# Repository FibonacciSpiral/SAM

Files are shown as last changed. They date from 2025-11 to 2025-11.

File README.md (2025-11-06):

# SAM: Single Channel Temperature Monitor  

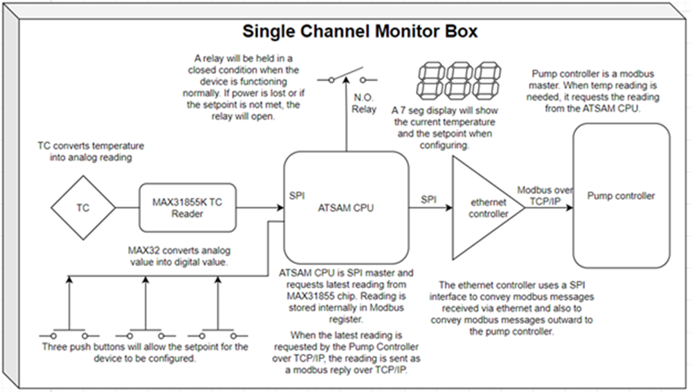
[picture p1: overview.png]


## Overview
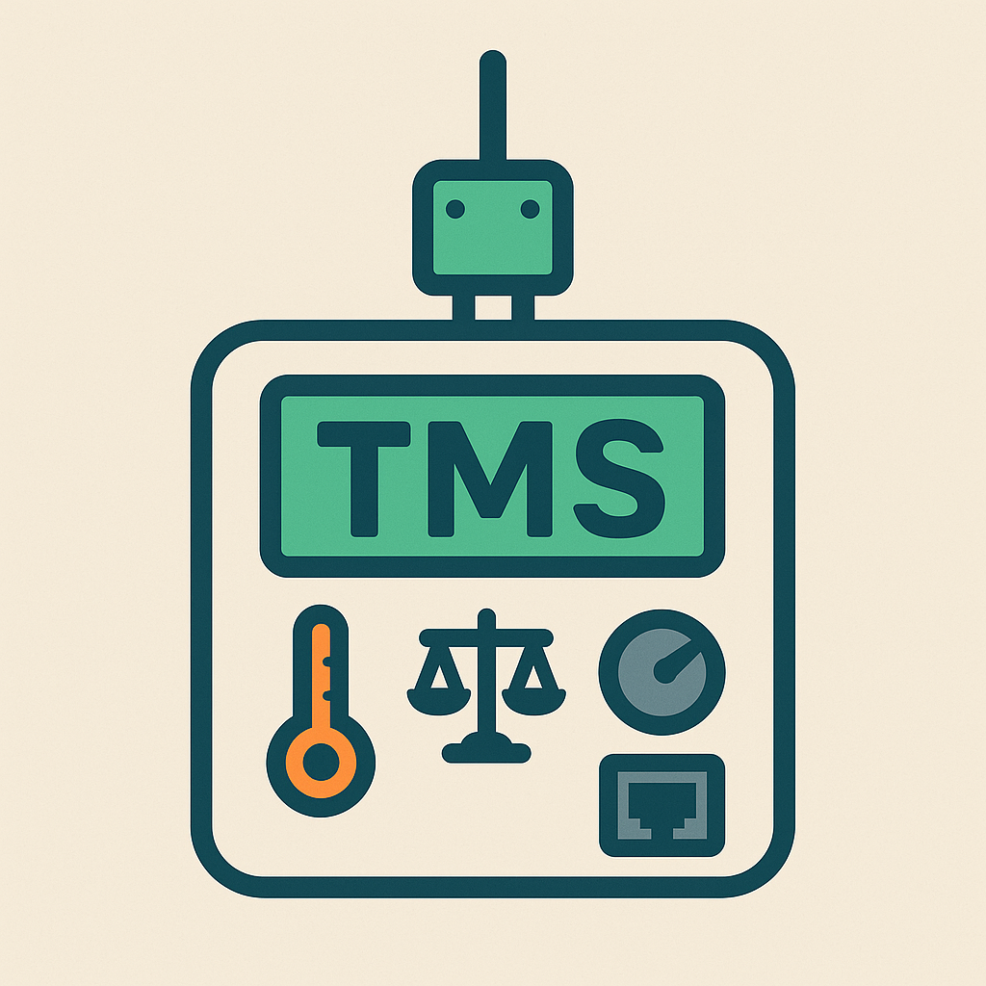
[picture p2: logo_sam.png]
SAM logo

**SAM** (Single-channel Analog Monitor) is a low-cost temperature monitor designed to enable simple temperature monitoring on a variety of TMS heaters. It continuously measures temperature using a Type K thermocouple and alerts operators when the temperature drops below a configured setpoint. The goal is to provide an inexpensive, accurate, and user-friendly thermal monitoring system suitable for industrial or laboratory environments.

## Features
- **Single-channel thermocouple monitoring** via MAX31855K  
- **Configurable setpoint** through a simple 3-button interface (Up, Down, Set)  
- **Real-time temperature display** on a 3-digit seven-segment display  
- **Alert relay output** (N.O. relay circuit) to notify external systems of low-temperature conditions  
- **Modbus TCP/IP server** for remote data retrieval  
- **Web and FTP interfaces** for configuration and resource management  
- **Persistent settings** stored in eMMC non-volatile memory  
- **FreeRTOS-based firmware** using Microchip Studio and ASF (Atmel Software Framework)  

## Hardware Architecture
### Microcontroller
- **MCU Family:** ATSAM4S (ARM Cortex-M4, 120 MHz)  
- **Development Kit:** ATSAM4S Xplained Pro  
- **Networking:** KSZ8851SNL Ethernet controller via SPI  
- **Persistent Storage:** eMMC module (or SD card for prototyping)  

### Sensor Interface
- **Thermocouple Interface Chip:** MAX31855K  
- Provides cold-junction compensation and interfaces with MCU using SPI.

### Display & Input
- **Display:** Three 7-segment LED modules showing real-time temperature or setpoint during configuration.  
- **Buttons:**  
  - **Set:** Enter/exit configuration mode.  
  - **Up/Down:** Adjust setpoint during configuration.  
- **User Feedback:** Flashing display while adjusting setpoint.  

### Relay Output
- **Type:** Normally Open (N.O.) relay  
- **Behavior:**  
  - **High signal:** Normal operation  
  - **Low signal:** Setpoint violation or sensor/power fault  

## Software Architecture
### Operating System
- **RTOS:** FreeRTOS  
- **Language:** C  
- **IDE:** Microchip Studio (Atmel Studio)  

### Modules
#### 1. Temperature Reading
- SPI-based data acquisition from MAX31855K every millisecond for 2 seconds.  
- Average of readings computed for noise reduction.  
- Filtered temperature sent to display, setpoint, and relay tasks.  

#### 2. TCP/IP Stack & Networking
- Based on FreeRTOS+TCP.  
- Includes Ethernet MAC/PHY driver for KSZ8851SNL.  
- Network settings configurable via embedded web server.  

#### 3. Web & FTP Server
- Web interface for IP configuration and device setup.  
- FTP server for uploading web resources (HTML, JS, CSS) stored in eMMC.  

#### 4. Modbus Server
- Implements **Modbus TCP** using the FreeModbus library.  
- Stores current temperature in input register (prototype uses register `1000`).  
- Allows master devices to read temperature remotely.  

#### 5. User Interface Tasks
- **Button Handler:** Interrupt-driven; sends events to state machine task.  
- **Display Driver:** Updates 7-segment display according to operating mode.  
- **Setpoint Task:** Handles setpoint logic, relay control, and NVM storage.  

#### 6. Non-Volatile Memory
- Stores:  
  - Last known setpoint  
  - Network configuration  
  - Web/FTP server resources  
- Implemented with eMMC interface.  

## Development Environment
- **Hardware:** ATSAM4S Xplained Pro + Ethernet1 Xplained Pro extension board  
- **Software:**  
  - Microchip Studio (formerly Atmel Studio)  
  - FreeRTOS  
  - ASF (Atmel Software Framework)  
  - FreeModbus library  

## Prototyping Notes
- SD card may be used as a temporary stand-in for eMMC.  
- Ensure MAX31855K wiring minimizes stray capacitance for accuracy.  
- Software debouncing implemented for all buttons (no hardware debouncing required).  
- Recommended MCU RAM: **≥128kB** (prototype uses 160kB).   

## License
This project is not licensed for redistribution or modification.  
All rights reserved © 2025 Giselle Dockterburke.

## Authors
Software Developed by Giselle Dockterburke at the Hillsboro PC in collaboration with Div Tummala who designed the hardware configuration.

---

**Revision History:**  
See the full svn revision history in the documentation folder.

---

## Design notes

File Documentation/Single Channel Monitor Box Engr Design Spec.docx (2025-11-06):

KEY DOCUMENT

DOCUMENT NO: ISSUE: 0.2

TITLE: Single Channel Monitor Box Engineering Design Specification

DOCUMENT TYPE: ENGINEERING PLAN AND DESIGN

APPROVED BY: DATE: FUNCTION:

Issue No. | 1 | 2
Date Issued | 10/01/2022 | 12/06/2022
Approved
Approved
Approved
Approved

DISTRIBUTION RECORD DOCUMENT NO:

Issue No. | Issued To | Department | Issue Date
1 | Project File Server | HB PC Engineering
2 | Project File Server | HB PC Engineering | 12/06/2022

REVISIONS DOCUMENT NO:

Change No. | Description | Date | New Issue
1 | Initial Version | 10/01/2022 | 1
2 | New Revision | 12/06/2022 | 2
3
4
5

CONTENTS

1. INTRODUCTION
2. RELATED DOCUMENTS
3. OVERVIEW OF DESIGN
4. MCU AND DEVELOPMENT ENVIRONMENT
5. SOFTWARE MODULES
  5.1. A/D CONVERSION FOR THERMOCOUPLE
  5.2. TCP/IP STACK AND NETWORK INTERFACE
    5.2.1. SETTING UP TCP/IP STACK
    5.2.2. ADDING WEB SERVER INTERFACE
    5.2.3. ADDING FTP SERVER
  5.3. MCU AS MODBUS SERVER
  5.4. USER INTERFACE
    5.4.1. BUTTON HANDLER TASK
    5.4.2. 7 SEGMENT TEMPERATURE DISPLAY
  5.5. N.O. RELAY CIRCUIT
  5.6. NON VOLATILE MEMORY
6. CONCLUSION

The single channel monitor box is a low cost way to monitor the temperature of a FLEX heater. It works in series with a FLEX heater solution. It provides a simple three button interface to allow the customer to configure one setpoint. If the current temperature is greater than the setpoint, then that is considered normal. If it’s less than the setpoint, that will generate an alert. The device has a relay circuit that can inform another device of either a setpoint violation or loss of power.

The goal is to design a device that is easy to use, inexpensive, and accurate. Our competitors have such devices so we would also like to consider what these devices are like and to try to make something more desirable.

This document will cover the full design of the device by breaking it down into its parts. Every software module will be detailed, and wiring diagrams will be provided. This document should provide enough information that any developer could use it to design a prototype.

Device datasheet for ATSAM4S family. (https://ww1.microchip.com/downloads/aemDocuments/documents/OTH/ProductDocuments/DataSheets/Atmel-11100-32-bitCortex-M4-Microcontroller-SAM4S_Datasheet.pdf)

Single Channel Monitor Box Marketing Spec (https://onevirtualoffice.sharepoint.com/:x:/r/sites/SEM_EDW_GLO_SMARTTMSHUB/Shared%20Documents/Organizational/Former%20Employee%20Files/Div%20Tummala%20Files/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)

Single Channel Monitor Box Scheduling Timeline (https://onevirtualoffice-my.sharepoint.com/:w:/g/personal/giselle_dockterburke_edwardsvacuum_com/Ef9K2PLwa2lMu9C9id5GHWMBOkV-AMopPGUyMcQtvdPQiQ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)

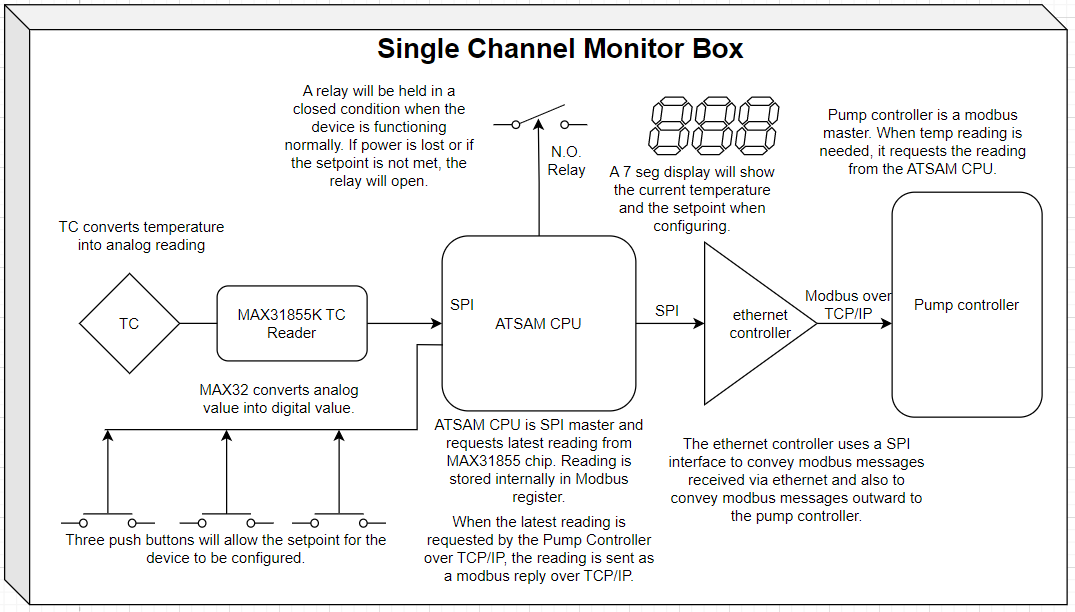
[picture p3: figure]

The single channel monitor box will monitor a single thermocouple. Temperature readings are converted by a MAX31855K chip and received by the MCU via SPI. Readings are stored internally until a modbus master device requests them. The requests are received through an ethernet port that communicates modbus over TCP/IP. The monitor box acts as a modbus server, only storing the latest reading in an internal register.

Whatever the current temperature is, that is displayed on the device’s seven segment display. The device has only 1 setpoint that can be configured using the three push buttons provided. While configuring, the display will show the user the setpoint temperature as they are selecting it.

If the setpoint is violated (if the current reading is less than the setpoint), then a relay will open, allowing an interfacing device to be notified of the problem.

4. Mcu and Development environment

The microcontroller family selected for this project is the ATSAM4S family of microcontrollers. The full specs for this family are found in their device datasheet linked in the related documents section, but in summary, it is a 32 bit ARM Cortex-M4 processor with an internal clock speed of 120 MHz (ample speed for this application), with a good selection of peripherals and multiple packages ranging from 48 I/O pins and 100 I/O pins.

Here is a complete list of the specs for this MCU:

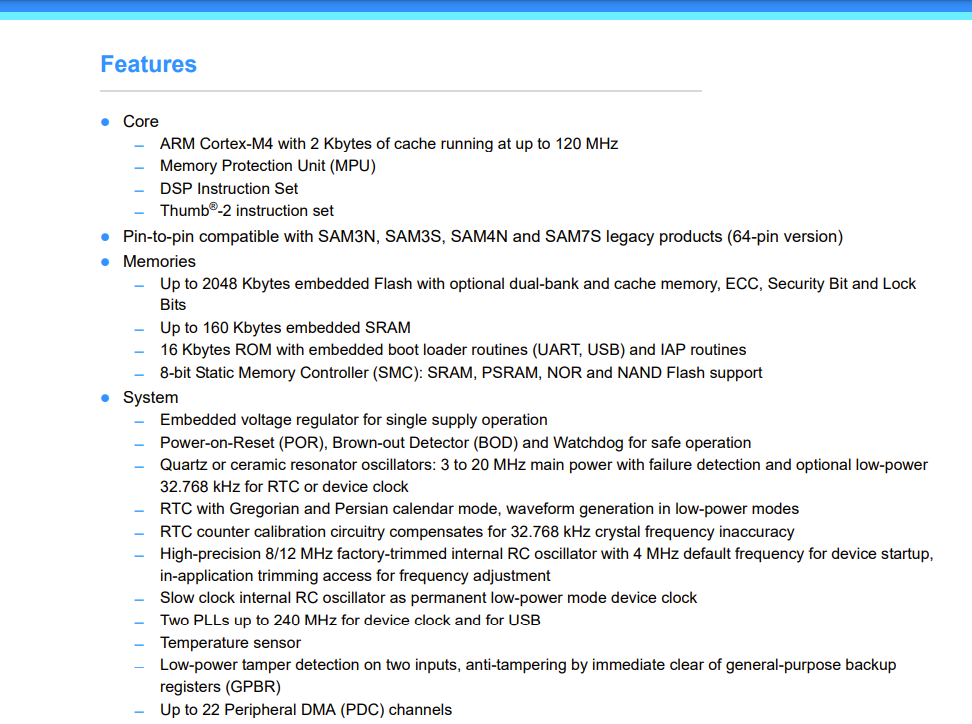
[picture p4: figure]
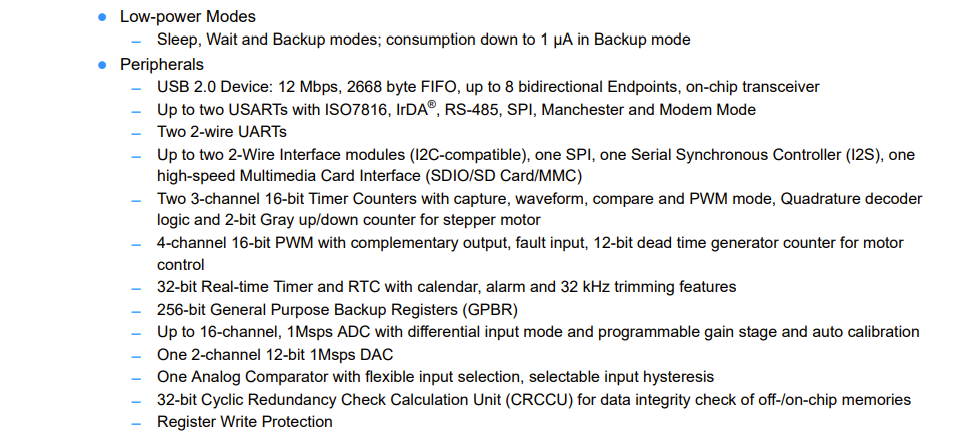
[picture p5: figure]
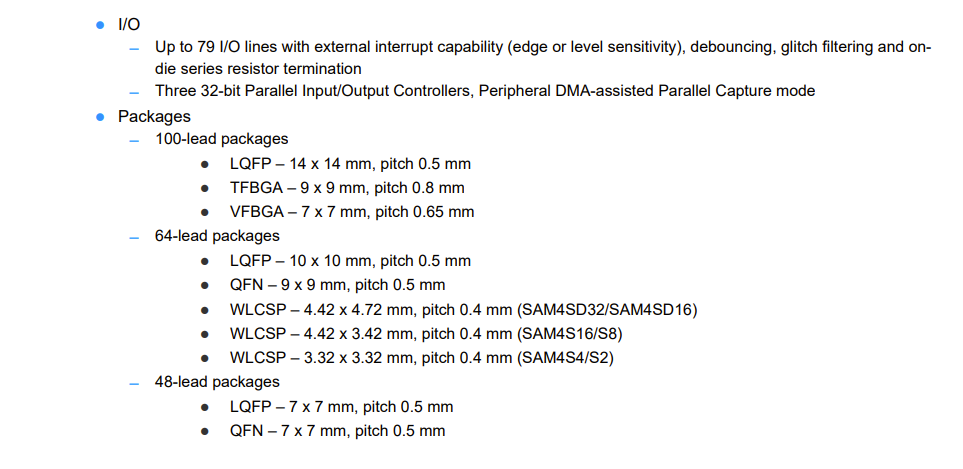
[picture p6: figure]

The development board selected for prototyping is the ATSAM4S Xplained Pro kit.

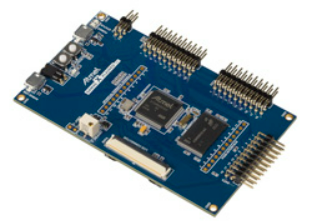
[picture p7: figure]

Here is a link to the product and its description. ATSAM4S Development Board (https://www.microchip.com/en-us/development-tool/ATSAM4S-XPRO)

The integrated development environment this MCU uses is Microchip studio (formerly Atmel Studio). The software itself will run in a FreeRTOS operating system. The software will be written in C and debugging is easily accomplished over USB with Microchip studio. The development board comes preloaded with a debugging module that makes the process very simple. The ASF wizard in Microchip studio can be used to setup FreeRTOS and many of the low level drivers like the Power Management Controller and SPI.

5. SOFTWARE MODULES

5.1. TEMPERATURE READING WITH MAX31855K

The MAX31855 chip provides a convenient method to read temperatures using a thermocouple. This chip comes in different varieties to suit different types of thermocouples. Since this application will use type K thermocouples, the MAX31855K will be used.

Essentially, the chip handles all the complexity involved with cold junction compensation that normally has to be handled when reading thermocouples. The chip generates readings frequently and they only need to be clocked out by a master SPI device.

In this application, the MAX TC reader will be read once per millisecond for 2 whole seconds. All of the readings will be averaged to provide a software based noise filter. The temperature is read by asserting the devices chip select, clocking out the bits, and then interpreting the current temperature using the data format provided by the MAX31855 datasheet.

Once a temperature is averaged and calculated, it will be sent to other tasks for processing. For example the display driver will be a recipient since it will need to know what to display, and the setpoint handler will need it since it will always be monitoring the current temperature for an alert scenario.

5.2. TCP/IP STACK AND NETWORK INTERFACE

    5.2.1 SETTING UP TCP/IP STACK

The ethernet module provides the hardware capability for an ethernet connection, but it also needs supporting software in FreeRTOS. This design will use the TCP/IP stack native to FreeRTOS, however there are other components to consider in the software framework. Here is a visual representation of the structure that needs to be implemented:

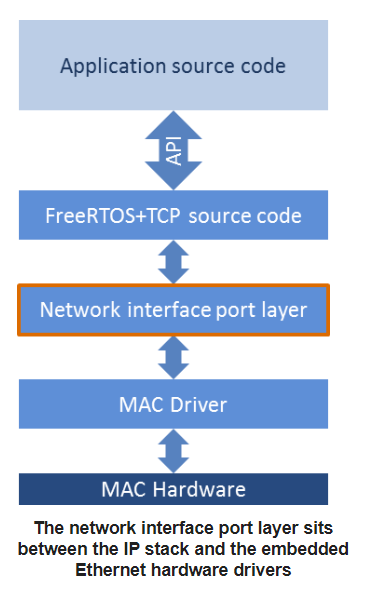
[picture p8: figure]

At the bottom of the stack is the ethernet chip itself. It is known as the MAC. On top of that is the MAC Driver. This is also known as the PHY or Physical Layer Transceiver. It provides the interface between the hardware and the network interface port layer.

In this application the PHY can be easily obtained from the ASF wizard in Microchip studio. Whatever ethernet chip is being used, ASF wizard can likely provide it as a component in the project. For the prototype, we are using the KSZ8851SNL which has a PHY driver available in ASF wizard.

If for some reason, the PHY is not provided in Microchip studio, then one can likely be located on Github. The worst case scenario is one would need to be written manually. This would simply consume time; it’s still very feasible.

The next layer is the network interface port layer. This essentially provides the glue that binds the TCP/IP stack to the PHY.

- The network interface port layer must provide a function called xNetworkInterfaceInitialise() (https://www.freertos.org/FreeRTOS-Plus/FreeRTOS_Plus_TCP/Embedded_Ethernet_Porting.html) that initializes the MAC driver.
- The network interface port layer must provide a function called xNetworkInterfaceOutput() (https://www.freertos.org/FreeRTOS-Plus/FreeRTOS_Plus_TCP/Embedded_Ethernet_Porting.html) that sends data received from the embedded TCP/IP stack to the Ethernet MAC driver for transmission.
- The network interface port layer must send packets received from the Ethernet MAC driver to the TCP/IP stack by calling xSendEventStructToIPTask() (https://www.freertos.org/FreeRTOS-Plus/FreeRTOS_Plus_TCP/API/xSendEventStructToIPTask.html).

What’s nice about the TCP/IP stack in FreeRTOS is it allows the code to be highly portable. The only code that would need to be changed in the event of changing ethernet chips is the PHY and the network interface port layer.

Here is a link to more information on setting up the TCP/IP stack and hardware interface:

Porting FreeRTOS-Plus-TCP to a Different Microcontroller (https://www.freertos.org/FreeRTOS-Plus/FreeRTOS_Plus_TCP/Embedded_Ethernet_Porting.html)

    5.2.2 ADDING WEB SERVER INTERFACE

A requirement of the project is for the IP address to be configurable. In order to meet this requirement, the monitor box will host a local web server that will allow the IP address and other relevant network settings to be modified.

The host name of the server can be entered into any address bar and as long as there is a direct network connection between the monitor box and a host computer, then the web service will display the interface over http.

From a high level, the interface will be simple and allow for easy device customization.

From a design perspective, the web server functionality will be added by porting an existing example for the ATSAM4E line of devices. The main difference between ATSAM4E and ATSAM4S family of microcontrollers is that ATSAM4E has a built in MAC. Since we are adding an external MAC (the ethernet chip), this example should work on ATSAM4S, provided the TCP/IP stack is ported successfully.

Here is a link to the ATSAM4E http example (and other examples too).

FreeRTOS-Plus-TCP and FreeRTOS-Plus-FAT Examples (https://www.freertos.org/FreeRTOS-Plus/FreeRTOS_Plus_TCP/TCPIP_FAT_Examples_Atmel_SAM4E.html)

    5.2.3 ADDING FTP SERVER

An FTP server will be implemented alongside the web server interface since it would be necessary to have a way to place the web resources onto the device. The ATSAM4E example mentioned above essentially bundles the web server with the ftp server since they are so similar. If that example is implemented correctly, then the FTP server will be added alongside the web interface without additional effort.

5.3. MCU AS MODBUS SERVER

A modbus server is a device that accepts commands from a modbus master. Modbus is an application layer protocol that sits on top of the TCP/IP stack.

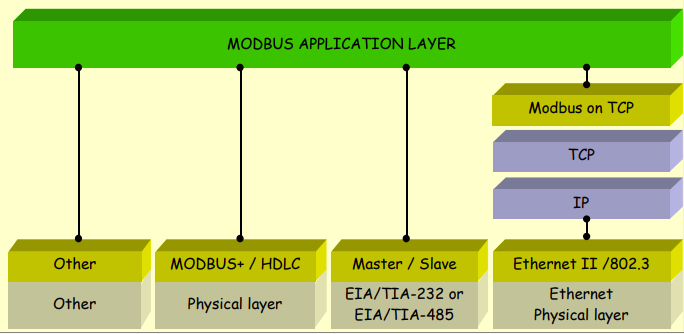
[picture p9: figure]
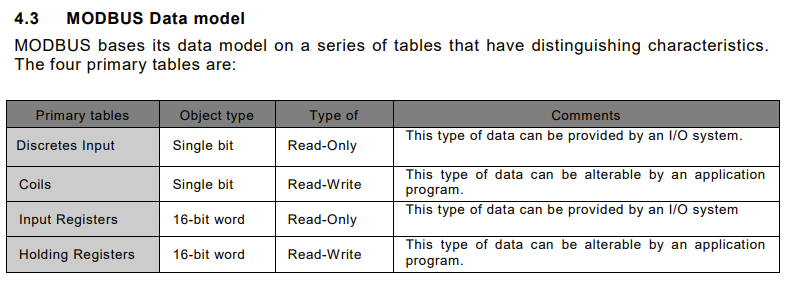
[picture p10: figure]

The best way to add modbus as an application layer protocol is to port an existing library that is tried and true. An excellent option is freeModbus. This library is made for embedded systems, it is well written, and is made for porting. They provide TCP implementations and RTU/ASCII. This could be useful for another project in the future that also uses modbus but not the TCP version. The code could easily be configured to work with TCP or Serial.

In order to add freemodbus to an application, one would download the library from their website. There is a port file that shows function stubs for functions that must be implemented. The only ones needed for the TCP port are labeled under the TCP section.

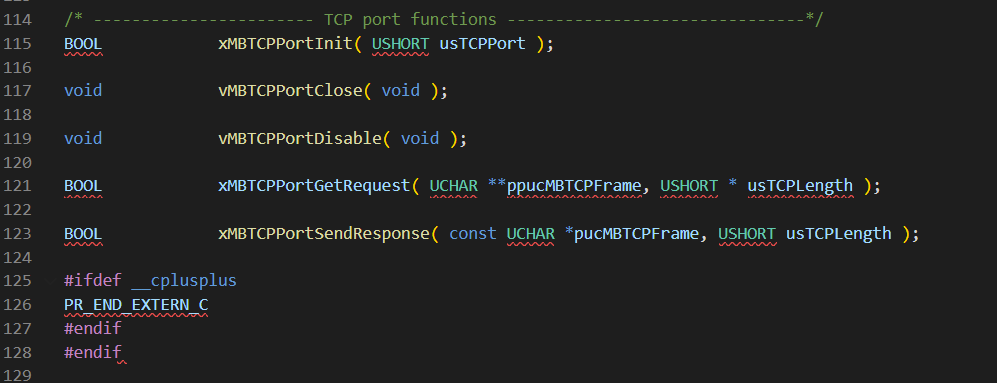
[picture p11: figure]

The xMBTCPPortInit function is responsible for launching a connection listening task. It’s only goal is to listen for clients. This task will also only handle one connection at a time so if a second client tries to connect, the current connection is severed.

The vMBTCPPortClose function completely closes down the modbus interface by killing any active connection and shutting down the listening socket.

The MBTCPPortDisable function will only shut down any active connection.

xMBTCPPortGetRequest is a function used to receive messages from the remote client. This function stub just provides a pointer for one to copy an address to. This address should point to the most recently received data along with the number of bytes. In the application, the connection instance will be responsible for reading data from the client and sending the address of the data over in a queue.

Then, once free modbus is fully implemented, it can be tested with a modbus master simulator like qModMaster. We use this for testing the TMS controller’s modbus interface.

The only additional work is to decide which input register should hold the current temperature. I will use 1000 for prototyping. If any other parameters should be available via modbus, we would just dedicate an input register, or holding register if the master is allowed to write, and keep it updated that way the values are always available.

5.4. USER INTERFACE

The user interface consists of three push buttons and 3 seven-segment display modules. There’s an up button, a down button, and a set button. The display modules always reflect the current temperature reading. The only other function of the display is to allow a single setpoint to be set. To change the setpoint, the set button should be pushed once. At this point, the display will slowly flash indicating that the setpoint may be adjusted. Pushing the set button again will save whatever setpoint they had selected using the up and down buttons. The device ceases to blink and shows the current temperature, signaling that normal operation has resumed.

5.4.1. BUTTON HANDLER TASK

An ISR will be used to monitor the input on the buttons asynchronously. Those inputs will be sent to a state machine task that will then send any requests to the control task, such as changing the display or updating a setpoint.

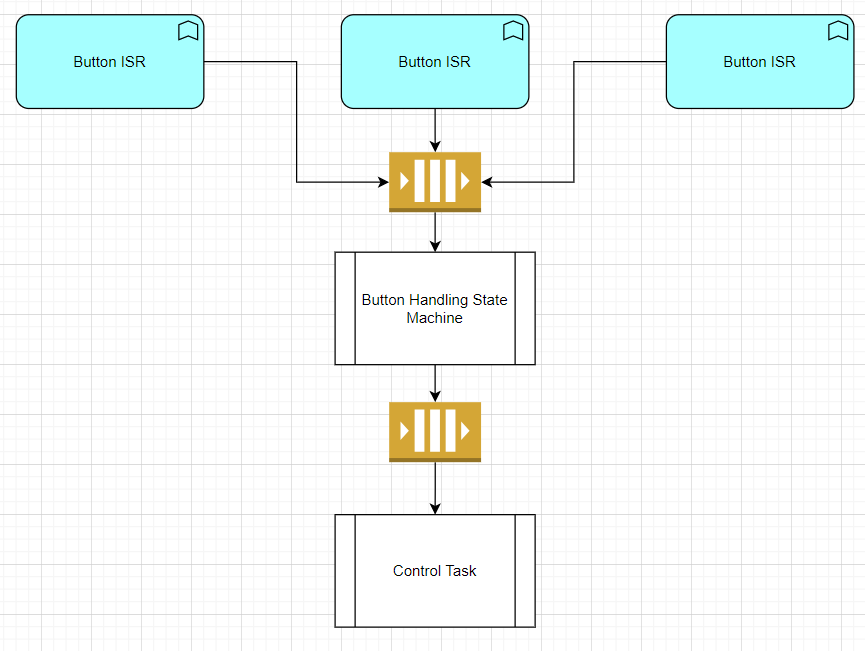
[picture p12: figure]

5.4.2. 7 SEGMENT TEMPERATURE DISPLAY

The display logic will follow a state machine behavior as outlined below:

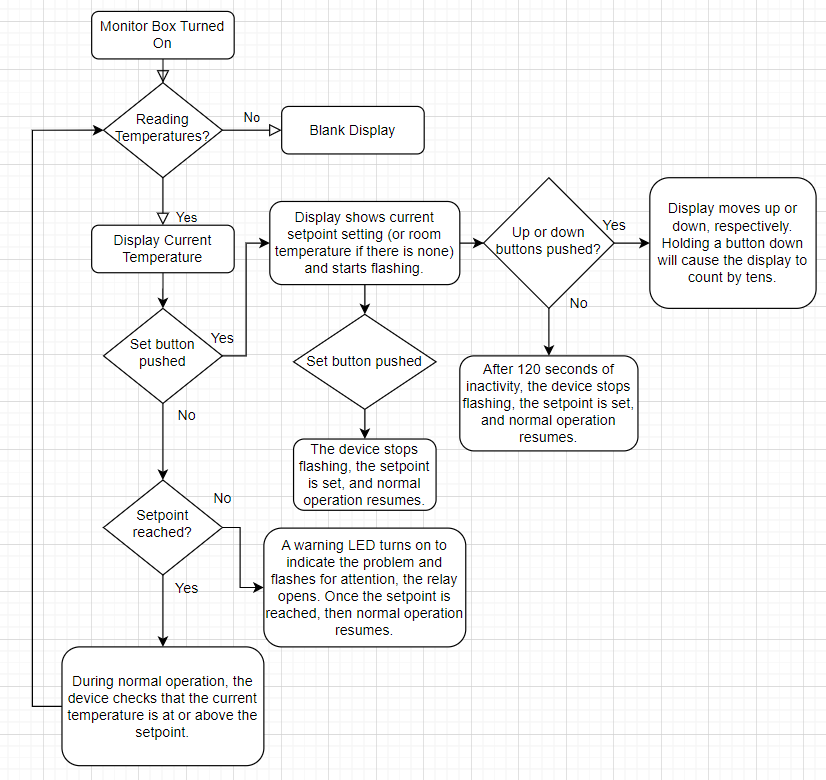
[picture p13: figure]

5.5. N.O. RELAY CIRCUIT

This is probably the most simple software module. If the monitor box is on but either cannot read temperatures or if the setpoint is violated, then a digital low signal will be applied to a digital output. If everything is normal, then a digital high signal will be output from the same GPIO.

The setpoint handling itself should have its own task where the current temperature is relayed to it every time it comes in via a queue. This task will be responsible for monitoring the temperature and will follow a state machine style architecture to handle the state of the relay. This task should also be responsible for storing the setpoint in non-volatile memory when it is selected, and for retrieving the last known setpoint on initialization.

5.6 NON VOLATILE MEMORY

There is a need for persistent memory in this project. The setpoint must be remembered between power cycles, and in order to implement a web server, there must be a file system to store web resources such as http files, javascript files, or css files. Not only that, but the network settings must be remembered between power cycles as well. In order to address this problem in the most cost effective way, this project will use an eMMC module. eMMC stands for embedded multi-media card. It is almost identical to an SD card but it is non removable and significantly less expensive.

On the prototype, the wiring for the project is exceedingly simple, given that an extension board for the ATSAM4S development board exists. The extension is the Ethernet1 Xplained Pro board and for the prototype, it plugs into EXT1, although it should be compatible on any of the boards extensions. (No wiring diagram needed).

6. CONCLUSION

This is the plan for the design of the software. There are still some lingering questions. Which modbus register should the current temperature reside at? What other variables would be good to make accessible via modbus? Should the web server be HTTP or HTTPS? HTTP would be faster, but obviously HTTPS is encrypted so it would be more secure. Is security of great importance here? Or is speed the priority?

There are other considerations concerning the hardware also. Technically, any CPU may be used for this project as long as it is in the ATSAM4S family. However, RAM must be considered. I would recommend to those developing the hardware to choose a CPU with no less than 128kB of RAM. The application will be developed using a CPU with 160kB so a CPU with that amount would be most likely to work successfully without additional troubleshooting.

One consideration is the eMMC module. For prototyping, an SD card and SD card reader will be used, but it would be ideal to be able to prototype with an eMMC module as well. When a module is selected, it is important that it is tested for compatibility with the software driver. It is the case that certain modules are compatible while others are not, depending on the interface that is used.

Also, the MAX31855 module is highly sensitive to stray capacitance so when designing the layout of the PCB, that must be considered, otherwise the temperature readings may not be very accurate. The way the chip reads temperature is based on voltages so it is essential that stray inductance or capacitance don’t disrupt those readings.

One more thing to add is that the buttons will be debounced entirely in software so there is no need to add any additional hardware for debouncing.

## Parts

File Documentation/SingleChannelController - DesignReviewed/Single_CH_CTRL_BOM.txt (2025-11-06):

Qty Value                    Device                   Package                        Parts                                                                                                                                                                                 Description                                                                                                                                                                                                  ARROW_PART_NUMBER   ARROW_PRICE-STOCK                                                                      DESCRIPTION                                                                                                                                                                                                  HEIGHT   MANUFACTURER_NAME  MANUFACTURER_PART_NUMBER MOUSER_PART_NUMBER   MOUSER_PRICE-STOCK                                                                                                     MOUSER_TESTING_PART_NUMBER MOUSER_TESTING_PRICE-STOCK
1   0.1uF                    B32922X2104K000          B32922X_(18_X_5)               C1                                                                                                                                                                                    EMI Suppression Capacitors, 0.1uF, 275Vrms AC, 5m(W) x 10.5m(H) x 18m(L)                                                                                                                                     B32922X2104K000     https://www.arrow.com/en/products/b32922x2104k000/epcos-tdk?region=nac                 EMI Suppression Capacitors, 0.1uF, 275Vrms AC, 5m(W) x 10.5m(H) x 18m(L)                                                                                                                                     10.5mm   TDK                B32922X2104K000          871-B32922X2104K000  https://www.mouser.co.uk/ProductDetail/EPCOS-TDK/B32922X2104K000?qs=TuK3vfAjtkWDVip5zaCELA%3D%3D                                                                            
2   0.1uF                    C0402C104K4RACTU         C0402                          C16, C17                                                                                                                                                                              SMD Comm X7R, Ceramic, 0.1 uF, 10%, 16 VDC, 40 VDC, 125C, -55C, X7R, SMD, MLCC, Temperature Stable, Class II, 10 % , 5 GOhms, 1.21 mg, 0402, 1mm, 0.5mm, 0.5mm, 0.3mm, 0.3mm, 10000, 78  Weeks, 80           C0402C104K4RACTU    https://www.arrow.com/en/products/c0402c104k4ractu/kemet-corporation?region=nac        SMD Comm X7R, Ceramic, 0.1 uF, 10%, 16 VDC, 40 VDC, 125C, -55C, X7R, SMD, MLCC, Temperature Stable, Class II, 10 % , 5 GOhms, 1.21 mg, 0402, 1mm, 0.5mm, 0.5mm, 0.3mm, 0.3mm, 10000, 78  Weeks, 80           0.55mm   KEMET              C0402C104K4RACTU         80-C0402C104K4R      https://www.mouser.co.uk/ProductDetail/KEMET/C0402C104K4RACTU?qs=DBJr%252BvBUjU54jK7d4uAeew%3D%3D                                                                           
1   0.1uF                    C0805C104K5RAC7411       CAPC2012X88N                   C28                                                                                                                                                                                   Cap Ceramic 0.1uF 50V X7R 10% Pad SMD 0805 125C T/R                                                                                                                                                          C0805C104K5RAC7411  https://www.arrow.com/en/products/c0805c104k5rac7411/kemet-corporation                 Cap Ceramic 0.1uF 50V X7R 10% Pad SMD 0805 125C T/R                                                                                                                                                          0.88mm   KEMET              C0805C104K5RAC7411       80-C0805C104K5RACLR  https://www.mouser.co.uk/ProductDetail/KEMET/C0805C104K5RAC7411?qs=jbRM9o5BbzPcVXF0wW9AYg%3D%3D                                                                             
1   0.5A Slow Blow           RST_500_AMMO             RST500AMMO                     F1                                                                                                                                                                                    Fuse Micro Slow Blow Acting 0.5A 250V Radial 8.35 X 4 X 8.2mm Ammo CCC/PSE/SEMKO/VDE/cULus                                                                                                                   RST 500 AMMO        https://www.arrow.com/en/products/rst500-ammo/bel-group                                Fuse Micro Slow Blow Acting 0.5A 250V Radial 8.35 X 4 X 8.2mm Ammo CCC/PSE/SEMKO/VDE/cULus                                                                                                                   7.9mm    Stewart Connector  RST 500 AMMO             530-RST500AMMO       https://www.mouser.co.uk/ProductDetail/Bel-Fuse/RST-500-AMMO?qs=MvPYbBWWJyujgJzBtIxlxw%3D%3D                                                                                
1   100                      ERJ-PA3F1000V            ERJP03_PA3_(0603)              R29                                                                                                                                                                                   ERJPA3 Resistors 0.25W 0603 100R 1% Panasonic ERJPA3 Series Thick Film Surface Mount Resistor 0603 Case 100 +/-1% 0.25W +/-100ppm/C                                                                                                                                                                                     ERJPA3 Resistors 0.25W 0603 100R 1% Panasonic ERJPA3 Series Thick Film Surface Mount Resistor 0603 Case 100 +/-1% 0.25W +/-100ppm/C                                                                          0.55mm   Panasonic          ERJ-PA3F1000V            667-ERJ-PA3F1000V    https://www.mouser.com/Search/Refine.aspx?Keyword=667-ERJ-PA3F1000V                                                                                                         
1   1000pF                   C4520X7R3D102K130KA      C4520_COMMERCIAL               C18                                                                                                                                                                                   MULTILAYER CERAMIC CHIP CAPACITORS, 4520, Commercial grade, general (Up to 75V)                                                                                                                              C4520X7R3D102K130KA https://www.arrow.com/en/products/c4520x7r3d102k130ka/tdk                              MULTILAYER CERAMIC CHIP CAPACITORS, 4520, Commercial grade, general (Up to 75V)                                                                                                                              1mm      TDK                C4520X7R3D102K130KA      810-C4520X7R3D102K   https://www.mouser.co.uk/ProductDetail/TDK/C4520X7R3D102K130KA?qs=NRhsANhppD%2FmDDEB06mgKg%3D%3D                                                                            
31  10K                      CRCW040210K0FKEDC        RESC1005X35N                   R30, R31, R34, R114, R117, R120, R123, R126, R129, R132, R135, R138, R141, R144, R147, R150, R153, R156, R159, R162, R165, R168, R171, R174, R177, R180, R183, R186, R189, R192, R195 VISHAY - CRCW040210K0FKEDC - RES, THICK FILM, 10K, 0.063W, 0402                                                                                                                                              CRCW040210K0FKEDC   https://www.arrow.com/en/products/crcw040210k0fkedc/vishay?region=nac                  VISHAY - CRCW040210K0FKEDC - RES, THICK FILM, 10K, 0.063W, 0402                                                                                                                                              0.35mm   Vishay             CRCW040210K0FKEDC        71-CRCW040210K0FKEDC https://www.mouser.co.uk/ProductDetail/Vishay-Dale/CRCW040210K0FKEDC?qs=E3Y5ESvWgWPiNLcGzwCGPg%3D%3D                                                                        
1   10K                      RC0402FR-0710KP          RESC1005X40N                   R59                                                                                                                                                                                   YAGEO - RC0402FR-0710KP - SMD Chip Resistor, 10 kohm, +/- 1%, 62.5 mW, 0402 [1005 Metric], Thick Film, General Purpose                                                                                       RC0402FR-0710KP     https://www.arrow.com/en/products/rc0402fr-0710kp/yageo?region=nac                     YAGEO - RC0402FR-0710KP - SMD Chip Resistor, 10 kohm, +/- 1%, 62.5 mW, 0402 [1005 Metric], Thick Film, General Purpose                                                                                       0.4mm    KEMET              RC0402FR-0710KP          603-RC0402FR-0710KP  https://www.mouser.co.uk/ProductDetail/YAGEO/RC0402FR-0710KP?qs=oypCK0zG325Ov8hhvMZZMg%3D%3D                                                                                
2   18pF                     04025U180FAT2A           CAPC1005X56N                   C3, C4                                                                                                                                                                                AVX - 04025U180FAT2A - CAP, MLCC, C0G / NP0, 18PF, 50V, 0402                                                                                                                                                 04025U180FAT2A      https://www.arrow.com/en/products/04025u180fat2a/avx                                   AVX - 04025U180FAT2A - CAP, MLCC, C0G / NP0, 18PF, 50V, 0402                                                                                                                                                 0.56mm   AVX                04025U180FAT2A           581-04025U180FAT2A   https://www.mouser.co.uk/ProductDetail/AVX/04025U180FAT2A/?qs=lqAf%2FiVYw9iIZ7dTMzpUiQ%3D%3D                                                                                
1   1M                       CHV0805-FX-1004EST       RESC2012X60N                   R57                                                                                                                                                                                   ResHV ST 0805 1M 1% 0.125W TCR100                                                                                                                                                                                                                                                                                       ResHV ST 0805 1M 1% 0.125W TCR100                                                                                                                                                                            0.6mm    Bourns             CHV0805-FX-1004EST       652-CHV0805FX1004EST https://www.mouser.co.uk/ProductDetail/Bourns/CHV0805-FX-1004EST?qs=QNEnbhJQKvb69hgGpv9kmQ%3D%3D                                                                            
29  220                      CR0402-JW-221GLF         RESC1005X40N                   R55, R56, R116, R119, R122, R125, R128, R131, R134, R137, R140, R143, R146, R149, R152, R155, R158, R161, R164, R167, R170, R173, R176, R179, R182, R188, R191, R194, R197            Thick Film Resistors - SMD 220 OHM 5%                                                                                                                                                                        CR0402-JW-221GLF    https://www.arrow.com/en/products/cr0402-jw-221glf/bourns                              Thick Film Resistors - SMD 220 OHM 5%                                                                                                                                                                        0.4mm    Bourns             CR0402-JW-221GLF         652-CR0402JW-221GLF  https://www.mouser.com/Search/Refine.aspx?Keyword=652-CR0402JW-221GLF                                                                                                       
1   220uF                    860010473011             CAPPRD250W52D630H1250          C2                                                                                                                                                                                    Wurth Elektronik 220uF 25 V dc Aluminium Electrolytic Capacitor, WCAP-ATG8 Series 2000h 6.3 (Dia.) x 11mm                                                                                                                                                                                                               Wurth Elektronik 220uF 25 V dc Aluminium Electrolytic Capacitor, WCAP-ATG8 Series 2000h 6.3 (Dia.) x 11mm                                                                                                    12.5mm   Wurth Elektronik   860010473011             710-860010473011     https://www.mouser.co.uk/ProductDetail/Wurth-Elektronik/860010473011?qs=0KOYDY2FL2%252Bm07azjhm%2FHQ%3D%3D                                                                  
2   22pF                     CBR04C220J5GAC           CBR04C                         C19, C20                                                                                                                                                                              CBR-SMD RF C0G, Ceramic, 22 pF, 5%, 50 VDC, 125 VDC, 125C, -55C, C0G, SMD, Fixed, RF, Ultra High Q, Low ESR, Class I, 0.12 % , 10 GOhms, 840, 1.4 mg, 0402, 1mm, 0.5mm, 0.5mm, 0.25mm, 10000, 78  Weeks, 120 CBR04C220J5GAC      https://www.arrow.com/en/products/cbr04c220j5gac/kemet-corporation?region=nac          CBR-SMD RF C0G, Ceramic, 22 pF, 5%, 50 VDC, 125 VDC, 125C, -55C, C0G, SMD, Fixed, RF, Ultra High Q, Low ESR, Class I, 0.12 % , 10 GOhms, 840, 1.4 mg, 0402, 1mm, 0.5mm, 0.5mm, 0.25mm, 10000, 78  Weeks, 120 mm       KEMET              CBR04C220J5GAC           80-CBR04C220J5G      https://www.mouser.co.uk/ProductDetail/KEMET/CBR04C220J5GAC?qs=BjUX18ghZXi0endstTtQyQ%3D%3D                                                                                 
28  2K2                      CR0402-FX-2201GLF        RESC1005X37N                   R115, R118, R121, R124, R127, R130, R133, R136, R139, R142, R145, R148, R151, R154, R157, R160, R163, R166, R169, R172, R175, R178, R181, R184, R187, R190, R193, R196                BOURNS - CR0402-FX-2201GLF - RES, 2K2, 1%, 0402, THICK FILM                                                                                                                                                  CR0402-FX-2201GLF   https://www.arrow.com/en/products/cr0402-fx-2201glf/bourns?region=nac                  BOURNS - CR0402-FX-2201GLF - RES, 2K2, 1%, 0402, THICK FILM                                                                                                                                                  0.37mm   Bourns             CR0402-FX-2201GLF        652-CR0402FX-2201GLF https://www.mouser.co.uk/ProductDetail/Bourns/CR0402-FX-2201GLF?qs=JflQ4L8so%2FvNNp%252Bb%2FjYwIg%3D%3D                                                                     
28  2SA1362-GR,LF            2SA1362-GR,LF            2SA1362GRLF                    IC27, IC28, IC29, IC30, IC31, IC32, IC33, IC34, IC35, IC36, IC37, IC38, IC39, IC40, IC41, IC42, IC43, IC44, IC45, IC46, IC47, IC48, IC49, IC50, IC51, IC52, IC53, IC54                PNP Transistor, VCEO=-15V, IC=-0.8A, hFE=200 to 400 in SOT-346   (S-Mini) package                                                                                                                                                                                                                                       PNP Transistor, VCEO=-15V, IC=-0.8A, hFE=200 to 400 in SOT-346   (S-Mini) package                                                                                                                            1.4mm    Toshiba            2SA1362-GR,LF            757-2SA1362-GRLF     https://www.mouser.co.uk/ProductDetail/Toshiba/2SA1362-GRLF?qs=bZr6mbWTK5kLJ9eOLrMUZg%3D%3D                                                                                 
1   3.01K                    RC0402FR-073K01L         RESC1005X40N                   R58                                                                                                                                                                                   Thick Film Resistors - SMD 3.01K OHM 1%                                                                                                                                                                      RC0402FR-073K01L    https://www.arrow.com/en/products/rc0402fr-073k01l/yageo                               Thick Film Resistors - SMD 3.01K OHM 1%                                                                                                                                                                      0.4mm    KEMET              RC0402FR-073K01L         603-RC0402FR-073K01L https://www.mouser.com/Search/Refine.aspx?Keyword=603-RC0402FR-073K01L                                                                                                      
3   39                       CR0402-FX-39R0GLF        RESC1005X40N                   R32, R33, R35                                                                                                                                                                         Thick Film Resistors - SMD 39 OHM 1%                                                                                                                                                                                                                                                                                    Thick Film Resistors - SMD 39 OHM 1%                                                                                                                                                                         0.4mm    Bourns             CR0402-FX-39R0GLF        652-CR0402FX-39R0GLF https://www.mouser.com/Search/Refine.aspx?Keyword=652-CR0402FX-39R0GLF                                                                                                      
2   4.7K                     CR0402-FX-4701GLF        RESC1005X40N                   R60, R61                                                                                                                                                                              Thick Film Resistors - SMD 4.7K OHM 1%                                                                                                                                                                                                                                                                                  Thick Film Resistors - SMD 4.7K OHM 1%                                                                                                                                                                       0.4mm    Bourns             CR0402-FX-4701GLF        652-CR0402FX-4701GLF https://www.mouser.co.uk/ProductDetail/Bourns/CR0402-FX-4701GLF?qs=ePR1ZvdkOKK%252Bab9lx6TEtw%3D%3D                                                                         
4   49.9                     ERJ-U02F49R9X            ERJS02_U02_(0402)              R51, R52, R53, R54                                                                                                                                                                    Anti-Sulfurated Thick Film Chip Resistor, 0402, 0.1W                                                                                                                                                                                                                                                                    Anti-Sulfurated Thick Film Chip Resistor, 0402, 0.1W                                                                                                                                                         0.4mm    Panasonic          ERJ-U02F49R9X                                                                                                                                                                                                             
2   5055323-9                5055323-9                50553239                       U2, U3                                                                                                                                                                                AMP - TE CONNECTIVITY - 5055323-9 - POWER TAB, ASSEMBLY, WITH SCREW                                                                                                                                          5055323-9           https://www.arrow.com/en/products/5055323-9/te-connectivity                            AMP - TE CONNECTIVITY - 5055323-9 - POWER TAB, ASSEMBLY, WITH SCREW                                                                                                                                          7.2898mm TE Connectivity    5055323-9                571-5055323-9        https://www.mouser.co.uk/ProductDetail/TE-Connectivity/5055323-9?qs=Ko7makLHeK5WcBiq4KwKgA%3D%3D                                                                            
2   74HC14D                  74HC14D                  SOIC127P600X175-14N            IC2, IC18                                                                                                                                                                             Inverter Schmitt Trigger 6-Element CMOS 14-Pin SOIC T/R                                                                                                                                                      74HC14D             https://www.arrow.com/en/products/74hc14d/toshiba?region=nac                           Inverter Schmitt Trigger 6-Element CMOS 14-Pin SOIC T/R                                                                                                                                                      1.75mm   Toshiba            74HC14D                  757-74HC14D          https://www.mouser.co.uk/ProductDetail/Toshiba/74HC14D?qs=y6ZabgHbY%252BwfUBrwO9UV%252Bg%3D%3D                                                                              
1   ATSAM4S2AB-ANR           ATSAM4S2AB-ANR           QFP50P900X900X160-48N          IC16                                                                                                                                                                                  ARM Microcontrollers - MCU 48LQFP,GREEN,EXT TEMP(105C),MRL B,128K FLASH,64K SRAM                                                                                                                             ATSAM4S2AB-ANR      https://www.arrow.com/en/products/atsam4s2ab-anr/microchip-technology                  ARM Microcontrollers - MCU 48LQFP,GREEN,EXT TEMP(105C),MRL B,128K FLASH,64K SRAM                                                                                                                             1.6mm    Microchip          ATSAM4S2AB-ANR           556-ATSAM4S2AB-ANR   https://www.mouser.co.uk/ProductDetail/Microchip-Technology-Atmel/ATSAM4S2AB-ANR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                                                      
1   BAS16                    BAS16                    SOT95P240X110-3N               D1                                                                                                                                                                                    Small signal diode,BAS16 0.25A 85V Infineon BAS16, SMT Switching Diode, 85V 250mA, 4ns, 3-Pin SOT-23                                                                                                                                                                                                                    Small signal diode,BAS16 0.25A 85V Infineon BAS16, SMT Switching Diode, 85V 250mA, 4ns, 3-Pin SOT-23                                                                                                         1.1mm    Infineon           BAS16                                                                                                                                                                                                                     
1   CR0402-JW-221GLF         CR0402-JW-221GLF         RESC1005X40N                   R185                                                                                                                                                                                  Thick Film Resistors - SMD 220 OHM 5%                                                                                                                                                                        CR0402-JW-221GLF    https://www.arrow.com/en/products/cr0402-jw-221glf/bourns                              Thick Film Resistors - SMD 220 OHM 5%                                                                                                                                                                        0.4mm    Bourns             CR0402-JW-221GLF         652-CR0402JW-221GLF  https://www.mouser.com/Search/Refine.aspx?Keyword=652-CR0402JW-221GLF                                                                                                       
1   FA-238_25.0000MB-C3      FA-238_25.0000MB-C3      FA238300000MBC0                Y3                                                                                                                                                                                    Crystals 25MHz 50ppm 18pF -20C +70C                                                                                                                                                                          FA-238 25.0000MB-C3 https://www.arrow.com/en/products/fa-23825.0000mb-c3/epson-electronics-america         Crystals 25MHz 50ppm 18pF -20C +70C                                                                                                                                                                          0.7mm    Epson Timing       FA-238 25.0000MB-C3      732-FA238-25B-C3     https://www.mouser.co.uk/ProductDetail/Epson-Timing/FA-238-25.0000MB-C3?qs=CANAagUtPAqYIDF5A41Crg%3D%3D                                                                     
1   G6CU-1114P-US-DC3        G6CU-1114P-US-DC3        G6CU1114PUSDC3                 K1                                                                                                                                                                                    Electromechanical Relay SPST-NO 10A 3VDC 45Ohm Through Hole - Bulk                                                                                                                                                                                                                                                      Electromechanical Relay SPST-NO 10A 3VDC 45Ohm Through Hole - Bulk                                                                                                                                           10mm     Omron Electronics  G6CU-1114P-US-DC3        653-G6CU-1114P-USDC3 https://www.mouser.co.uk/ProductDetail/Omron-Electronics/G6CU-1114P-US-DC3?qs=wkx8pu8tL7J61R5utGxXEw%3D%3D                                                                  
4   HDSM-283L                HDSM-283L                HDSM283L                       DS14, DS15, DS16, DS17                                                                                                                                                                LED Displays & Accessories Org 605nm 8.5mcd CC SD 7 Segment                                                                                                                                                                                                                                                             LED Displays & Accessories Org 605nm 8.5mcd CC SD 7 Segment                                                                                                                                                  3.15mm   Avago Technologies HDSM-283L                630-HDSM-283L        https://www.mouser.co.uk/ProductDetail/Broadcom-Avago/HDSM-283L?qs=NCV3C3qdz%2FC%2FCUC6%2FdWPrA%3D%3D                                                                       
1   HLK-PM03                 HLK-PM03                 HLKPM03                        PS1                                                                                                                                                                                   Power Module AC-DC Through Hole RoHS                                                                                                                                                                                                                                                                                    Power Module AC-DC Through Hole RoHS                                                                                                                                                                         15mm     Hi-Link            HLK-PM03
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

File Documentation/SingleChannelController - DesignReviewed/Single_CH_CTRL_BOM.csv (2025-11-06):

Part | Value | Device | Package | Description | ARROW_PART_NUMBER | ARROW_PRICE-STOCK | DESCRIPTION | HEIGHT | MANUFACTURER_NAME | MANUFACTURER_PART_NUMBER | MOUSER_PART_NUMBER | MOUSER_PRICE-STOCK | MOUSER_TESTING_PART_NUMBER | MOUSER_TESTING_PRICE-STOCK
C1 | 0.1uF | B32922X2104K000 | B32922X_(18_X_5) | EMI Suppression Capacitors, 0.1uF, 275Vrms AC, 5m(W) x 10.5m(H) x 18m(L) | B32922X2104K000 | https://www.arrow.com/en/products/b32922x2104k000/epcos-tdk?region=nac | EMI Suppression Capacitors, 0.1uF, 275Vrms AC, 5m(W) x 10.5m(H) x 18m(L) | 10.5mm | TDK | B32922X2104K000 | 871-B32922X2104K000 | https://www.mouser.co.uk/ProductDetail/EPCOS-TDK/B32922X2104K000?qs=TuK3vfAjtkWDVip5zaCELA%3D%3D
C2 | 220uF | 860010473011 | CAPPRD250W52D630H1250 | Wurth Elektronik 220uF 25 V dc Aluminium Electrolytic Capacitor, WCAP-ATG8 Series 2000h 6.3 (Dia.) x 11mm |  |  | Wurth Elektronik 220uF 25 V dc Aluminium Electrolytic Capacitor, WCAP-ATG8 Series 2000h 6.3 (Dia.) x 11mm | 12.5mm | Wurth Elektronik | 860010473011 | 710-860010473011 | https://www.mouser.co.uk/ProductDetail/Wurth-Elektronik/860010473011?qs=0KOYDY2FL2%252Bm07azjhm%2FHQ%3D%3D
C3 | 18pF | 04025U180FAT2A | CAPC1005X56N | AVX - 04025U180FAT2A - CAP, MLCC, C0G / NP0, 18PF, 50V, 0402 | 04025U180FAT2A | https://www.arrow.com/en/products/04025u180fat2a/avx | AVX - 04025U180FAT2A - CAP, MLCC, C0G / NP0, 18PF, 50V, 0402 | 0.56mm | AVX | 04025U180FAT2A | 581-04025U180FAT2A | https://www.mouser.co.uk/ProductDetail/AVX/04025U180FAT2A/?qs=lqAf%2FiVYw9iIZ7dTMzpUiQ%3D%3D
C4 | 18pF | 04025U180FAT2A | CAPC1005X56N | AVX - 04025U180FAT2A - CAP, MLCC, C0G / NP0, 18PF, 50V, 0402 | 04025U180FAT2A | https://www.arrow.com/en/products/04025u180fat2a/avx | AVX - 04025U180FAT2A - CAP, MLCC, C0G / NP0, 18PF, 50V, 0402 | 0.56mm | AVX | 04025U180FAT2A | 581-04025U180FAT2A | https://www.mouser.co.uk/ProductDetail/AVX/04025U180FAT2A/?qs=lqAf%2FiVYw9iIZ7dTMzpUiQ%3D%3D
C16 | 0.1uF | C0402C104K4RACTU | C0402 | SMD Comm X7R, Ceramic, 0.1 uF, 10%, 16 VDC, 40 VDC, 125C, -55C, X7R, SMD, MLCC, Temperature Stable, Class II, 10 % , 5 GOhms, 1.21 mg, 0402, 1mm, 0.5mm, 0.5mm, 0.3mm, 0.3mm, 10000, 78 Weeks, 80 | C0402C104K4RACTU | https://www.arrow.com/en/products/c0402c104k4ractu/kemet-corporation?region=nac | SMD Comm X7R, Ceramic, 0.1 uF, 10%, 16 VDC, 40 VDC, 125C, -55C, X7R, SMD, MLCC, Temperature Stable, Class II, 10 % , 5 GOhms, 1.21 mg, 0402, 1mm, 0.5mm, 0.5mm, 0.3mm, 0.3mm, 10000, 78 Weeks, 80 | 0.55mm | KEMET | C0402C104K4RACTU | 80-C0402C104K4R | https://www.mouser.co.uk/ProductDetail/KEMET/C0402C104K4RACTU?qs=DBJr%252BvBUjU54jK7d4uAeew%3D%3D
C17 | 0.1uF | C0402C104K4RACTU | C0402 | SMD Comm X7R, Ceramic, 0.1 uF, 10%, 16 VDC, 40 VDC, 125C, -55C, X7R, SMD, MLCC, Temperature Stable, Class II, 10 % , 5 GOhms, 1.21 mg, 0402, 1mm, 0.5mm, 0.5mm, 0.3mm, 0.3mm, 10000, 78 Weeks, 80 | C0402C104K4RACTU | https://www.arrow.com/en/products/c0402c104k4ractu/kemet-corporation?region=nac | SMD Comm X7R, Ceramic, 0.1 uF, 10%, 16 VDC, 40 VDC, 125C, -55C, X7R, SMD, MLCC, Temperature Stable, Class II, 10 % , 5 GOhms, 1.21 mg, 0402, 1mm, 0.5mm, 0.5mm, 0.3mm, 0.3mm, 10000, 78 Weeks, 80 | 0.55mm | KEMET | C0402C104K4RACTU | 80-C0402C104K4R | https://www.mouser.co.uk/ProductDetail/KEMET/C0402C104K4RACTU?qs=DBJr%252BvBUjU54jK7d4uAeew%3D%3D
C18 | 1000pF | C4520X7R3D102K130KA | C4520_COMMERCIAL | MULTILAYER CERAMIC CHIP CAPACITORS, 4520, Commercial grade, general (Up to 75V) | C4520X7R3D102K130KA | https://www.arrow.com/en/products/c4520x7r3d102k130ka/tdk | MULTILAYER CERAMIC CHIP CAPACITORS, 4520, Commercial grade, general (Up to 75V) | 1mm | TDK | C4520X7R3D102K130KA | 810-C4520X7R3D102K | https://www.mouser.co.uk/ProductDetail/TDK/C4520X7R3D102K130KA?qs=NRhsANhppD%2FmDDEB06mgKg%3D%3D
C19 | 22pF | CBR04C220J5GAC | CBR04C | CBR-SMD RF C0G, Ceramic, 22 pF, 5%, 50 VDC, 125 VDC, 125C, -55C, C0G, SMD, Fixed, RF, Ultra High Q, Low ESR, Class I, 0.12 % , 10 GOhms, 840, 1.4 mg, 0402, 1mm, 0.5mm, 0.5mm, 0.25mm, 10000, 78 Weeks, 120 | CBR04C220J5GAC | https://www.arrow.com/en/products/cbr04c220j5gac/kemet-corporation?region=nac | CBR-SMD RF C0G, Ceramic, 22 pF, 5%, 50 VDC, 125 VDC, 125C, -55C, C0G, SMD, Fixed, RF, Ultra High Q, Low ESR, Class I, 0.12 % , 10 GOhms, 840, 1.4 mg, 0402, 1mm, 0.5mm, 0.5mm, 0.25mm, 10000, 78 Weeks, 120 | mm | KEMET | CBR04C220J5GAC | 80-CBR04C220J5G | https://www.mouser.co.uk/ProductDetail/KEMET/CBR04C220J5GAC?qs=BjUX18ghZXi0endstTtQyQ%3D%3D
C20 | 22pF | CBR04C220J5GAC | CBR04C | CBR-SMD RF C0G, Ceramic, 22 pF, 5%, 50 VDC, 125 VDC, 125C, -55C, C0G, SMD, Fixed, RF, Ultra High Q, Low ESR, Class I, 0.12 % , 10 GOhms, 840, 1.4 mg, 0402, 1mm, 0.5mm, 0.5mm, 0.25mm, 10000, 78 Weeks, 120 | CBR04C220J5GAC | https://www.arrow.com/en/products/cbr04c220j5gac/kemet-corporation?region=nac | CBR-SMD RF C0G, Ceramic, 22 pF, 5%, 50 VDC, 125 VDC, 125C, -55C, C0G, SMD, Fixed, RF, Ultra High Q, Low ESR, Class I, 0.12 % , 10 GOhms, 840, 1.4 mg, 0402, 1mm, 0.5mm, 0.5mm, 0.25mm, 10000, 78 Weeks, 120 | mm | KEMET | CBR04C220J5GAC | 80-CBR04C220J5G | https://www.mouser.co.uk/ProductDetail/KEMET/CBR04C220J5GAC?qs=BjUX18ghZXi0endstTtQyQ%3D%3D
C28 | 0.1uF | C0805C104K5RAC7411 | CAPC2012X88N | Cap Ceramic 0.1uF 50V X7R 10% Pad SMD 0805 125C T/R | C0805C104K5RAC7411 | https://www.arrow.com/en/products/c0805c104k5rac7411/kemet-corporation | Cap Ceramic 0.1uF 50V X7R 10% Pad SMD 0805 125C T/R | 0.88mm | KEMET | C0805C104K5RAC7411 | 80-C0805C104K5RACLR | https://www.mouser.co.uk/ProductDetail/KEMET/C0805C104K5RAC7411?qs=jbRM9o5BbzPcVXF0wW9AYg%3D%3D
D1 | BAS16 | BAS16 | SOT95P240X110-3N | Small signal diode,BAS16 0.25A 85V Infineon BAS16, SMT Switching Diode, 85V 250mA, 4ns, 3-Pin SOT-23 |  |  | Small signal diode,BAS16 0.25A 85V Infineon BAS16, SMT Switching Diode, 85V 250mA, 4ns, 3-Pin SOT-23 | 1.1mm | Infineon | BAS16
DS14 | HDSM-283L | HDSM-283L | HDSM283L | LED Displays & Accessories Org 605nm 8.5mcd CC SD 7 Segment |  |  | LED Displays & Accessories Org 605nm 8.5mcd CC SD 7 Segment | 3.15mm | Avago Technologies | HDSM-283L | 630-HDSM-283L | https://www.mouser.co.uk/ProductDetail/Broadcom-Avago/HDSM-283L?qs=NCV3C3qdz%2FC%2FCUC6%2FdWPrA%3D%3D
DS15 | HDSM-283L | HDSM-283L | HDSM283L | LED Displays & Accessories Org 605nm 8.5mcd CC SD 7 Segment |  |  | LED Displays & Accessories Org 605nm 8.5mcd CC SD 7 Segment | 3.15mm | Avago Technologies | HDSM-283L | 630-HDSM-283L | https://www.mouser.co.uk/ProductDetail/Broadcom-Avago/HDSM-283L?qs=NCV3C3qdz%2FC%2FCUC6%2FdWPrA%3D%3D
DS16 | HDSM-283L | HDSM-283L | HDSM283L | LED Displays & Accessories Org 605nm 8.5mcd CC SD 7 Segment |  |  | LED Displays & Accessories Org 605nm 8.5mcd CC SD 7 Segment | 3.15mm | Avago Technologies | HDSM-283L | 630-HDSM-283L | https://www.mouser.co.uk/ProductDetail/Broadcom-Avago/HDSM-283L?qs=NCV3C3qdz%2FC%2FCUC6%2FdWPrA%3D%3D
DS17 | HDSM-283L | HDSM-283L | HDSM283L | LED Displays & Accessories Org 605nm 8.5mcd CC SD 7 Segment |  |  | LED Displays & Accessories Org 605nm 8.5mcd CC SD 7 Segment | 3.15mm | Avago Technologies | HDSM-283L | 630-HDSM-283L | https://www.mouser.co.uk/ProductDetail/Broadcom-Avago/HDSM-283L?qs=NCV3C3qdz%2FC%2FCUC6%2FdWPrA%3D%3D
F1 | 0.5A Slow Blow | RST_500_AMMO | RST500AMMO | Fuse Micro Slow Blow Acting 0.5A 250V Radial 8.35 X 4 X 8.2mm Ammo CCC/PSE/SEMKO/VDE/cULus | RST 500 AMMO | https://www.arrow.com/en/products/rst500-ammo/bel-group | Fuse Micro Slow Blow Acting 0.5A 250V Radial 8.35 X 4 X 8.2mm Ammo CCC/PSE/SEMKO/VDE/cULus | 7.9mm | Stewart Connector | RST 500 AMMO | 530-RST500AMMO | https://www.mouser.co.uk/ProductDetail/Bel-Fuse/RST-500-AMMO?qs=MvPYbBWWJyujgJzBtIxlxw%3D%3D
IC2 | 74HC14D | 74HC14D | SOIC127P600X175-14N | Inverter Schmitt Trigger 6-Element CMOS 14-Pin SOIC T/R | 74HC14D | https://www.arrow.com/en/products/74hc14d/toshiba?region=nac | Inverter Schmitt Trigger 6-Element CMOS 14-Pin SOIC T/R | 1.75mm | Toshiba | 74HC14D | 757-74HC14D | https://www.mouser.co.uk/ProductDetail/Toshiba/74HC14D?qs=y6ZabgHbY%252BwfUBrwO9UV%252Bg%3D%3D
IC6 | SN74AC11IPWREP | SN74AC11IPWREP | SOP65P640X120-14N | Enhanced Product Triple 3-Input Positive-And Gates | SN74AC11IPWREP | https://www.arrow.com/en/products/sn74ac11ipwrep/texas-instruments | Enhanced Product Triple 3-Input Positive-And Gates | 1.2mm | Texas Instruments | SN74AC11IPWREP | 595-SN74AC11IPWREP | https://www.mouser.co.uk/ProductDetail/Texas-Instruments/SN74AC11IPWREP?qs=fSCvMSq5ISVmV1J44UEGNg%3D%3D
IC7 | SN74HCS238QDRQ1 | SN74HCS238QDRQ1 | SOIC127P600X175-16N | Encoders, Decoders, Multiplexers & Demultiplexers Automotive 3-to-8 line decoder demultiplexer inverting and non-inverting 16-SOIC -40 to 125 |  |  | Encoders, Decoders, Multiplexers & Demultiplexers Automotive 3-to-8 line decoder demultiplexer inverting and non-inverting 16-SOIC -40 to 125 | 1.75mm | Texas Instruments | SN74HCS238QDRQ1 | 595-SN74HCS238QDRQ1 | https://www.mouser.co.uk/ProductDetail/Texas-Instruments/SN74HCS238QDRQ1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
IC9 | KSZ8851SNLI-TR | KSZ8851SNLI-TR | QFN50P500X500X100-33N | Microchip KSZ8851SNLI-TR, Ethernet Controller, 100Mbps MDI/MDIX, MII, SPI, 1.8 V, 2.5 V, 3.3 V, 32-Pin MLF | KSZ8851SNLI-TR | https://www.arrow.com/en/products/ksz8851snli-tr/microchip-technology | Microchip KSZ8851SNLI-TR, Ethernet Controller, 100Mbps MDI/MDIX, MII, SPI, 1.8 V, 2.5 V, 3.3 V, 32-Pin MLF | 1mm | Microchip | KSZ8851SNLI-TR | 998-KSZ8851SNLITR | https://www.mouser.co.uk/ProductDetail/Microchip-Technology-Atmel/KSZ8851SNLI-TR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
IC16 | ATSAM4S2AB-ANR | ATSAM4S2AB-ANR | QFP50P900X900X160-48N | ARM Microcontrollers - MCU 48LQFP,GREEN,EXT TEMP(105C),MRL B,128K FLASH,64K SRAM | ATSAM4S2AB-ANR | https://www.arrow.com/en/products/atsam4s2ab-anr/microchip-technology | ARM Microcontrollers - MCU 48LQFP,GREEN,EXT TEMP(105C),MRL B,128K FLASH,64K SRAM | 1.6mm | Microchip | ATSAM4S2AB-ANR | 556-ATSAM4S2AB-ANR | https://www.mouser.co.uk/ProductDetail/Microchip-Technology-Atmel/ATSAM4S2AB-ANR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
IC17 | MAX31855JASA+ | MAX31855JASA+ | SOIC127P600X175-8N | Sensor Interface Thermocouple To Digital Converter |  |  | Sensor Interface Thermocouple To Digital Converter | 1.75mm | Maxim Integrated | MAX31855JASA+ | 700-MAX31855JASA+ | https://www.mouser.co.uk/ProductDetail/Maxim-Integrated/MAX31855JASA%2b?qs=4Rc5iGDDRGgfomCSqMwnEw%3D%3D
IC18 | 74HC14D | 74HC14D | SOIC127P600X175-14N | Inverter Schmitt Trigger 6-Element CMOS 14-Pin SOIC T/R | 74HC14D | https://www.arrow.com/en/products/74hc14d/toshiba?region=nac | Inverter Schmitt Trigger 6-Element CMOS 14-Pin SOIC T/R | 1.75mm | Toshiba | 74HC14D | 757-74HC14D | https://www.mouser.co.uk/ProductDetail/Toshiba/74HC14D?qs=y6ZabgHbY%252BwfUBrwO9UV%252Bg%3D%3D
IC19 | SN74AC11IPWREP | SN74AC11IPWREP | SOP65P640X120-14N | Enhanced Product Triple 3-Input Positive-And Gates | SN74AC11IPWREP | https://www.arrow.com/en/products/sn74ac11ipwrep/texas-instruments | Enhanced Product Triple 3-Input Positive-And Gates | 1.2mm | Texas Instruments | SN74AC11IPWREP | 595-SN74AC11IPWREP | https://www.mouser.co.uk/ProductDetail/Texas-Instruments/SN74AC11IPWREP?qs=fSCvMSq5ISVmV1J44UEGNg%3D%3D
IC20 | SN74HCS238QDRQ1 | SN74HCS238QDRQ1 | SOIC127P600X175-16N | Encoders, Decoders, Multiplexers & Demultiplexers Automotive 3-to-8 line decoder demultiplexer inverting and non-inverting 16-SOIC -40 to 125 |  |  | Encoders, Decoders, Multiplexers & Demultiplexers Automotive 3-to-8 line decoder demultiplexer inverting and non-inverting 16-SOIC -40 to 125 | 1.75mm | Texas Instruments | SN74HCS238QDRQ1 | 595-SN74HCS238QDRQ1 | https://www.mouser.co.uk/ProductDetail/Texas-Instruments/SN74HCS238QDRQ1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
IC21 | SN74HCS238QDRQ1 | SN74HCS238QDRQ1 | SOIC127P600X175-16N | Encoders, Decoders, Multiplexers & Demultiplexers Automotive 3-to-8 line decoder demultiplexer inverting and non-inverting 16-SOIC -40 to 125 |  |  | Encoders, Decoders, Multiplexers & Demultiplexers Automotive 3-to-8 line decoder demultiplexer inverting and non-inverting 16-SOIC -40 to 125 | 1.75mm | Texas Instruments | SN74HCS238QDRQ1 | 595-SN74HCS238QDRQ1 | https://www.mouser.co.uk/ProductDetail/Texas-Instruments/SN74HCS238QDRQ1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
IC22 | SN74HCS238QDRQ1 | SN74HCS238QDRQ1 | SOIC127P600X175-16N | Encoders, Decoders, Multiplexers & Demultiplexers Automotive 3-to-8 line decoder demultiplexer inverting and non-inverting 16-SOIC -40 to 125 |  |  | Encoders, Decoders, Multiplexers & Demultiplexers Automotive 3-to-8 line decoder demultiplexer inverting and non-inverting 16-SOIC -40 to 125 | 1.75mm | Texas Instruments | SN74HCS238QDRQ1 | 595-SN74HCS238QDRQ1 | https://www.mouser.co.uk/ProductDetail/Texas-Instruments/SN74HCS238QDRQ1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
IC27 | 2SA1362-GR,LF | 2SA1362-GR,LF | 2SA1362GRLF | PNP Transistor, VCEO=-15V, IC=-0.8A, hFE=200 to 400 in SOT-346 (S-Mini) package |  |  | PNP Transistor, VCEO=-15V, IC=-0.8A, hFE=200 to 400 in SOT-346 (S-Mini) package | 1.4mm | Toshiba | 2SA1362-GR,LF | 757-2SA1362-GRLF | https://www.mouser.co.uk/ProductDetail/Toshiba/2SA1362-GRLF?qs=bZr6mbWTK5kLJ9eOLrMUZg%3D%3D
IC28 | 2SA1362-GR,LF | 2SA1362-GR,LF | 2SA1362GRLF | PNP Transistor, VCEO=-15V, IC=-0.8A, hFE=200 to 400 in SOT-346 (S-Mini) package |  |  | PNP Transistor, VCEO=-15V, IC=-0.8A, hFE=200 to 400 in SOT-346 (S-Mini) package | 1.4mm | Toshiba | 2SA1362-GR,LF | 757-2SA1362-GRLF | https://www.mouser.co.uk/ProductDetail/Toshiba/2SA1362-GRLF?qs=bZr6mbWTK5kLJ9eOLrMUZg%3D%3D
IC29 | 2SA1362-GR,LF | 2SA1362-GR,LF | 2SA1362GRLF | PNP Transistor, VCEO=-15V, IC=-0.8A, hFE=200 to 400 in SOT-346 (S-Mini) package |  |  | PNP Transistor, VCEO=-15V, IC=-0.8A, hFE=200 to 400 in SOT-346 (S-Mini) package | 1.4mm | Toshiba | 2SA1362-GR,LF | 757-2SA1362-GRLF | https://www.mouser.co.uk/ProductDetail/Toshiba/2SA1362-GRLF?qs=bZr6mbWTK5kLJ9eOLrMUZg%3D%3D
IC30 | 2SA1362-GR,LF | 2SA1362-GR,LF | 2SA1362GRLF | PNP Transistor, VCEO=-15V, IC=-0.8A, hFE=200 to 400 in SOT-346 (S-Mini) package |  |  | PNP Transistor, VCEO=-15V, IC=-0.8A, hFE=200 to 400 in SOT-346 (S-Mini) package | 1.4mm | Toshiba | 2SA1362-GR,LF | 757-2SA1362-GRLF | https://www.mouser.co.uk/ProductDetail/Toshiba/2SA1362-GRLF?qs=bZr6mbWTK5kLJ9eOLrMUZg%3D%3D
IC31 | 2SA1362-GR,LF | 2SA1362-GR,LF | 2SA1362GRLF | PNP Transistor, VCEO=-15V, IC=-0.8A, hFE=200 to 400 in SOT-346 (S-Mini) package |  |  | PNP Transistor, VCEO=-15V, IC=-0.8A, hFE=200 to 400 in SOT-346 (S-Mini) package | 1.4mm | Toshiba | 2SA1362-GR,LF | 757-2SA1362-GRLF | https://www.mouser.co.uk/ProductDetail/Toshiba/2SA1362-GRLF?qs=bZr6mbWTK5kLJ9eOLrMUZg%3D%3D
IC32 | 2SA1362-GR,LF | 2SA1362-GR,LF | 2SA1362GRLF | PNP Transistor, VCEO=-15V, IC=-0.8A, hFE=200 to 400 in SOT-346 (S-Mini) package |  |  | PNP Transistor, VCEO=-15V, IC=-0.8A, hFE=200 to 400 in SOT-346 (S-Mini) package | 1.4mm | Toshiba | 2SA1362-GR,LF | 757-2SA1362-GRLF | https://www.mouser.co.uk/ProductDetail/Toshiba/2SA1362-GRLF?qs=bZr6mbWTK5kLJ9eOLrMUZg%3D%3D
IC33 | 2SA1362-GR,LF | 2SA1362-GR,LF | 2SA1362GRLF | PNP Transistor, VCEO=-15V, IC=-0.8A, hFE=200 to 400 in SOT-346 (S-Mini) package |  |  | PNP Transistor, VCEO=-15V, IC=-0.8A, hFE=200 to 400 in SOT-346 (S-Mini) package | 1.4mm | Toshiba | 2SA1362-GR,LF | 757-2SA1362-GRLF | https://www.mouser.co.uk/ProductDetail/Toshiba/2SA1362-GRLF?qs=bZr6mbWTK5kLJ9eOLrMUZg%3D%3D
IC34 | 2SA1362-GR,LF | 2SA1362-GR,LF | 2SA1362GRLF | PNP Transistor, VCEO=-15V, IC=-0.8A, hFE=200 to 400 in SOT-346 (S-Mini) package |  |  | PNP Transistor, VCEO=-15V, IC=-0.8A, hFE=200 to 400 in SOT-346 (S-Mini) package | 1.4mm | Toshiba | 2SA1362-GR,LF | 757-2SA1362-GRLF | https://www.mouser.co.uk/ProductDetail/Toshiba/2SA1362-GRLF?qs=bZr6mbWTK5kLJ9eOLrMUZg%3D%3D
IC35 | 2SA1362-GR,LF | 2SA1362-GR,LF | 2SA1362GRLF | PNP Transistor, VCEO=-15V, IC=-0.8A, hFE=200 to 400 in SOT-346 (S-Mini) package |  |  | PNP Transistor, VCEO=-15V, IC=-0.8A, hFE=200 to 400 in SOT-346 (S-Mini) package | 1.4mm | Toshiba | 2SA1362-GR,LF | 757-2SA1362-GRLF | https://www.mouser.co.uk/ProductDetail/Toshiba/2SA1362-GRLF?qs=bZr6mbWTK5kLJ9eOLrMUZg%3D%3D
IC36 | 2SA1362-GR,LF | 2SA1362-GR,LF | 2SA1362GRLF | PNP Transistor, VCEO=-15V, IC=-0.8A, hFE=200 to 400 in SOT-346 (S-Mini) package |  |  | PNP Transistor, VCEO=-15V, IC=-0.8A, hFE=200 to 400 in SOT-346 (S-Mini) package | 1.4mm | Toshiba | 2SA1362-GR,LF | 757-2SA1362-GRLF | https://www.mouser.co.uk/ProductDetail/Toshiba/2SA1362-GRLF?qs=bZr6mbWTK5kLJ9eOLrMUZg%3D%3D
IC37 | 2SA1362-GR,LF | 2SA1362-GR,LF | 2SA1362GRLF | PNP Transistor, VCEO=-15V, IC=-0.8A, hFE=200 to 400 in SOT-346 (S-Mini) package |  |  | PNP Transistor, VCEO=-15V, IC=-0.8A, hFE=200 to 400 in SOT-346 (S-Mini) package | 1.4mm | Toshiba | 2SA1362-GR,LF | 757-2SA1362-GRLF | https://www.mouser.co.uk/ProductDetail/Toshiba/2SA1362-GRLF?qs=bZr6mbWTK5kLJ9eOLrMUZg%3D%3D
IC38 | 2SA1362-GR,LF | 2SA1362-GR,LF | 2SA1362GRLF | PNP Transistor, VCEO=-15V, IC=-0.8A, hFE=200 to 400 in SOT-346 (S-Mini) package |  |  | PNP Transistor, VCEO=-15V, IC=-0.8A, hFE=200 to 400 in SOT-346 (S-Mini) package | 1.4mm | Toshiba | 2SA1362-GR,LF | 757-2SA1362-GRLF | https://www.mouser.co.uk/ProductDetail/Toshiba/2SA1362-GRLF?qs=bZr6mbWTK5kLJ9eOLrMUZg%3D%3D
IC39 | 2SA1362-GR,LF | 2SA1362-GR,LF | 2SA1362GRLF | PNP Transistor, VCEO=-15V, IC=-0.8A, hFE=200 to 400 in SOT-346 (S-Mini) package |  |  | PNP Transistor, VCEO=-15V, IC=-0.8A, hFE=200 to 400 in SOT-346 (S-Mini) package | 1.4mm | Toshiba | 2SA1362-GR,LF | 757-2SA1362-GRLF | https://www.mouser.co.uk/ProductDetail/Toshiba/2SA1362-GRLF?qs=bZr6mbWTK5kLJ9eOLrMUZg%3D%3D
IC40 | 2SA1362-GR,LF | 2SA1362-GR,LF | 2SA1362GRLF | PNP Transistor, VCEO=-15V, IC=-0.8A, hFE=200 to 400 in SOT-346 (S-Mini) package |  |  | PNP Transistor, VCEO=-15V, IC=-0.8A, hFE=200 to 400 in SOT-346 (S-Mini) package | 1.4mm | Toshiba | 2SA1362-GR,LF | 757-2SA1362-GRLF | https://www.mouser.co.uk/ProductDetail/Toshiba/2SA1362-GRLF?qs=bZr6mbWTK5kLJ9eOLrMUZg%3D%3D
IC41 | 2SA1362-GR,LF | 2SA1362-GR,LF | 2SA1362GRLF | PNP Transistor, VCEO=-15V, IC=-0.8A, hFE=200 to 400 in SOT-346 (S-Mini) package |  |  | PNP Transistor, VCEO=-15V, IC=-0.8A, hFE=200 to 400 in SOT-346 (S-Mini) package | 1.4mm | Toshiba | 2SA1362-GR,LF | 757-2SA1362-GRLF | https://www.mouser.co.uk/ProductDetail/Toshiba/2SA1362-GRLF?qs=bZr6mbWTK5kLJ9eOLrMUZg%3D%3D
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

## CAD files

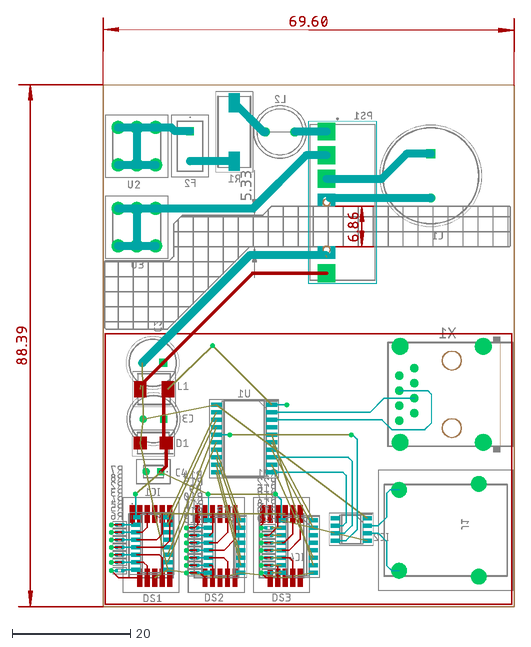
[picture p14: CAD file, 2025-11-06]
Documentation/SingleChannelController - DesignReviewed/Single_CH_CTRL.dxf
84.4 x 100.1

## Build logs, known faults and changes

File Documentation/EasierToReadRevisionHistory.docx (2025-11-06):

Following is the full list of revisions. Every revision was made by Giselle D. Oldest revisions are at the bottom.

Changed frontend pathing to be relative.

Made changes to make the project build. Unfortunately, there was a file missing that was never committed. That one is the libarm_cortexM4l_math.a. The project will not build without this. Also, the code for the nandflash was removed. If we ever need a nandflash, then we can recover the files from SVN. Additionally, a bug was fixed for a temp conversion function where the semaphore was released too early and wasn't actually providing protection.

Comment adding clarification.

This commit is just adding a comment to http server

Critical bug was fixed. The IP address would not update correctly on the web server and would cause permanent fault of the system. This was caused by the max size of a network mtu being too small. It was set to 700. Apparently the http server expects a POST to come in one packet so if the POST is too big then it causes bad behavior. It was changed to 1000 and the other changes increasing the TCP window and buffer sizes were set back to all 4s since the update done in the last rev didn't really improve performance significantly and there were issues with too much RAM consumption.

Modbus task updated to allow the client to write to the setpoint register and the temp system register and actually have it update the system. This version of the code was tested overnight and appears to be stable.

The modbus task was refactored significantly to improve safety. The network settings in FreeRTOSIPConfig.h were modified to optimize socket send and receive. A preliminary test showed greater reliability with the modbus task, and the FTP server is able to receive files with less errors. The display driver and setpoint handler were modified moderately, mostly comment updates, white space changes, and minor organizational changes. Once small change was made to index.html, the heading on the home page was altered to be more relevant.

I decided to overhaul the display driver since it was getting unwieldy and I feared it would be difficult to maintain in the future. Previously, the display driver managed the temperature system, and the other modules did not have knowledge of what temperature system was being used. I decided to give this responsibility to the temperature reading processor since it seems like a more natural role. In the previous commit, the display driver was also managing two modbus holding registers, that task was given to the setpoint handler since that was also the natural place for that to be. The display handler is now smaller and more focused. The temp reading processor is handling more stuff. Also, in the previous commit, a merge conflict had broken modbus. This commit fixes it. Another thing is that the hard fault handler has been improved to allow easier debugging of hard faults. A minor change was made to the displayHandler in the website front end to allow compatibility with the new firmware.

Update to fix modbus packet drop issue. The temperature is no longer an input register, it is now a holding register. Also the setpoint and temp system were added as holding registers.

Some adjustments made to improve the http server and ftp upload. Modbus task priority was updated.

Server was updated to use fetch api to get the current temperature from SAM. The backend was updated to support a get request and return the temperature. Temp reading main was editted to stay alive along with the server so that it can provide temp readings. The heap size variable was pushed to its maximum.

IPV6 UI has been removed from the website since it wont be supported in the initial release. Some changes were made to the ftp and http server send functions. I made it so that if freertos_send doesn't send all the data its told to, then it will keep trying until it succeeds. I also increased the tcp windows for both servers to help improve performance.

This branch includes a start for making SAM ipv6 compatible. It currently is not fully functional. I believe fundamental changes to the underlying networkinterface driver are needed to achieve this milestone

Change was made that appears to fix the problem seen previously where outward network traffic would fail. Before I had fixed this by modifying an operating system file. This was only a bandaid though. The fix here appears to have fixed the problem entirely by addressing the cause and has even boosted the speed of the network. It may not be the last update though if any problems are later discovered.

Critical update was made to HexModule.c and the setpoint handler. There was an issue with the applications use of globals and a shared temperature conversion function. A thread collision issue was causing the application to crash due to stack corruption. This has probably been an issue for awhile and simply wasn't noticed until now. The globals in hex module have been removed and semaphore protection has been added to the toFahrenheit function since it is shared between modules.

Huge website update! UI has been changed to be more snazzy, the reboot feature was edited a bit, a setpoint handler was added, also the mac address wasn't being loaded at initialization and that has been addressed.

Refactored the display driver to clean up some clumsiness. Added new comments to both the display driver and the setpoint handler.

Main accomplishments today were getting the reboot feature completely working and getting most the work done for updating the setpoint with the web server. Some changes were made to the server code, mostly just small improvements. For example, the way the setpoint was being saved wasn't optimal, and boundary checking wasn't very safe for the display hander. I made it so that no matter what temperature system is used, the display will never overflow or try to publish a setpoint that is out of bounds.

Another update, lots of the backend capability of the server has been added. IP address and other network settings are set at initialization. The http post command is in the process of being made more generic. The goal is to have POST work for a reboot command and possibly for a setpoint update command. Some changes were made to slow down the network loading speed a little bit to improve reliability. Also, lots of unnecessary project files were removed.

The main update here is to the front end portion of the web server. The network settings page has been changed substantially to better suit the application and to apply proper error checking. A small update was made to the backend to change the behavior of how the settings.json file is edited. Before, it was appended to. Now it is recreated whenever the network settings form is posted.

Fixed a bug that was mysterious for awhile. The network interface would occasionally crash on a config assert. I found out that the problem was that occasionally the network would fail to get a buffer because the semaphore wasn't available within the given timeout. I added a while loop to force the network driver to block until it gets a buffer instead of just killing the whole program. I also optimized the speed of network transmission, so now operations like loading the webpage happen about 5 times faster. I also changed the RAM back to a level suitable for a 160kB ram size instead of the 128kB. The device runs much more reliably with this amount of ram.

Multifile update to improve safety concerning the deleteNonWebTasks function. I was concerned that the interprocess communication could rarely cause an unrecoverable exception because of the way the threads were shut down. I guarded queuereceive and queuesend calls with null checks and I moved around the ownership of many of the queues. I changed it so that a task owns a queue if it is the one who sends data on the queue. That way when the task is shutdown, its only shutting down queues that it sends data on. I also made the shutdown functions owned by the tasks themselves and I made them blocking so that only one shutdown can occur at a time, that way I can choose the order that they are shutdown in. I noticed this caused a huge probelm with the web and ftp server because of the amount of time it would take to shutdown all tasks, so I created a special thread whose only purpose it to kill other tasks, after which it kills itself. This fixed the performance issue.

The main update here is the web interface. More error validation was added to prevent a gateway address and ip address from being on a different subnet. The application code was also updated to close the setpoint monitor, the btn driver and the other close functions were updated to free memory their respective tasks were using. The display driver was updated as well. The organization of certain elements were changed. An alarming bug was discovered that doesn't appear to be related to software. A seg module was saving its gpio incorrectly and this was causing a system crash. Its really bad because it appears to be a damaged memory cell, not something amendable in software. I just changed how it was saved and then it would read accurately again, assuming because it was using a different memory cell.

Added the ability to display the current temperature and setpoint in either celsius or fahrenheit. Toggling the UP button will switch between these.

Updated setpoint handler to fix bugs and be more responsive.

Optimized memory and cleaned up unused headers.

Basic setpoint handling has been added! There are more features to add with that but the basics appear to be working. Some refactoring was done as well.

Display handling has been added. Button handling added as well with software debouncing. The setpoint handler is started as well. Currently it only loads the current setpoint and saves it when there's a new one. Big change was made with the flash.ld file. RAM was optimized significantly, giving the application an additional 12 thousand bytes to works with! The change in init.c may not be necessary but it was added to prevent PA9 from being initialized twice.

Added a fix for data streaming from the http and ftp servers. The network interface has a limit to the number of bytes it can process and how quickly it can process. I modified a the tcp send and a function that returns buffer space available for transmit. I put a limit on the amount of bytes that can be streamed (no more than 1024) and I added a delay to tcp send so that any module that tries to stream will do so successfully, given the constraints with the network driver.

These files were removed from their directory and moved elsewhere. Forgot to include this in previous commit.

TCP directories were organized in a more logical way, a preliminary nand flash driver is included. It is not validated but could work someday if necessary. Support for an SD card was added. FTP and web server is running but can only handle small files. Some bug is present that prevents transmission of large packets. Probably an issue with NetworkInterface since it was never tested with large data streams.

Added base for display driver. It currently only supports 1 seg module and it counts from 0 to 9 on that module.

Updated the temperature monitor to use only 1 register instead of 4. It's not fully validated since the appropriate hardware is not available, but it's probably good. I also did a major cleanup on the project, organizing things. I removed the UDP logging task files since the task requires too much RAM to run. I made a small change to the network interface to prevent it from rebooting the chip before its had a chance to try connecting. The modbus task was updated to handle a single register write instead of 4, so it is simpler now.

Updated TempReadingMain.c to only show the whole number value of the temperature. Negative numbers are already in 2s complement so the only logic needed was grabbing the bits and extending the sign bit. Positive numbers only need to be grabbed since there is no sign bit.

Added temperature reading code. It's not fully validated but it appears to be reading temperatures. Changes to the network interface were made to improve network connection and semaphore protect the SPI master.

Fixed issues with network interface. Appears to work flawlessly now!

Made some changes to network interface to increase the reliability of the connection.

Forgot to add a couple files. This should be it for the addition of modbus to the project.

More deleted files...

These files need to be deleted.

Added support for modbus application protocol. A simulated temperature reading is available for reading. The network interface was improved slightly.

First commit! FreeRTOS is installed and the TCP IP stack is fully connected to the ksz8851snl chip through a fully ported NetworkInterface. An echo server is running to verify functionality. ICMP ping replies are working. Gratuitous ARP appears to work as well. UDP functionality has not been fully tested. Enabling the UDP printf task causes the device to run out of RAM so it cannot be used.

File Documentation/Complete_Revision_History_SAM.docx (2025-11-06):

Revision: 44

Author: gisel

Date: Thursday, October 2, 2025 4:48:13 PM

Message:

Changed frontend pathing to be relative.

Modified : /branches/Multi_Interface_SAM/websrc/help/cwm_config_help.htm

Modified : /branches/Multi_Interface_SAM/websrc/html/network_config.htm

Modified : /branches/Multi_Interface_SAM/websrc/html/reboot.htm

Modified : /branches/Multi_Interface_SAM/websrc/html/reboot_status.htm

Modified : /branches/Multi_Interface_SAM/websrc/html/setpoint_config.htm

Modified : /branches/Multi_Interface_SAM/websrc/index.html

Modified : /branches/Multi_Interface_SAM/websrc/scripts/utils.js

Modified : /websrc/help/cwm_config_help.htm

Modified : /websrc/html/network_config.htm

Modified : /websrc/html/reboot.htm

Modified : /websrc/html/reboot_status.htm

Modified : /websrc/html/setpoint_config.htm

Modified : /websrc/index.html

Revision: 43

Author: GiselleD

Date: Tuesday, May 9, 2023 6:15:23 PM

Message:

Made changes to make the project build. Unfortunately, there was a file missing that was never committed. That one is the libarm_cortexM4l_math.a. The project will not build without this. Also, the code for the nandflash was removed. If we ever need a nandflash, then we can recover the files from SVN. Additionally, a bug was fixed for a temp conversion function where the semaphore was released too early and wasn't actually providing protection.

Modified : /SingleChannelMonitorBox/Debug/Makefile

Modified : /SingleChannelMonitorBox/Debug/makedep.mk

Modified : /SingleChannelMonitorBox/SingleChannelMonitorBox.cproj

Deleted : /SingleChannelMonitorBox/src/ASF/common/components/memory/nand_flash

Deleted : /SingleChannelMonitorBox/src/ASF/common/services/storage/ecc_hamming

Deleted : /SingleChannelMonitorBox/src/ASF/sam/drivers/ebi

Deleted : /SingleChannelMonitorBox/src/ASF/sam/drivers/matrix

Added : /SingleChannelMonitorBox/src/ASF/thirdparty/CMSIS/Lib/GCC/libarm_cortexM4l_math.a

Deleted : /SingleChannelMonitorBox/src/ASF/thirdparty/freertos/freertos-7.3.0/source/FF_Source/FF_Portable/ff_nanddisk.c

Deleted : /SingleChannelMonitorBox/src/ASF/thirdparty/freertos/freertos-7.3.0/source/FF_Source/FF_Portable/ff_nanddisk.h

Modified : /SingleChannelMonitorBox/src/TC_Reader/TempReadingMain.c

Modified : /SingleChannelMonitorBox/src/asf.h

Deleted : /SingleChannelMonitorBox/src/config/conf_nf.h

Revision: 42

Author: GiselleD

Date: Sunday, March 5, 2023 10:43:34 PM

Message:

Comment adding clarification.

Modified : /SingleChannelMonitorBox/src/DisplayDriver/HexModule.c

Revision: 41

Author: GiselleD

Date: Monday, January 9, 2023 5:55:09 PM

Message:

This commit is just adding a comment to http server

Modified : /SingleChannelMonitorBox/src/ASF/thirdparty/freertos/freertos-7.3.0/source/FreeRTOS-Plus-TCP/protocols/HTTP/FreeRTOS_HTTP_server.c

Revision: 40

Author: GiselleD

Date: Friday, January 6, 2023 4:55:54 PM

Message:

Critical bug was fixed. The IP address would not update correctly on the web server and would cause permanent fault of the system. This was caused by the max size of a network mtu being too small. It was set to 700. Apparently the http server expects a POST to come in one packet so if the POST is too big then it causes bad behavior. It was changed to 1000 and the other changes increasing the TCP window and buffer sizes were set back to all 4s since the update done in the last rev didn't really improve performance significantly and there were issues with too much RAM consumption.

Modified : /SingleChannelMonitorBox/src/ASF/sam/utils/linker_scripts/sam4s/sam4sd32/gcc/flash.ld

Modified : /SingleChannelMonitorBox/src/DisplayDriver/HexModule.h

Modified : /SingleChannelMonitorBox/src/config/FreeRTOSConfig.h

Modified : /SingleChannelMonitorBox/src/config/FreeRTOSIPConfig.h

Revision: 39

Author: GiselleD

Date: Friday, January 6, 2023 12:45:07 PM

Message:

Modbus task updated to allow the client to write to the setpoint register and the temp system register and actually have it update the system. This version of the code was tested overnight and appears to be stable.

Modified : /SingleChannelMonitorBox/src/DisplayDriver/HexModule.c

Modified : /SingleChannelMonitorBox/src/DisplayDriver/HexModule.h

Modified : /SingleChannelMonitorBox/src/ModbusServerTCP/TCP/mbport.c

Modified : /SingleChannelMonitorBox/src/Setpoint_Handler/Setpoint_Handler.c

Modified : /SingleChannelMonitorBox/src/Setpoint_Handler/Setpoint_Handler.h

Modified : /SingleChannelMonitorBox/src/TC_Reader/TempReadingMain.c

Modified : /SingleChannelMonitorBox/src/TC_Reader/TempReadingMain.h

Modified : /SingleChannelMonitorBox/src/apptasks.c

Revision: 38

Author: GiselleD

Date: Wednesday, January 4, 2023 7:51:02 PM

Message:

The modbus task was refactored significantly to improve safety. The network settings in FreeRTOSIPConfig.h were modified to optimize socket send and receive. A preliminary test showed greater reliability with the modbus task, and the FTP server is able to receive files with less errors. The display driver and setpoint handler were modified moderately, mostly comment updates, white space changes, and minor organizational changes. Once small change was made to index.html, the heading on the home page was altered to be more relevant.

Modified : /SingleChannelMonitorBox/src/DisplayDriver/HexModule.c

Modified : /SingleChannelMonitorBox/src/DisplayDriver/HexModule.h

Modified : /SingleChannelMonitorBox/src/ModbusServerTCP/Include/mbport.h

Modified : /SingleChannelMonitorBox/src/ModbusServerTCP/TCP/mbport.c

Modified : /SingleChannelMonitorBox/src/Setpoint_Handler/Setpoint_Handler.c

Modified : /SingleChannelMonitorBox/src/Setpoint_Handler/Setpoint_Handler.h

Modified : /SingleChannelMonitorBox/src/TC_Reader/TempReadingMain.h

Modified : /SingleChannelMonitorBox/src/config/FreeRTOSIPConfig.h

Modified : /websrc/index.html

Revision: 37

Author: GiselleD

Date: Tuesday, January 3, 2023 8:29:11 PM

Message:

I decided to overhaul the display driver since it was getting unwieldy and I feared it would be difficult to maintain in the future. Previously, the display driver managed the temperature system, and the other modules did not have knowledge of what temperature system was being used. I decided to give this responsibility to the temperature reading processor since it seems like a more natural role. In the previous commit, the display driver was also managing two modbus holding registers, that task was given to the setpoint handler since that was also the natural place for that to be. The display handler is now smaller and more focused. The temp reading processor is handling more stuff. Also, in the previous commit, a merge conflict had broken modbus. This commit fixes it. Another thing is that the hard fault handler has been improved to allow easier debugging of hard faults. A minor change was made to the displayHandler in the website front end to allow compatibility with the new firmware.

Modified : /SingleChannelMonitorBox/src/ASF/thirdparty/freertos/freertos-7.3.0/source/FreeRTOS-Plus-TCP/protocols/HTTP/FreeRTOS_HTTP_server.c

Modified : /SingleChannelMonitorBox/src/DisplayDriver/HexModule.c

Modified : /SingleChannelMonitorBox/src/DisplayDriver/HexModule.h

Modified : /SingleChannelMonitorBox/src/ModbusServerTCP/TCP/mbport.c

Modified : /SingleChannelMonitorBox/src/Setpoint_Handler/Setpoint_Handler.c

Modified : /SingleChannelMonitorBox/src/Setpoint_Handler/Setpoint_Handler.h

Modified : /SingleChannelMonitorBox/src/TC_Reader/TempReadingMain.c

Modified : /SingleChannelMonitorBox/src/TC_Reader/TempReadingMain.h

Modified : /SingleChannelMonitorBox/src/apptasks.c

Modified : /SingleChannelMonitorBox/src/main.c

Modified : /websrc/scripts/displayhandler.js

Revision: 36

Author: GiselleD

Date: Tuesday, January 3, 2023 4:24:40 PM

Message:

Update to fix modbus packet drop issue. The temperature is no longer an input register, it is now a holding register. Also the setpoint and temp system were added as holding registers.

Modified : /SingleChannelMonitorBox/src/DisplayDriver/HexModule.c

Modified : /SingleChannelMonitorBox/src/DisplayDriver/HexModule.h

Modified : /SingleChannelMonitorBox/src/ModbusServerTCP/Include/mbport.h

Modified : /SingleChannelMonitorBox/src/Setpoint_Handler/Setpoint_Handler.c

Modified : /SingleChannelMonitorBox/src/TC_Reader/TempReadingMain.c

Modified : /SingleChannelMonitorBox/src/TC_Reader/TempReadingMain.h

Revision: 35

Author: GiselleD

Date: Sunday, January 1, 2023 1:39:15 PM

Message:

Some adjustments made to improve the http server and ftp upload. Modbus task priority was updated.

Modified : /SingleChannelMonitorBox/src/ASF/thirdparty/freertos/freertos-7.3.0/source/FreeRTOS-Plus-TCP/protocols/HTTP/FreeRTOS_HTTP_server.c

Modified : /SingleChannelMonitorBox/src/ModbusServerTCP/TCP/mbport.c

Modified : /SingleChannelMonitorBox/src/config/FreeRTOSIPConfig.h

Revision: 34

Author: GiselleD

Date: Friday, December 23, 2022 5:38:58 PM

Message:

Server was updated to use fetch api to get the current temperature from SAM. The backend was updated to support a get request and return the temperature. Temp reading main was editted to stay alive along with the server so that it can provide temp readings. The heap size variable was pushed to its maximum.

Modified : /SingleChannelMonitorBox/src/ASF/sam/utils/linker_scripts/sam4s/sam4sd32/gcc/flash.ld

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

Modified : /SingleChannelMonitorBox/src/TC_Reader/TempReadingMain.c

Modified : /SingleChannelMonitorBox/src/config/FreeRTOSConfig.h

Modified : /SingleChannelMonitorBox/src/config/FreeRTOSIPConfig.h

Modified : /websrc/html/setpoint_config.htm

Modified : /websrc/index.html

Modified : /websrc/scripts/displayhandler.js

Revision: 33

Author: GiselleD

Date: Friday, December 23, 2022 12:50:12 PM

Message:

IPV6 UI has been removed from the website since it wont be supported in the initial release. Some changes were made to the ftp and http server send functions. I made it so that if freertos_send doesn't send all the data its told to, then it will keep trying until it succeeds. I also increased the tcp windows for both servers to help improve performance.

Modified : /SingleChannelMonitorBox/src/ASF/thirdparty/freertos/freertos-7.3.0/source/FreeRTOS-Plus-TCP/protocols/FTP/FreeRTOS_FTP_server.c

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

Modified : /SingleChannelMonitorBox/src/config/FreeRTOSIPConfig.h

Modified : /websrc/html/network_config.htm

Modified : /websrc/index.html

Modified : /websrc/scripts/displayhandler.js

Modified : /websrc/settings.json

Revision: 32

Author: GiselleD

Date: Thursday, December 22, 2022 6:38:01 PM

Message:

This branch includes a start for making SAM ipv6 compatible. It currently is not fully functional. I believe fundamental changes to the underlying networkinterface driver are needed to achieve this milestone

Added : /branches/Multi_Interface_SAM (Copy from path: /, Revision, 29)

Modified : /branches/Multi_Interface_SAM/SingleChannelMonitorBox/Debug/Makefile

Modified : /branches/Multi_Interface_SAM/SingleChannelMonitorBox/Debug/makedep.mk

Modified : /branches/Multi_Interface_SAM/SingleChannelMonitorBox/SingleChannelMonitorBox.cproj

Modified : /branches/Multi_Interface_SAM/SingleChannelMonitorBox/src/ASF/sam/utils/linker_scripts/sam4s/sam4sd32/gcc/flash.ld

Modified : /branches/Multi_Interface_SAM/SingleChannelMonitorBox/src/ASF/thirdparty/freertos/freertos-7.3.0/source/FreeRTOS-Plus-TCP/FreeRTOS_ARP.c

Modified : /branches/Multi_Interface_SAM/SingleChannelMonitorBox/src/ASF/thirdparty/freertos/freertos-7.3.0/source/FreeRTOS-Plus-TCP/FreeRTOS_DHCP.c

Modified : /branches/Multi_Interface_SAM/SingleChannelMonitorBox/src/ASF/thirdparty/freertos/freertos-7.3.0/source/FreeRTOS-Plus-TCP/FreeRTOS_DNS.c

Modified : /branches/Multi_Interface_SAM/SingleChannelMonitorBox/src/ASF/thirdparty/freertos/freertos-7.3.0/source/FreeRTOS-Plus-TCP/FreeRTOS_IP.c

Replacing : /branches/Multi_Interface_SAM/SingleChannelMonitorBox/src/ASF/thirdparty/freertos/freertos-7.3.0/source/FreeRTOS-Plus-TCP/FreeRTOS_Sockets.c (Copy from path: /SingleChannelMonitorBox/src/ASF/thirdparty/freertos/freertos-7.3.0/source/FreeRTOS-Plus-TCP/FreeRTOS_Sockets.c, Revision, 30)

Modified : /branches/Multi_Interface_SAM/SingleChannelMonitorBox/src/ASF/thirdparty/freertos/freertos-7.3.0/source/FreeRTOS-Plus-TCP/FreeRTOS_Stream_Buffer.c

Modified : /branches/Multi_Interface_SAM/SingleChannelMonitorBox/src/ASF/thirdparty/freertos/freertos-7.3.0/source/FreeRTOS-Plus-TCP/FreeRTOS_TCP_IP.c

Modified : /branches/Multi_Interface_SAM/SingleChannelMonitorBox/src/ASF/thirdparty/freertos/freertos-7.3.0/source/FreeRTOS-Plus-TCP/FreeRTOS_TCP_WIN.c

Modified : /branches/Multi_Interface_SAM/SingleChannelMonitorBox/src/ASF/thirdparty/freertos/freertos-7.3.0/source/FreeRTOS-Plus-TCP/FreeRTOS_UDP_IP.c

Modified : /branches/Multi_Interface_SAM/SingleChannelMonitorBox/src/ASF/thirdparty/freertos/freertos-7.3.0/source/FreeRTOS-Plus-TCP/Include/FreeRTOSIPConfigDefaults.h

Modified : /branches/Multi_Interface_SAM/SingleChannelMonitorBox/src/ASF/thirdparty/freertos/freertos-7.3.0/source/FreeRTOS-Plus-TCP/Include/FreeRTOS_ARP.h

Modified : /branches/Multi_Interface_SAM/SingleChannelMonitorBox/src/ASF/thirdparty/freertos/freertos-7.3.0/source/FreeRTOS-Plus-TCP/Include/FreeRTOS_DHCP.h

Modified : /branches/Multi_Interface_SAM/SingleChannelMonitorBox/src/ASF/thirdparty/freertos/freertos-7.3.0/source/FreeRTOS-Plus-TCP/Include/FreeRTOS_DNS.h

Modified : /branches/Multi_Interface_SAM/SingleChannelMonitorBox/src/ASF/thirdparty/freertos/freertos-7.3.0/source/FreeRTOS-Plus-TCP/Include/FreeRTOS_IP.h

Modified : /branches/Multi_Interface_SAM/SingleChannelMonitorBox/src/ASF/thirdparty/freertos/freertos-7.3.0/source/FreeRTOS-Plus-TCP/Include/FreeRTOS_IP_Private.h

Modified : /branches/Multi_Interface_SAM/SingleChannelMonitorBox/src/ASF/thirdparty/freertos/freertos-7.3.0/source/FreeRTOS-Plus-TCP/Include/FreeRTOS_Sockets.h

Modified : /branches/Multi_Interface_SAM/SingleChannelMonitorBox/src/ASF/thirdparty/freertos/freertos-7.3.0/source/FreeRTOS-Plus-TCP/Include/FreeRTOS_Stream_Buffer.h

Modified : /branches/Multi_Interface_SAM/SingleChannelMonitorBox/src/ASF/thirdparty/freertos/freertos-7.3.0/source/FreeRTOS-Plus-TCP/Include/FreeRTOS_TCP_IP.h

Modified : /branches/Multi_Interface_SAM/SingleChannelMonitorBox/src/ASF/thirdparty/freertos/freertos-7.3.0/source/FreeRTOS-Plus-TCP/Include/FreeRTOS_TCP_WIN.h

Modified : /branches/Multi_Interface_SAM/SingleChannelMonitorBox/src/ASF/thirdparty/freertos/freertos-7.3.0/source/FreeRTOS-Plus-TCP/Include/FreeRTOS_UDP_IP.h

Modified : /branches/Multi_Interface_SAM/SingleChannelMonitorBox/src/ASF/thirdparty/freertos/freertos-7.3.0/source/FreeRTOS-Plus-TCP/Include/FreeRTOS_errno_TCP.h

Modified : /branches/Multi_Interface_SAM/SingleChannelMonitorBox/src/ASF/thirdparty/freertos/freertos-7.3.0/source/FreeRTOS-Plus-TCP/Include/IPTraceMacroDefaults.h

Modified : /branches/Multi_Interface_SAM/SingleChannelMonitorBox/src/ASF/thirdparty/freertos/freertos-7.3.0/source/FreeRTOS-Plus-TCP/Include/NetworkBufferManagement.h

Modified : /branches/Multi_Interface_SAM/SingleChannelMonitorBox/src/ASF/thirdparty/freertos/freertos-7.3.0/source/FreeRTOS-Plus-TCP/Portable/BufferManagement/BufferAllocation_2.c

Modified : /branches/Multi_Interface_SAM/SingleChannelMonitorBox/src/ASF/thirdparty/freertos/freertos-7.3.0/source/FreeRTOS-Plus-TCP/Portable/NetworkInterface/NetworkInterface.c

Modified : /branches/Multi_Interface_SAM/SingleChannelMonitorBox/src/ASF/thirdparty/freertos/freertos-7.3.0/source/FreeRTOS-Plus-TCP/Portable/NetworkInterface/NetworkInterface.h

Modified : /branches/Multi_Interface_SAM/SingleChannelMonitorBox/src/apptasks.c

Replacing : /branches/Multi_Interface_SAM/SingleChannelMonitorBox/src/config/FreeRTOSConfig.h (Copy from path: /SingleChannelMonitorBox/src/config/FreeRTOSConfig.h, Revision, 30)

Replacing : /branches/Multi_Interface_SAM/SingleChannelMonitorBox/src/config/FreeRTOSIPConfig.h (Copy from path: /SingleChannelMonitorBox/src/config/FreeRTOSIPConfig.h, Revision, 30)

Modified : /branches/Multi_Interface_SAM/SingleChannelMonitorBox/src/main.c

Revision: 31

Author: GiselleD

Date: Thursday, December 22, 2022 6:35:44 PM

Message:

Added : /branches

Revision: 30

Author: GiselleD

Date: Wednesday, December 21, 2022 3:08:02 PM

Message:

Change was made that appears to fix the problem seen previously where outward network traffic would fail. Before I had fixed this by modifying an operating system file. This was only a bandaid though. The fix here appears to have fixed the problem entirely by addressing the cause and has even boosted the speed of the network. It may not be the last update though if any problems are later discovered.

Modified : /SingleChannelMonitorBox/src/ASF/thirdparty/freertos/freertos-7.3.0/source/FreeRTOS-Plus-TCP/FreeRTOS_Sockets.c

Modified : /SingleChannelMonitorBox/src/config/FreeRTOSConfig.h

Modified : /SingleChannelMonitorBox/src/config/FreeRTOSIPConfig.h

Revision: 29

Author: GiselleD

Date: Wednesday, December 21, 2022 12:40:33 PM

Message:

Critical update was made to HexModule.c and the setpoint handler. There was an issue with the applications use of globals and a shared temperature conversion function. A thread collision issue was causing the application to crash due to stack corruption. This has probably been an issue for awhile and simply wasn't noticed until now. The globals in hex module have been removed and semaphore protection has been added to the toFahrenheit function since it is shared between modules.

Modified : /SingleChannelMonitorBox/src/ASF/sam/utils/linker_scripts/sam4s/sam4sd32/gcc/flash.ld

Modified : /SingleChannelMonitorBox/src/DisplayDriver/HexModule.c

Modified : /SingleChannelMonitorBox/src/DisplayDriver/HexModule.h

Modified : /SingleChannelMonitorBox/src/Setpoint_Handler/Setpoint_Handler.c

Modified : /SingleChannelMonitorBox/src/Setpoint_Handler/Setpoint_Handler.h

Modified : /SingleChannelMonitorBox/src/apptasks.c

Modified : /SingleChannelMonitorBox/src/config/FreeRTOSConfig.h

Modified : /websrc/index.html

Modified : /websrc/mac.json

Revision: 28

Author: GiselleD

Date: Tuesday, December 20, 2022 5:43:29 PM

Message:

Huge website update! UI has been changed to be more snazzy, the reboot feature was edited a bit, a setpoint handler was added, also the mac address wasn't being loaded at initialization and that has been addressed.

Modified : /SingleChannelMonitorBox/SingleChannelMonitorBox.cproj

Added : /SingleChannelMonitorBox/src/ASF/sam/drivers/rstc

Added : /SingleChannelMonitorBox/src/ASF/sam/drivers/rstc/rstc.c

Added : /SingleChannelMonitorBox/src/ASF/sam/drivers/rstc/rstc.h

Modified : /SingleChannelMonitorBox/src/ASF/sam/utils/linker_scripts/sam4s/sam4sd32/gcc/flash.ld

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

Modified : /SingleChannelMonitorBox/src/DisplayDriver/HexModule.c

Modified : /SingleChannelMonitorBox/src/Setpoint_Handler/Setpoint_Handler.c

Modified : /SingleChannelMonitorBox/src/Setpoint_Handler/Setpoint_Handler.h

Modified : /SingleChannelMonitorBox/src/apptasks.c

Modified : /SingleChannelMonitorBox/src/config/conf_eth.h

Added : /SingleChannelMonitorBox/temperatureSystem.txt

Modified : /websrc/css/stylesheet.css

Modified : /websrc/html/network_config.htm

Modified : /websrc/html/reboot.htm

Modified : /websrc/html/setpoint_config.htm

Modified : /websrc/index.html

Modified : /websrc/mac.json

Modified : /websrc/scripts/displayhandler.js

Added : /websrc/setpoint.txt

Added : /websrc/temperatureSystem.txt

Revision: 27

Author: GiselleD

Date: Monday, December 19, 2022 1:02:05 PM

Message:

Refactored the display driver to clean up some clumsiness. Added new comments to both the display driver and the setpoint handler.

Modified : /SingleChannelMonitorBox/src/DisplayDriver/HexModule.c

Modified : /SingleChannelMonitorBox/src/DisplayDriver/HexModule.h

Modified : /SingleChannelMonitorBox/src/Setpoint_Handler/Setpoint_Handler.c

Revision: 26

Author: GiselleD

Date: Friday, December 16, 2022 8:18:43 PM

Message:

Main accomplishments today were getting the reboot feature completely working and getting most the work done for updating the setpoint with the web server. Some changes were made to the server code, mostly just small improvements. For example, the way the setpoint was being saved wasn't optimal, and boundary checking wasn't very safe for the display hander. I made it so that no matter what temperature system is used, the display will never overflow or try to publish a setpoint that is out of bounds.

Modified : /SingleChannelMonitorBox/Debug/Makefile

Modified : /SingleChannelMonitorBox/Debug/makedep.mk

Modified : /SingleChannelMonitorBox/SingleChannelMonitorBox.cproj

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

Modified : /SingleChannelMonitorBox/src/DisplayDriver/HexModule.c

Modified : /SingleChannelMonitorBox/src/Setpoint_Handler/Setpoint_Handler.c

Modified : /SingleChannelMonitorBox/src/Setpoint_Handler/Setpoint_Handler.h

Modified : /SingleChannelMonitorBox/src/asf.h

Modified : /websrc/html/network_config.htm

Modified : /websrc/html/reboot.htm

Added : /websrc/html/setpoint_config.htm

Modified : /websrc/index.html

Modified : /websrc/scripts/displayhandler.js

Revision: 25

Author: GiselleD

Date: Thursday, December 15, 2022 8:17:00 PM

Message:

Another update, lots of the backend capability of the server has been added. IP address and other network settings are set at initialization. The http post command is in the process of being made more generic. The goal is to have POST work for a reboot command and possibly for a setpoint update command. Some changes were made to slow down the network loading speed a little bit to improve reliability. Also, lots of unnecessary project files were removed.

Modified : /SingleChannelMonitorBox/src/ASF/thirdparty/freertos/freertos-7.3.0/source/FreeRTOS-Plus-TCP/FreeRTOS_Sockets.c

Modified : /SingleChannelMonitorBox/src/ASF/thirdparty/freertos/freertos-7.3.0/source/FreeRTOS-Plus-TCP/Include/FreeRTOSIPConfigDefaults.h

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

Modified : /SingleChannelMonitorBox/src/ASF/thirdparty/freertos/freertos-7.3.0/source/FreeRTOS-Plus-TCP/protocols/include/FreeRTOS_HTTP_commands.h

Modified : /SingleChannelMonitorBox/src/apptasks.c

Modified : /SingleChannelMonitorBox/src/config/FreeRTOSIPConfig.h

Modified : /SingleChannelMonitorBox/src/config/conf_eth.h

Deleted : /websrc/css/stylesheaet.css

Deleted : /websrc/edwards-logo.jpg

Deleted : /websrc/html/cwm_advanced_config.htm

Deleted : /websrc/html/cwm_certificate_config.htm

Deleted : /websrc/html/cwm_connections_config.htm

Deleted : /websrc/html/filelist.htm

Deleted : /websrc/html/index.htm

Modified : /websrc/html/network_config.htm

Modified : /websrc/html/reboot.htm

Deleted : /websrc/html/template.htm

Deleted : /websrc/html/upload_firmware.htm

Deleted : /websrc/html/wireless_ip_config.htm

Deleted : /websrc/html/wireless_network_config.htm

Revision: 24

Author: GiselleD

Date: Tuesday, December 13, 2022 7:50:27 PM

Message:

The main update here is to the front end portion of the web server. The network settings page has been changed substantially to better suit the application and to apply proper error checking. A small update was made to the backend to change the behavior of how the settings.json file is edited. Before, it was appended to. Now it is recreated whenever the network settings form is posted.

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

Modified : /websrc/css/stylesheet.css

Modified : /websrc/html/network_config.htm

Modified : /websrc/index.html

Modified : /websrc/scripts/displayhandler.js

Modified : /websrc/settings.json

Revision: 23

Author: GiselleD

Date: Tuesday, December 13, 2022 12:29:56 PM

Message:

Fixed a bug that was mysterious for awhile. The network interface would occasionally crash on a config assert. I found out that the problem was that occasionally the network would fail to get a buffer because the semaphore wasn't available within the given timeout. I added a while loop to force the network driver to block until it gets a buffer instead of just killing the whole program. I also optimized the speed of network transmission, so now operations like loading the webpage happen about 5 times faster. I also changed the RAM back to a level suitable for a 160kB ram size instead of the 128kB. The device runs much more reliably with this amount of ram.

Modified : /SingleChannelMonitorBox/src/ASF/thirdparty/freertos/freertos-7.3.0/source/FreeRTOS-Plus-TCP/FreeRTOS_Sockets.c

Modified : /SingleChannelMonitorBox/src/ASF/thirdparty/freertos/freertos-7.3.0/source/FreeRTOS-Plus-TCP/Portable/NetworkInterface/NetworkInterface.c

Modified : /SingleChannelMonitorBox/src/config/FreeRTOSConfig.h

Modified : /SingleChannelMonitorBox/src/config/conf_eth.h

Modified : /websrc/html/network_config.htm

Modified : /websrc/settings.json

Revision: 22

Author: GiselleD

Date: Monday, December 12, 2022 5:27:30 PM

Message:

Multifile update to improve safety concerning the deleteNonWebTasks function. I was concerned that the interprocess communication could rarely cause an unrecoverable exception because of the way the threads were shut down. I guarded queuereceive and queuesend calls with null checks and I moved around the ownership of many of the queues. I changed it so that a task owns a queue if it is the one who sends data on the queue. That way when the task is shutdown, its only shutting down queues that it sends data on. I also made the shutdown functions owned by the tasks themselves and I made them blocking so that only one shutdown can occur at a time, that way I can choose the order that they are shutdown in. I noticed this caused a huge probelm with the web and ftp server because of the amount of time it would take to shutdown all tasks, so I created a special thread whose only purpose it to kill other tasks, after which it kills itself. This fixed the performance issue.

Modified : /SingleChannelMonitorBox/src/ASF/thirdparty/freertos/freertos-7.3.0/source/FreeRTOS-Plus-TCP/protocols/Common/FreeRTOS_TCP_server.c

Modified : /SingleChannelMonitorBox/src/Button_Handler/Button_Handler.c

Modified : /SingleChannelMonitorBox/src/DisplayDriver/HexModule.c

Modified : /SingleChannelMonitorBox/src/ModbusServerTCP/Include/mbport.h

Modified : /SingleChannelMonitorBox/src/ModbusServerTCP/TCP/mbport.c

Modified : /SingleChannelMonitorBox/src/Setpoint_Handler/Setpoint_Handler.c

Modified : /SingleChannelMonitorBox/src/TC_Reader/TempReadingMain.c

Modified : /SingleChannelMonitorBox/src/apptasks.c

Modified : /SingleChannelMonitorBox/src/apptasks.h

Revision: 21

Author: GiselleD

Date: Friday, December 9, 2022 8:22:41 PM

Message:

The main update here is the web interface. More error validation was added to prevent a gateway address and ip address from being on a different subnet. The application code was also updated to close the setpoint monitor, the btn driver and the other close functions were updated to free memory their respective tasks were using. The display driver was updated as well. The organization of certain elements were changed. An alarming bug was discovered that doesn't appear to be related to software. A seg module was saving its gpio incorrectly and this was causing a system crash. Its really bad because it appears to be a damaged memory cell, not something amendable in software. I just changed how it was saved and then it would read accurately again, assuming because it was using a different memory cell.

Modified : /SingleChannelMonitorBox/src/Button_Handler/Button_Handler.c

Modified : /SingleChannelMonitorBox/src/Button_Handler/Button_Handler.h

Modified : /SingleChannelMonitorBox/src/DisplayDriver/HexModule.c

Modified : /SingleChannelMonitorBox/src/Setpoint_Handler/Setpoint_Handler.c

Modified : /SingleChannelMonitorBox/src/Setpoint_Handler/Setpoint_Handler.h

Modified : /SingleChannelMonitorBox/src/TC_Reader/TempReadingMain.c

Modified : /SingleChannelMonitorBox/src/apptasks.c

Modified : /SingleChannelMonitorBox/src/config/FreeRTOSConfig.h

Modified : /SingleChannelMonitorBox/src/main.c

Modified : /websrc/html/network_config.htm

Modified : /websrc/html/reboot.htm

Modified : /websrc/scripts/displayhandler.js

Modified : /websrc/scripts/errhandler.js

Modified : /websrc/settings.json

Revision: 20

Author: GiselleD

Date: Thursday, December 8, 2022 6:31:40 PM

Message:

Added the ability to display the current temperature and setpoint in either celsius or fahrenheit. Toggling the UP button will switch between these.

Modified : /SingleChannelMonitorBox/src/DisplayDriver/HexModule.c

Modified : /SingleChannelMonitorBox/src/DisplayDriver/HexModule.h

Modified : /SingleChannelMonitorBox/src/ModbusServerTCP/Include/mbport.h

Modified : /SingleChannelMonitorBox/src/ModbusServerTCP/TCP/mbport.c

Modified : /SingleChannelMonitorBox/src/apptasks.c

Revision: 19

Author: GiselleD

Date: Thursday, December 8, 2022 3:28:10 PM

Message:

Updated setpoint handler to fix bugs and be more responsive.

Modified : /SingleChannelMonitorBox/src/Setpoint_Handler/Setpoint_Handler.c

Modified : /SingleChannelMonitorBox/src/Setpoint_Handler/Setpoint_Handler.h

Revision: 18

Author: GiselleD

Date: Wednesday, December 7, 2022 6:20:16 PM

Message:

Optimized memory and cleaned up unused headers.

Modified : /SingleChannelMonitorBox/src/ASF/thirdparty/freertos/freertos-7.3.0/source/FreeRTOS-Plus-TCP/Portable/NetworkInterface/NetworkInterface.c

Modified : /SingleChannelMonitorBox/src/Button_Handler/Button_Handler.h

Modified : /SingleChannelMonitorBox/src/DisplayDriver/HexModule.h

Modified : /SingleChannelMonitorBox/src/ModbusServerTCP/Include/mbport.h

Modified : /SingleChannelMonitorBox/src/Setpoint_Handler/Setpoint_Handler.h

Modified : /SingleChannelMonitorBox/src/TC_Reader/TempReadingMain.h

Modified : /SingleChannelMonitorBox/src/config/FreeRTOSConfig.h

Modified : /SingleChannelMonitorBox/src/config/conf_eth.h

Modified : /SingleChannelMonitorBox/src/main.c

Revision: 17

Author: GiselleD

Date: Sunday, December 4, 2022 3:00:21 PM

Message:

Basic setpoint handling has been added! There are more features to add with that but the basics appear to be working. Some refactoring was done as well.

Modified : /SingleChannelMonitorBox/src/DisplayDriver/HexModule.c

Modified : /SingleChannelMonitorBox/src/DisplayDriver/HexModule.h

Modified : /SingleChannelMonitorBox/src/Setpoint_Handler/Setpoint_Handler.c

Modified : /SingleChannelMonitorBox/src/Setpoint_Handler/Setpoint_Handler.h

Modified : /SingleChannelMonitorBox/src/TC_Reader/TempReadingMain.c

Revision: 16

Author: GiselleD

Date: Thursday, December 1, 2022 8:26:17 PM

Message:

Display handling has been added. Button handling added as well with software debouncing. The setpoint handler is started as well. Currently it only loads the current setpoint and saves it when there's a new one. Big change was made with the flash.ld file. RAM was optimized significantly, giving the application an additional 12 thousand bytes to works with! The change in init.c may not be necessary but it was added to prevent PA9 from being initialized twice.

Modified : /SingleChannelMonitorBox/Debug/Makefile

Modified : /SingleChannelMonitorBox/Debug/makedep.mk

Modified : /SingleChannelMonitorBox/SingleChannelMonitorBox.cproj

Modified : /SingleChannelMonitorBox/src/ASF/sam/boards/sam4s_xplained_pro/init.c

Modified : /SingleChannelMonitorBox/src/ASF/sam/utils/linker_scripts/sam4s/sam4sd32/gcc/flash.ld

Added : /SingleChannelMonitorBox/src/Button_Handler

Added : /SingleChannelMonitorBox/src/Button_Handler/Button_Handler.c

Added : /SingleChannelMonitorBox/src/Button_Handler/Button_Handler.h

Modified : /SingleChannelMonitorBox/src/DisplayDriver/HexModule.c

Modified : /SingleChannelMonitorBox/src/DisplayDriver/HexModule.h

Added : /SingleChannelMonitorBox/src/Setpoint_Handler

Added : /SingleChannelMonitorBox/src/Setpoint_Handler/Setpoint_Handler.c

Added : /SingleChannelMonitorBox/src/Setpoint_Handler/Setpoint_Handler.h

Modified : /SingleChannelMonitorBox/src/TC_Reader/TempReadingMain.c

Modified : /SingleChannelMonitorBox/src/TC_Reader/TempReadingMain.h

Modified : /SingleChannelMonitorBox/src/apptasks.c

Modified : /SingleChannelMonitorBox/src/config/FreeRTOSConfig.h

Revision: 15

Author: GiselleD

Date: Wednesday, November 23, 2022 4:00:39 PM

Message:

Modified : /SingleChannelMonitorBox/Debug/Makefile

Modified : /SingleChannelMonitorBox/Debug/makedep.mk

Modified : /SingleChannelMonitorBox/SingleChannelMonitorBox.cproj

Modified : /SingleChannelMonitorBox/src/ASF/thirdparty/freertos/freertos-7.3.0/source/FreeRTOS-Plus-TCP/protocols/Common/FreeRTOS_TCP_server.c

Modified : /SingleChannelMonitorBox/src/ASF/thirdparty/freertos/freertos-7.3.0/source/FreeRTOS-Plus-TCP/protocols/HTTP/FreeRTOS_HTTP_commands.c

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

Modified : /SingleChannelMonitorBox/src/ASF/thirdparty/freertos/freertos-7.3.0/source/FreeRTOS-Plus-TCP/protocols/include/FreeRTOS_HTTP_commands.h

Modified : /SingleChannelMonitorBox/src/ASF/thirdparty/freertos/freertos-7.3.0/source/include/FF_include/FreeRTOSFATConfig.h

Deleted : /SingleChannelMonitorBox/src/CreateAndVerifyExampleFiles.c

Deleted : /SingleChannelMonitorBox/src/DefaultWebPages.h

Modified : /SingleChannelMonitorBox/src/DisplayDriver/HexModule.c

Modified : /SingleChannelMonitorBox/src/DisplayDriver/HexModule.h

Modified : /SingleChannelMonitorBox/src/ModbusServerTCP/Include/mbport.h

Modified : /SingleChannelMonitorBox/src/ModbusServerTCP/TCP/mbport.c

Modified : /SingleChannelMonitorBox/src/TC_Reader/TempReadingMain.c

Modified : /SingleChannelMonitorBox/src/TC_Reader/TempReadingMain.h

Modified : /SingleChannelMonitorBox/src/apptasks.c

Modified : /SingleChannelMonitorBox/src/apptasks.h

Added : /SingleChannelMonitorBox/src/cJSON

Added : /SingleChannelMonitorBox/src/cJSON/cJSON.c

Added : /SingleChannelMonitorBox/src/cJSON/cJSON.h

Modified : /SingleChannelMonitorBox/src/config/conf_eth.h

Modified : /SingleChannelMonitorBox/src/main.c

Added : /websrc

Added : /websrc/css

Added : /websrc/css/stylesheaet.css

Added : /websrc/css/stylesheet.css

Added : /websrc/edwards-logo.GIF

Added : /websrc/edwards-logo.jpg

Added : /websrc/help

Added : /websrc/help/cwm_config_help.htm

Added : /websrc/html

Added : /websrc/html/cwm_advanced_config.htm

Added : /websrc/html/cwm_certificate_config.htm

Added : /websrc/html/cwm_connections_config.htm

Added : /websrc/html/filelist.htm

Added : /websrc/html/index.htm

Added : /websrc/html/network_config.htm

Added : /websrc/html/reboot.htm

Added : /websrc/html/reboot_status.htm

Added : /websrc/html/template.htm

Added : /websrc/html/upload_firmware.htm

Added : /websrc/html/wireless_ip_config.htm

Added : /websrc/html/wireless_network_config.htm

Added : /websrc/img

Added : /websrc/img/back.gif

Added : /websrc/img/back_off.gif

Added : /websrc/img/edwards-big-logo.jpg

Added : /websrc/img/edwards-logo.png

Added : /websrc/img/forward.gif

Added : /websrc/img/forward_off.gif

Added : /websrc/img/help.gif

Added : /websrc/img/logo.gif

Added : /websrc/img/tabclose.gif

Added : /websrc/img/tabopen.gif

Added : /websrc/index.html

Added : /websrc/mac.json

Added : /websrc/scripts

Added : /websrc/scripts/displayhandler.js

Added : /websrc/scripts/errhandler.js

Added : /websrc/scripts/utils.js

Added : /websrc/scripts/validation.js

Added : /websrc/settings.json

Revision: 14

Author: GiselleD

Date: Tuesday, November 8, 2022 12:58:38 PM

Message:

Added a fix for data streaming from the http and ftp servers. The network interface has a limit to the number of bytes it can process and how quickly it can process. I modified a the tcp send and a function that returns buffer space available for transmit. I put a limit on the amount of bytes that can be streamed (no more than 1024) and I added a delay to tcp send so that any module that tries to stream will do so successfully, given the constraints with the network driver.

Modified : /SingleChannelMonitorBox/src/ASF/thirdparty/freertos/freertos-7.3.0/source/FreeRTOS-Plus-TCP/FreeRTOS_Sockets.c

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

Modified : /SingleChannelMonitorBox/src/config/FreeRTOSConfig.h

Modified : /SingleChannelMonitorBox/src/main.c

Revision: 13

Author: GiselleD

Date: Monday, November 7, 2022 7:25:39 PM

Message:

These files were removed from their directory and moved elsewhere. Forgot to include this in previous commit.

Deleted : /SingleChannelMonitorBox/src/ASF/thirdparty/freertos/freertos-7.3.0/source/FreeRTOS_ARP.c

Deleted : /SingleChannelMonitorBox/src/ASF/thirdparty/freertos/freertos-7.3.0/source/FreeRTOS_DHCP.c

Deleted : /SingleChannelMonitorBox/src/ASF/thirdparty/freertos/freertos-7.3.0/source/FreeRTOS_DNS.c

Deleted : /SingleChannelMonitorBox/src/ASF/thirdparty/freertos/freertos-7.3.0/source/FreeRTOS_IP.c

Deleted : /SingleChannelMonitorBox/src/ASF/thirdparty/freertos/freertos-7.3.0/source/FreeRTOS_Sockets.c

Deleted : /SingleChannelMonitorBox/src/ASF/thirdparty/freertos/freertos-7.3.0/source/FreeRTOS_Stream_Buffer.c

Deleted : /SingleChannelMonitorBox/src/ASF/thirdparty/freertos/freertos-7.3.0/source/FreeRTOS_TCP_IP.c

Deleted : /SingleChannelMonitorBox/src/ASF/thirdparty/freertos/freertos-7.3.0/source/FreeRTOS_TCP_WIN.c

Deleted : /SingleChannelMonitorBox/src/ASF/thirdparty/freertos/freertos-7.3.0/source/FreeRTOS_UDP_IP.c

Deleted : /SingleChannelMonitorBox/src/ASF/thirdparty/freertos/freertos-7.3.0/source/include/FreeRTOSFATConfig.h

Deleted : /SingleChannelMonitorBox/src/ASF/thirdparty/freertos/freertos-7.3.0/source/include/FreeRTOSFATConfigDefaults.h

Deleted : /SingleChannelMonitorBox/src/ASF/thirdparty/freertos/freertos-7.3.0/source/include/FreeRTOSIPConfigDefaults.h

Deleted : /SingleChannelMonitorBox/src/ASF/thirdparty/freertos/freertos-7.3.0/source/include/FreeRTOS_ARP.h

Deleted : /SingleChannelMonitorBox/src/ASF/thirdparty/freertos/freertos-7.3.0/source/include/FreeRTOS_DHCP.h

Deleted : /SingleChannelMonitorBox/src/ASF/thirdparty/freertos/freertos-7.3.0/source/include/FreeRTOS_DNS.h

Deleted : /SingleChannelMonitorBox/src/ASF/thirdparty/freertos/freertos-7.3.0/source/include/FreeRTOS_IP.h

Deleted : /SingleChannelMonitorBox/src/ASF/thirdparty/freertos/freertos-7.3.0/source/include/FreeRTOS_IP_Private.h

Deleted : /SingleChannelMonitorBox/src/ASF/thirdparty/freertos/freertos-7.3.0/source/include/FreeRTOS_Sockets.h

Deleted : /SingleChannelMonitorBox/src/ASF/thirdparty/freertos/freertos-7.3.0/source/include/FreeRTOS_Stream_Buffer.h

Deleted : /SingleChannelMonitorBox/src/ASF/thirdparty/freertos/freertos-7.3.0/source/include/FreeRTOS_TCP_IP.h

Deleted : /SingleChannelMonitorBox/src/ASF/thirdparty/freertos/freertos-7.3.0/source/include/FreeRTOS_TCP_WIN.h

Deleted : /SingleChannelMonitorBox/src/ASF/thirdparty/freertos/freertos-7.3.0/source/include/FreeRTOS_UDP_IP.h

Deleted : /SingleChannelMonitorBox/src/ASF/thirdparty/freertos/freertos-7.3.0/source/include/FreeRTOS_errno_FAT.h

Deleted : /SingleChannelMonitorBox/src/ASF/thirdparty/freertos/freertos-7.3.0/source/include/FreeRTOS_errno_TCP.h

Deleted : /SingleChannelMonitorBox/src/ASF/thirdparty/freertos/freertos-7.3.0/source/include/IPTraceMacroDefaults.h

Deleted : /SingleChannelMonitorBox/src/ASF/thirdparty/freertos/freertos-7.3.0/source/include/NetworkBufferManagement.h

Deleted : /SingleChannelMonitorBox/src/ASF/thirdparty/freertos/freertos-7.3.0/source/include/ff_crc.h

Deleted : /SingleChannelMonitorBox/src/ASF/thirdparty/freertos/freertos-7.3.0/source/include/ff_devices.h

Deleted : /SingleChannelMonitorBox/src/ASF/thirdparty/freertos/freertos-7.3.0/source/include/ff_dir.h

Deleted : /SingleChannelMonitorBox/src/ASF/thirdparty/freertos/freertos-7.3.0/source/include/ff_error.h

Deleted : /SingleChannelMonitorBox/src/ASF/thirdparty/freertos/freertos-7.3.0/source/include/ff_fat.h

Deleted : /SingleChannelMonitorBox/src/ASF/thirdparty/freertos/freertos-7.3.0/source/include/ff_fatdef.h

Deleted : /SingleChannelMonitorBox/src/ASF/thirdparty/freertos/freertos-7.3.0/source/include/ff_file.h

Deleted : /SingleChannelMonitorBox/src/ASF/thirdparty/freertos/freertos-7.3.0/source/include/ff_format.h

Deleted : /SingleChannelMonitorBox/src/ASF/thirdparty/freertos/freertos-7.3.0/source/include/ff_headers.h

Deleted : /SingleChannelMonitorBox/src/ASF/thirdparty/freertos/freertos-7.3.0/source/include/ff_ioman.h

Deleted : /SingleChannelMonitorBox/src/ASF/thirdparty/freertos/freertos-7.3.0/source/include/ff_locking.h

Deleted : /SingleChannelMonitorBox/src/ASF/thirdparty/freertos/freertos-7.3.0/source/include/ff_memory.h

Deleted : /SingleChannelMonitorBox/src/ASF/thirdparty/freertos/freertos-7.3.0/source/include/ff_old_config_defines.h

Deleted : /SingleChannelMonitorBox/src/ASF/thirdparty/freertos/freertos-7.3.0/source/include/ff_stdio.h

Deleted : /SingleChannelMonitorBox/src/ASF/thirdparty/freertos/freertos-7.3.0/source/include/ff_string.h

Deleted : /SingleChannelMonitorBox/src/ASF/thirdparty/freertos/freertos-7.3.0/source/include/ff_sys.h

Deleted : /SingleChannelMonitorBox/src/ASF/thirdparty/freertos/freertos-7.3.0/source/include/ff_time.h

Deleted : /SingleChannelMonitorBox/src/ASF/thirdparty/freertos/freertos-7.3.0/source/portable/BufferManagement

Deleted : /SingleChannelMonitorBox/src/ASF/thirdparty/freertos/freertos-7.3.0/source/portable/NetworkInterface

Deleted : /SingleChannelMonitorBox/src/ASF/thirdparty/freertos/freertos-7.3.0/source/portable/gcc

Deleted : /SingleChannelMonitorBox/src/SimpleTCPEchoServer.c

Deleted : /SingleChannelMonitorBox/src/SimpleTCPEchoServer.h

Revision: 12

Author: GiselleD

Date: Monday, November 7, 2022 7:21:58 PM

Message:

TCP directories were organized in a more logical way, a preliminary nand flash driver is included. It is not validated but could work someday if necessary. Support for an SD card was added. FTP and web server is running but can only handle small files. Some bug is present that prevents transmission of large packets. Probably an issue with NetworkInterface since it was never tested with large data streams.

Modified : /SingleChannelMonitorBox/Debug/Makefile

Modified : /SingleChannelMonitorBox/Debug/makedep.mk

Added : /SingleChannelMonitorBox/Debug/src/ASF/common/components

Added : /SingleChannelMonitorBox/Debug/src/ASF/common/components/memory

Added : /SingleChannelMonitorBox/Debug/src/ASF/common/components/memory/nand_flash

Added : /SingleChannelMonitorBox/Debug/src/ASF/common/components/memory/nand_flash/nand_flash_ebi

Added : /SingleChannelMonitorBox/Debug/src/ASF/common/components/memory/nand_flash/nand_flash_ebi/ftl_lib

Added : /SingleChannelMonitorBox/Debug/src/ASF/common/components/memory/nand_flash/nand_flash_ebi/ftl_lib/gcc

Added : /SingleChannelMonitorBox/Debug/src/ASF/common/components/memory/sd_mmc

Added : /SingleChannelMonitorBox/Debug/src/ASF/common/services/storage

Added : /SingleChannelMonitorBox/Debug/src/ASF/common/services/storage/ctrl_access

Added : /SingleChannelMonitorBox/Debug/src/ASF/common/services/storage/ecc_hamming

Added : /SingleChannelMonitorBox/Debug/src/ASF/sam/drivers/ebi

Added : /SingleChannelMonitorBox/Debug/src/ASF/sam/drivers/ebi/smc

Added : /SingleChannelMonitorBox/Debug/src/ASF/sam/drivers/hsmci

Added : /SingleChannelMonitorBox/Debug/src/ASF/sam/drivers/matrix

Added : /SingleChannelMonitorBox/Debug/src/ASF/sam/utils/fpu

Added : /SingleChannelMonitorBox/Debug/src/ASF/thirdparty/freertos/freertos-7.3.0/source/FF_Source

Added : /SingleChannelMonitorBox/Debug/src/ASF/thirdparty/freertos/freertos-7.3.0/source/FF_Source/FF_Portable

Added : /SingleChannelMonitorBox/Debug/src/ASF/thirdparty/freertos/freertos-7.3.0/source/FreeRTOS-Plus-TCP

Added : /SingleChannelMonitorBox/Debug/src/ASF/thirdparty/freertos/freertos-7.3.0/source/FreeRTOS-Plus-TCP/Include

Added : /SingleChannelMonitorBox/Debug/src/ASF/thirdparty/freertos/freertos-7.3.0/source/FreeRTOS-Plus-TCP/Portable

Added : /SingleChannelMonitorBox/Debug/src/ASF/thirdparty/freertos/freertos-7.3.0/source/FreeRTOS-Plus-TCP/Portable/BufferManagement

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

Added : /SingleChannelMonitorBox/Debug/src/ASF/thirdparty/freertos/freertos-7.3.0/source/FreeRTOS-Plus-TCP/Portable/gcc

Added : /SingleChannelMonitorBox/Debug/src/ASF/thirdparty/freertos/freertos-7.3.0/source/FreeRTOS-Plus-TCP/Portable/gcc/sam

Added : /SingleChannelMonitorBox/Debug/src/ASF/thirdparty/freertos/freertos-7.3.0/source/FreeRTOS-Plus-TCP/protocols

Added : /SingleChannelMonitorBox/Debug/src/ASF/thirdparty/freertos/freertos-7.3.0/source/FreeRTOS-Plus-TCP/protocols/Common

Added : /SingleChannelMonitorBox/Debug/src/ASF/thirdparty/freertos/freertos-7.3.0/source/FreeRTOS-Plus-TCP/protocols/FTP

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

Added : /SingleChannelMonitorBox/Debug/src/ASF/thirdparty/freertos/freertos-7.3.0/source/FreeRTOS-Plus-TCP/protocols/include

Added : /SingleChannelMonitorBox/Debug/src/ASF/thirdparty/freertos/freertos-7.3.0/source/FreeRTOS_Plus_CLI_Demos

Added : /SingleChannelMonitorBox/Debug/src/ASF/thirdparty/freertos/freertos-7.3.0/source/FreeRTOS_Plus_CLI_Demos/include

Added : /SingleChannelMonitorBox/Debug/src/ASF/thirdparty/freertos/freertos-7.3.0/source/include/FF_include

Modified : /SingleChannelMonitorBox/SingleChannelMonitorBox.cproj

Added : /SingleChannelMonitorBox/src/ASF/common/components

Added : /SingleChannelMonitorBox/src/ASF/common/components/memory

Added : /SingleChannelMonitorBox/src/ASF/common/components/memory/nand_flash

Added : /SingleChannelMonitorBox/src/ASF/common/components/memory/nand_flash/nand_flash_ebi

Added : /SingleChannelMonitorBox/src/ASF/common/components/memory/nand_flash/nand_flash_ebi/ftl_lib

Added : /SingleChannelMonitorBox/src/ASF/common/components/memory/nand_flash/nand_flash_ebi/ftl_lib/gcc

Added : /SingleChannelMonitorBox/src/ASF/common/components/memory/nand_flash/nand_flash_ebi/ftl_lib/nand_flash_management.h

Added : /SingleChannelMonitorBox/src/ASF/common/components/memory/nand_flash/nand_flash_ebi/ftl_lib/nand_flash_mem.c

Added : /SingleChannelMonitorBox/src/ASF/common/components/memory/nand_flash/nand_flash_ebi/ftl_lib/nand_flash_mem.h

Added : /SingleChannelMonitorBox/src/ASF/common/components/memory/nand_flash/nand_flash_ebi/ftl_lib/nand_flash_translation.h

Added : /SingleChannelMonitorBox/src/ASF/common/components/memory/nand_flash/nand_flash_ebi/nand_flash_common.h

Added : /SingleChannelMonitorBox/src/ASF/common/components/memory/nand_flash/nand_flash_ebi/nand_flash_ecc.h

Added : /SingleChannelMonitorBox/src/ASF/common/components/memory/nand_flash/nand_flash_ebi/nand_flash_ecc_sw.c

Added : /SingleChannelMonitorBox/src/ASF/common/components/memory/nand_flash/nand_flash_ebi/nand_flash_model.c

Added : /SingleChannelMonitorBox/src/ASF/common/components/memory/nand_flash/nand_flash_ebi/nand_flash_model.h

Added : /SingleChannelMonitorBox/src/ASF/common/components/memory/nand_flash/nand_flash_ebi/nand_flash_raw.h

Added : /SingleChannelMonitorBox/src/ASF/common/components/memory/nand_flash/nand_flash_ebi/nand_flash_raw_smc.c

Added : /SingleChannelMonitorBox/src/ASF/common/components/memory/nand_flash/nand_flash_ebi/nand_flash_spare_scheme.c

Added : /SingleChannelMonitorBox/src/ASF/common/components/memory/nand_flash/nand_flash_ebi/nand_flash_spare_scheme.h

Added : /SingleChannelMonitorBox/src/ASF/common/components/memory/sd_mmc

Added : /SingleChannelMonitorBox/src/ASF/common/components/memory/sd_mmc/sd_mmc_mem.c

Added : /SingleChannelMonitorBox/src/ASF/common/components/memory/sd_mmc/sd_mmc_mem.h

Added : /SingleChannelMonitorBox/src/ASF/common/components/memory/sd_mmc.c

Added : /SingleChannelMonitorBox/src/ASF/common/components/memory/sd_mmc.h

Added : /SingleChannelMonitorBox/src/ASF/common/components/memory/sd_mmc_protocol.h

Added : /SingleChannelMonitorBox/src/ASF/common/services/storage

Added : /SingleChannelMonitorBox/src/ASF/common/services/storage/ctrl_access

Added : /SingleChannelMonitorBox/src/ASF/common/services/storage/ctrl_access/ctrl_access.c

Added : /SingleChannelMonitorBox/src/ASF/common/services/storage/ctrl_access/ctrl_access.h

Added : /SingleChannelMonitorBox/src/ASF/common/services/storage/ecc_hamming

Added : /SingleChannelMonitorBox/src/ASF/common/services/storage/ecc_hamming/ecc-sw.c

Added : /SingleChannelMonitorBox/src/ASF/common/services/storage/ecc_hamming/ecc-sw.h

Modified : /SingleChannelMonitorBox/src/ASF/sam/boards/sam4s_xplained_pro/init.c

Modified : /SingleChannelMonitorBox/src/ASF/sam/boards/sam4s_xplained_pro/sam4s_xplained_pro.h

Added : /SingleChannelMonitorBox/src/ASF/sam/drivers/ebi

Added : /SingleChannelMonitorBox/src/ASF/sam/drivers/ebi/smc

Added : /SingleChannelMonitorBox/src/ASF/sam/drivers/ebi/smc/smc.c

Added : /SingleChannelMonitorBox/src/ASF/sam/drivers/ebi/smc/smc.h

Added : /SingleChannelMonitorBox/src/ASF/sam/drivers/hsmci

Added : /SingleChannelMonitorBox/src/ASF/sam/drivers/hsmci/hsmci.c

Added : /SingleChannelMonitorBox/src/ASF/sam/drivers/hsmci/hsmci.h

Added : /SingleChannelMonitorBox/src/ASF/sam/drivers/matrix

Added : /SingleChannelMonitorBox/src/ASF/sam/drivers/matrix/matrix.c

Added : /SingleChannelMonitorBox/src/ASF/sam/drivers/matrix/matrix.h

Modified : /SingleChannelMonitorBox/src/ASF/sam/drivers/spi/spi_mutex.c

Added : /SingleChannelMonitorBox/src/ASF/sam/utils/fpu

Added : /SingleChannelMonitorBox/src/ASF/sam/utils/fpu/fpu.h

Added : /SingleChannelMonitorBox/src/ASF/thirdparty/freertos/freertos-7.3.0/source/FF_Source

Added : /SingleChannelMonitorBox/src/ASF/thirdparty/freertos/freertos-7.3.0/source/FF_Source/FF_Portable

Added : /SingleChannelMonitorBox/src/ASF/thirdparty/freertos/freertos-7.3.0/source/FF_Source/FF_Portable/ff_nanddisk.c

Added : /SingleChannelMonitorBox/src/ASF/thirdparty/freertos/freertos-7.3.0/source/FF_Source/FF_Portable/ff_nanddisk.h

Added : /SingleChannelMonitorBox/src/ASF/thirdparty/freertos/freertos-7.3.0/source/FF_Source/FF_Portable/ff_ramdisk.c

Added : /SingleChannelMonitorBox/src/ASF/thirdparty/freertos/freertos-7.3.0/source/FF_Source/FF_Portable/ff_ramdisk.h

Added : /SingleChannelMonitorBox/src/ASF/thirdparty/freertos/freertos-7.3.0/source/FF_Source/FF_Portable/ff_sddisk.c

Added : /SingleChannelMonitorBox/src/ASF/thirdparty/freertos/freertos-7.3.0/source/FF_Source/FF_Portable/ff_sddisk.h

Added : /SingleChannelMonitorBox/src/ASF/thirdparty/freertos/freertos-7.3.0/source/FF_Source/ff_crc.c

Added : /SingleChannelMonitorBox/src/ASF/thirdparty/freertos/freertos-7.3.0/source/FF_Source/ff_dir.c

Added : /SingleChannelMonitorBox/src/ASF/thirdparty/freertos/freertos-7.3.0/source/FF_Source/ff_error.c

Added : /SingleChannelMonitorBox/src/ASF/thirdparty/freertos/freertos-7.3.0/source/FF_Source/ff_fat.c

Added : /SingleChannelMonitorBox/src/ASF/thirdparty/freertos/freertos-7.3.0/source/FF_Source/ff_file.c

Added : /SingleChannelMonitorBox/src/ASF/thirdparty/freertos/freertos-7.3.0/source/FF_Source/ff_format.c

Added : /SingleChannelMonitorBox/src/ASF/thirdparty/freertos/freertos-7.3.0/source/FF_Source/ff_ioman.c

Added : /SingleChannelMonitorBox/src/ASF/thirdparty/freertos/freertos-7.3.0/source/FF_Source/ff_locking.c

Added : /SingleChannelMonitorBox/src/ASF/thirdparty/freertos/freertos-7.3.0/source/FF_Source/ff_memory.c

Added : /SingleChannelMonitorBox/src/ASF/thirdparty/freertos/freertos-7.3.0/source/FF_Source/ff_stdio.c

Added : /SingleChannelMonitorBox/src/ASF/thirdparty/freertos/freertos-7.3.0/source/FF_Source/ff_string.c

Added : /SingleChannelMonitorBox/src/ASF/thirdparty/freertos/freertos-7.3.0/source/FF_Source/ff_sys.c

Added : /SingleChannelMonitorBox/src/ASF/thirdparty/freertos/freertos-7.3.0/source/FF_Source/ff_time.c

Added : /SingleChannelMonitorBox/src/ASF/thirdparty/freertos/freertos-7.3.0/source/FreeRTOS-Plus-TCP

Added : /SingleChannelMonitorBox/src/ASF/thirdparty/freertos/freertos-7.3.0/source/FreeRTOS-Plus-TCP/FreeRTOS_ARP.c

Added : /SingleChannelMonitorBox/src/ASF/thirdparty/freertos/freertos-7.3.0/source/FreeRTOS-Plus-TCP/FreeRTOS_DHCP.c

Added : /SingleChannelMonitorBox/src/ASF/thirdparty/freertos/freertos-7.3.0/source/FreeRTOS-Plus-TCP/FreeRTOS_DNS.c

Added : /SingleChannelMonitorBox/src/ASF/thirdparty/freertos/freertos-7.3.0/source/FreeRTOS-Plus-TCP/FreeRTOS_IP.c

Added : /SingleChannelMonitorBox/src/ASF/thirdparty/freertos/freertos-7.3.0/source/FreeRTOS-Plus-TCP/FreeRTOS_Sockets.c

Added : /SingleChannelMonitorBox/src/ASF/thirdparty/freertos/freertos-7.3.0/source/FreeRTOS-Plus-TCP/FreeRTOS_Stream_Buffer.c

Added : /SingleChannelMonitorBox/src/ASF/thirdparty/freertos/freertos-7.3.0/source/FreeRTOS-Plus-TCP/FreeRTOS_TCP_IP.c

Added : /SingleChannelMonitorBox/src/ASF/thirdparty/freertos/freertos-7.3.0/source/FreeRTOS-Plus-TCP/FreeRTOS_TCP_WIN.c

Added : /SingleChannelMonitorBox/src/ASF/thirdparty/freertos/freertos-7.3.0/source/FreeRTOS-Plus-TCP/FreeRTOS_UDP_IP.c

Added : /SingleChannelMonitorBox/src/ASF/thirdparty/freertos/freertos-7.3.0/source/FreeRTOS-Plus-TCP/Include

Added : /SingleChannelMonitorBox/src/ASF/thirdparty/freertos/freertos-7.3.0/source/FreeRTOS-Plus-TCP/Include/FreeRTOSIPConfigDefaults.h

Added : /SingleChannelMonitorBox/src/ASF/thirdparty/freertos/freertos-7.3.0/source/FreeRTOS-Plus-TCP/Include/FreeRTOS_ARP.h

Added : /SingleChannelMonitorBox/src/ASF/thirdparty/freertos/freertos-7.3.0/source/FreeRTOS-Plus-TCP/Include/FreeRTOS_DHCP.h

Added : /SingleChannelMonitorBox/src/ASF/thirdparty/freertos/freertos-7.3.0/source/FreeRTOS-Plus-TCP/Include/FreeRTOS_DNS.h

Added : /SingleChannelMonitorBox/src/ASF/thirdparty/freertos/freertos-7.3.0/source/FreeRTOS-Plus-TCP/Include/FreeRTOS_IP.h

Added : /SingleChannelMonitorBox/src/ASF/thirdparty/freertos/freertos-7.3.0/source/FreeRTOS-Plus-TCP/Include/FreeRTOS_IP_Private.h

Added : /SingleChannelMonitorBox/src/ASF/thirdparty/freertos/freertos-7.3.0/source/FreeRTOS-Plus-TCP/Include/FreeRTOS_Sockets.h

Added : /SingleChannelMonitorBox/src/ASF/thirdparty/freertos/freertos-7.3.0/source/FreeRTOS-Plus-TCP/Include/FreeRTOS_Stream_Buffer.h

Added : /SingleChannelMonitorBox/src/ASF/thirdparty/freertos/freertos-7.3.0/source/FreeRTOS-Plus-TCP/Include/FreeRTOS_TCP_IP.h

Added : /SingleChannelMonitorBox/src/ASF/thirdparty/freertos/freertos-7.3.0/source/FreeRTOS-Plus-TCP/Include/FreeRTOS_TCP_WIN.h

Added : /SingleChannelMonitorBox/src/ASF/thirdparty/freertos/freertos-7.3.0/source/FreeRTOS-Plus-TCP/Include/FreeRTOS_UDP_IP.h

Added : /SingleChannelMonitorBox/src/ASF/thirdparty/freertos/freertos-7.3.0/source/FreeRTOS-Plus-TCP/Include/FreeRTOS_errno_TCP.h

Added : /SingleChannelMonitorBox/src/ASF/thirdparty/freertos/freertos-7.3.0/source/FreeRTOS-Plus-TCP/Include/IPTraceMacroDefaults.h

Added : /SingleChannelMonitorBox/src/ASF/thirdparty/freertos/freertos-7.3.0/source/FreeRTOS-Plus-TCP/Include/NetworkBufferManagement.h

Added : /SingleChannelMonitorBox/src/ASF/thirdparty/freertos/freertos-7.3.0/source/FreeRTOS-Plus-TCP/Portable

Added : /SingleChannelMonitorBox/src/ASF/thirdparty/freertos/freertos-7.3.0/source/FreeRTOS-Plus-TCP/Portable/BufferManagement

Added : /SingleChannelMonitorBox/src/ASF/thirdparty/freertos/freertos-7.3.0/source/FreeRTOS-Plus-TCP/Portable/BufferManagement/BufferAllocation_1.c

Added : /SingleChannelMonitorBox/src/ASF/thirdparty/freertos/freertos-7.3.0/source/FreeRTOS-Plus-TCP/Portable/BufferManagement/BufferAllocation_2.c

Added : /SingleChannelMonitorBox/src/ASF/thirdparty/freertos/freertos-7.3.0/source/FreeRTOS-Plus-TCP/Portable/NetworkInterface

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

Added : /SingleChannelMonitorBox/src/ASF/thirdparty/freertos/freertos-7.3.0/source/FreeRTOS-Plus-TCP/Portable/NetworkInterface/NetworkInterface.h

Added : /SingleChannelMonitorBox/src/ASF/thirdparty/freertos/freertos-7.3.0/source/FreeRTOS-Plus-TCP/Portable/NetworkInterface/ksz8851snl.c

Added : /SingleChannelMonitorBox/src/ASF/thirdparty/freertos/freertos-7.3.0/source/FreeRTOS-Plus-TCP/Portable/NetworkInterface/ksz8851snl.h

Added : /SingleChannelMonitorBox/src/ASF/thirdparty/freertos/freertos-7.3.0/source/FreeRTOS-Plus-TCP/Portable/NetworkInterface/ksz8851snl_reg.h

Added : /SingleChannelMonitorBox/src/ASF/thirdparty/freertos/freertos-7.3.0/source/FreeRTOS-Plus-TCP/Portable/NetworkInterface/random.h

Added : /SingleChannelMonitorBox/src/ASF/thirdparty/freertos/freertos-7.3.0/source/FreeRTOS-Plus-TCP/Portable/gcc

Added : /SingleChannelMonitorBox/src/ASF/thirdparty/freertos/freertos-7.3.0/source/FreeRTOS-Plus-TCP/Portable/gcc/pack_struct_end.h

Added : /SingleChannelMonitorBox/src/ASF/thirdparty/freertos/freertos-7.3.0/source/FreeRTOS-Plus-TCP/Portable/gcc/pack_struct_start.h

Added : /SingleChannelMonitorBox/src/ASF/thirdparty/freertos/freertos-7.3.0/source/FreeRTOS-Plus-TCP/Portable/gcc/sam

Added : /SingleChannelMonitorBox/src/ASF/thirdparty/freertos/freertos-7.3.0/source/FreeRTOS-Plus-TCP/Portable/gcc/sam/port.c

Added : /SingleChannelMonitorBox/src/ASF/thirdparty/freertos/freertos-7.3.0/source/FreeRTOS-Plus-TCP/Portable/gcc/sam/portmacro.h

Added : /SingleChannelMonitorBox/src/ASF/thirdparty/freertos/freertos-7.3.0/source/FreeRTOS-Plus-TCP/protocols

Added : /SingleChannelMonitorBox/src/ASF/thirdparty/freertos/freertos-7.3.0/source/FreeRTOS-Plus-TCP/protocols/Common

Added : /SingleChannelMonitorBox/src/ASF/thirdparty/freertos/freertos-7.3.0/source/FreeRTOS-Plus-TCP/protocols/Common/FreeRTOS_TCP_server.c

Added : /SingleChannelMonitorBox/src/ASF/thirdparty/freertos/freertos-7.3.0/source/FreeRTOS-Plus-TCP/protocols/FTP

Added : /SingleChannelMonitorBox/src/ASF/thirdparty/freertos/freertos-7.3.0/source/FreeRTOS-Plus-TCP/protocols/FTP/FreeRTOS_FTP_commands.c

Added : /SingleChannelMonitorBox/src/ASF/thirdparty/freertos/freertos-7.3.0/source/FreeRTOS-Plus-TCP/protocols/FTP/FreeRTOS_FTP_server.c

Added : /SingleChannelMonitorBox/src/ASF/thirdparty/freertos/freertos-7.3.0/source/FreeRTOS-Plus-TCP/protocols/HTTP

Added : /SingleChannelMonitorBox/src/ASF/thirdparty/freertos/freertos-7.3.0/source/FreeRTOS-Plus-TCP/protocols/HTTP/FreeRTOS_HTTP_commands.c

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

Added : /SingleChannelMonitorBox/src/ASF/thirdparty/freertos/freertos-7.3.0/source/FreeRTOS-Plus-TCP/protocols/include

Added : /SingleChannelMonitorBox/src/ASF/thirdparty/freertos/freertos-7.3.0/source/FreeRTOS-Plus-TCP/protocols/include/FreeRTOS_FTP_commands.h

Added : /SingleChannelMonitorBox/src/ASF/thirdparty/freertos/freertos-7.3.0/source/FreeRTOS-Plus-TCP/protocols/include/FreeRTOS_HTTP_commands.h

Added : /SingleChannelMonitorBox/src/ASF/thirdparty/freertos/freertos-7.3.0/source/FreeRTOS-Plus-TCP/protocols/include/FreeRTOS_TCP_server.h

Added : /SingleChannelMonitorBox/src/ASF/thirdparty/freertos/freertos-7.3.0/source/FreeRTOS-Plus-TCP/protocols/include/FreeRTOS_server_private.h

Added : /SingleChannelMonitorBox/src/ASF/thirdparty/freertos/freertos-7.3.0/source/FreeRTOS_Plus_CLI_Demos

Added : /SingleChannelMonitorBox/src/ASF/thirdparty/freertos/freertos-7.3.0/source/FreeRTOS_Plus_CLI_Demos/File-related-CLI-commands.c

Added : /SingleChannelMonitorBox/src/ASF/thirdparty/freertos/freertos-7.3.0/source/FreeRTOS_Plus_CLI_Demos/Sample-CLI-commands.c

Added : /SingleChannelMonitorBox/src/ASF/thirdparty/freertos/freertos-7.3.0/source/FreeRTOS_Plus_CLI_Demos/TCP-related-CLI-commands.c

Added : /SingleChannelMonitorBox/src/ASF/thirdparty/freertos/freertos-7.3.0/source/FreeRTOS_Plus_CLI_Demos/TCPCommandConsole.c

Added : /SingleChannelMonitorBox/src/ASF/thirdparty/freertos/freertos-7.3.0/source/FreeRTOS_Plus_CLI_Demos/UDPCommandConsole.c

Added : /SingleChannelMonitorBox/src/ASF/thirdparty/freertos/freertos-7.3.0/source/FreeRTOS_Plus_CLI_Demos/include

Added : /SingleChannelMonitorBox/src/ASF/thirdparty/freertos/freertos-7.3.0/source/FreeRTOS_Plus_CLI_Demos/include/TCPCommandConsole.h

Added : /SingleChannelMonitorBox/src/ASF/thirdparty/freertos/freertos-7.3.0/source/FreeRTOS_Plus_CLI_Demos/include/UDPCommandConsole.h

Added : /SingleChannelMonitorBox/src/ASF/thirdparty/freertos/freertos-7.3.0/source/UDPLoggingPrintf.c

Added : /SingleChannelMonitorBox/src/ASF/thirdparty/freertos/freertos-7.3.0/source/include/FF_include

Added : /SingleChannelMonitorBox/src/ASF/thirdparty/freertos/freertos-7.3.0/source/include/FF_include/FreeRTOSFATConfig.h

Added : /SingleChannelMonitorBox/src/ASF/thirdparty/freertos/freertos-7.3.0/source/include/FF_include/FreeRTOSFATConfigDefaults.h

Added : /SingleChannelMonitorBox/src/ASF/thirdparty/freertos/freertos-7.3.0/source/include/FF_include/FreeRTOS_errno_FAT.h

Added : /SingleChannelMonitorBox/src/ASF/thirdparty/freertos/freertos-7.3.0/source/include/FF_include/ff_crc.h

Added : /SingleChannelMonitorBox/src/ASF/thirdparty/freertos/freertos-7.3.0/source/include/FF_include/ff_devices.h

Added : /SingleChannelMonitorBox/src/ASF/thirdparty/freertos/freertos-7.3.0/source/include/FF_include/ff_dir.h

Added : /SingleChannelMonitorBox/src/ASF/thirdparty/freertos/freertos-7.3.0/source/include/FF_include/ff_error.h

Added : /SingleChannelMonitorBox/src/ASF/thirdparty/freertos/freertos-7.3.0/source/include/FF_include/ff_fat.h

Added : /SingleChannelMonitorBox/src/ASF/thirdparty/freertos/freertos-7.3.0/source/include/FF_include/ff_fatdef.h

Added : /SingleChannelMonitorBox/src/ASF/thirdparty/freertos/freertos-7.3.0/source/include/FF_include/ff_file.h

Added : /SingleChannelMonitorBox/src/ASF/thirdparty/freertos/freertos-7.3.0/source/include/FF_include/ff_format.h

Added : /SingleChannelMonitorBox/src/ASF/thirdparty/freertos/freertos-7.3.0/source/include/FF_include/ff_headers.h

Added : /SingleChannelMonitorBox/src/ASF/thirdparty/freertos/freertos-7.3.0/source/include/FF_include/ff_ioman.h

Added : /SingleChannelMonitorBox/src/ASF/thirdparty/freertos/freertos-7.3.0/source/include/FF_include/ff_locking.h

Added : /SingleChannelMonitorBox/src/ASF/thirdparty/freertos/freertos-7.3.0/source/include/FF_include/ff_memory.h

Added : /SingleChannelMonitorBox/src/ASF/thirdparty/freertos/freertos-7.3.0/source/include/FF_include/ff_old_config_defines.h

Added : /SingleChannelMonitorBox/src/ASF/thirdparty/freertos/freertos-7.3.0/source/include/FF_include/ff_stdio.h

Added : /SingleChannelMonitorBox/src/ASF/thirdparty/freertos/freertos-7.3.0/source/include/FF_include/ff_string.h

Added : /SingleChannelMonitorBox/src/ASF/thirdparty/freertos/freertos-7.3.0/source/include/FF_include/ff_sys.h

Added : /SingleChannelMonitorBox/src/ASF/thirdparty/freertos/freertos-7.3.0/source/include/FF_include/ff_time.h

Added : /SingleChannelMonitorBox/src/ASF/thirdparty/freertos/freertos-7.3.0/source/include/UDPLoggingPrintf.h

Added : /SingleChannelMonitorBox/src/CreateAndVerifyExampleFiles.c

Added : /SingleChannelMonitorBox/src/DefaultWebPages.h

Modified : /SingleChannelMonitorBox/src/DisplayDriver/HexModule.c

Modified : /SingleChannelMonitorBox/src/DisplayDriver/HexModule.h

Modified : /SingleChannelMonitorBox/src/ModbusServerTCP/Include/mbport.h

Modified : /SingleChannelMonitorBox/src/ModbusServerTCP/TCP/mbport.c

Modified : /SingleChannelMonitorBox/src/TC_Reader/TempReadingMain.c

Modified : /SingleChannelMonitorBox/src/TC_Reader/TempReadingMain.h

Modified : /SingleChannelMonitorBox/src/asf.h

Modified : /SingleChannelMonitorBox/src/config/FreeRTOSConfig.h

Modified : /SingleChannelMonitorBox/src/config/FreeRTOSIPConfig.h

Added : /SingleChannelMonitorBox/src/config/conf_access.h

Modified : /SingleChannelMonitorBox/src/config/conf_board.h

Modified : /SingleChannelMonitorBox/src/config/conf_eth.h

Added : /SingleChannelMonitorBox/src/config/conf_nf.h

Added : /SingleChannelMonitorBox/src/config/conf_sd_mmc.h

Modified : /SingleChannelMonitorBox/src/main.c

Revision: 11

Author: GiselleD

Date: Tuesday, October 25, 2022 7:38:33 PM

Message:

Added base for display driver. It currently only supports 1 seg module and it counts from 0 to 9 on that module.

Modified : /SingleChannelMonitorBox/Debug/Makefile

Modified : /SingleChannelMonitorBox/Debug/makedep.mk

Added : /SingleChannelMonitorBox/Debug/src/DisplayDriver

Modified : /SingleChannelMonitorBox/SingleChannelMonitorBox.cproj

Added : /SingleChannelMonitorBox/src/DisplayDriver

Added : /SingleChannelMonitorBox/src/DisplayDriver/HexModule.c

Added : /SingleChannelMonitorBox/src/DisplayDriver/HexModule.h

Modified : /SingleChannelMonitorBox/src/apptasks.c

Revision: 10

Author: GiselleD

Date: Monday, October 24, 2022 6:39:47 PM

Message:

Updated the temperature monitor to use only 1 register instead of 4. It's not fully validated since the appropriate hardware is not available, but it's probably good. I also did a major cleanup on the project, organizing things. I removed the UDP logging task files since the task requires too much RAM to run. I made a small change to the network interface to prevent it from rebooting the chip before its had a chance to try connecting. The modbus task was updated to handle a single register write instead of 4, so it is simpler now.

Modified : /SingleChannelMonitorBox/Debug/Makefile

Modified : /SingleChannelMonitorBox/Debug/makedep.mk

Modified : /SingleChannelMonitorBox/SingleChannelMonitorBox.cproj

Modified : /SingleChannelMonitorBox/src/ASF/sam/drivers/spi/spi_mutex.c

Deleted : /SingleChannelMonitorBox/src/ASF/thirdparty/freertos/freertos-7.3.0/source/UDPLoggingPrintf.c

Deleted : /SingleChannelMonitorBox/src/ASF/thirdparty/freertos/freertos-7.3.0/source/include/UDPLoggingPrintf.h

Modified : /SingleChannelMonitorBox/src/ASF/thirdparty/freertos/freertos-7.3.0/source/portable/NetworkInterface/NetworkInterface.c

Modified : /SingleChannelMonitorBox/src/ASF/thirdparty/freertos/freertos-7.3.0/source/portable/NetworkInterface/ksz8851snl.c

Modified : /SingleChannelMonitorBox/src/ModbusServerTCP/TCP/mbport.c

Modified : /SingleChannelMonitorBox/src/TC_Reader/TempReadingMain.c

Modified : /SingleChannelMonitorBox/src/apptasks.c

Modified : /SingleChannelMonitorBox/src/config/FreeRTOSConfig.h

Modified : /SingleChannelMonitorBox/src/main.c

Revision: 9

Author: GiselleD

Date: Tuesday, October 18, 2022 4:45:10 PM

Message:

Updated TempReadingMain.c to only show the whole number value of the temperature. Negative numbers are already in 2s complement so the only logic needed was grabbing the bits and extending the sign bit. Positive numbers only need to be grabbed since there is no sign bit.

Modified : /SingleChannelMonitorBox/src/TC_Reader/TempReadingMain.c

Revision: 8

Author: GiselleD

Date: Tuesday, October 18, 2022 2:07:25 PM

Message:

Added temperature reading code. It's not fully validated but it appears to be reading temperatures. Changes to the network interface were made to improve network connection and semaphore protect the SPI master.

Modified : /SingleChannelMonitorBox/Debug/Makefile

Modified : /SingleChannelMonitorBox/Debug/makedep.mk

Modified : /SingleChannelMonitorBox/SingleChannelMonitorBox.cproj

Deleted : /SingleChannelMonitorBox/src/ASF/common/services/freertos/sam/freertos_spi_master.c

Deleted : /SingleChannelMonitorBox/src/ASF/common/services/freertos/sam/freertos_spi_master.h

Added : /SingleChannelMonitorBox/src/ASF/sam/drivers/spi/spi_mutex.c

Added : /SingleChannelMonitorBox/src/ASF/sam/drivers/spi/spi_mutex.h

Modified : /SingleChannelMonitorBox/src/ASF/thirdparty/freertos/freertos-7.3.0/source/portable/NetworkInterface/NetworkInterface.c

Modified : /SingleChannelMonitorBox/src/ASF/thirdparty/freertos/freertos-7.3.0/source/portable/NetworkInterface/ksz8851snl.c

Modified : /SingleChannelMonitorBox/src/TC_Reader/TempReadingMain.c

Modified : /SingleChannelMonitorBox/src/TC_Reader/TempReadingMain.h

Modified : /SingleChannelMonitorBox/src/main.c

Revision: 7

Author: GiselleD

Date: Friday, October 14, 2022 11:42:12 AM

Message:

Fixed issues with network interface. Appears to work flawlessly now!

Modified : /SingleChannelMonitorBox/SingleChannelMonitorBox.cproj

Modified : /SingleChannelMonitorBox/src/ASF/thirdparty/freertos/freertos-7.3.0/source/portable/NetworkInterface/NetworkInterface.c

Modified : /SingleChannelMonitorBox/src/ASF/thirdparty/freertos/freertos-7.3.0/source/portable/NetworkInterface/ksz8851snl.c

Modified : /SingleChannelMonitorBox/src/config/conf_eth.h

Revision: 6

Author: GiselleD

Date: Thursday, October 13, 2022 3:36:58 PM

Message:

Made some changes to network interface to increase the reliability of the connection.

Modified : /SingleChannelMonitorBox/src/ASF/thirdparty/freertos/freertos-7.3.0/source/portable/NetworkInterface/NetworkInterface.c

Modified : /SingleChannelMonitorBox/src/ASF/thirdparty/freertos/freertos-7.3.0/source/portable/NetworkInterface/ksz8851snl.c

Modified : /SingleChannelMonitorBox/src/config/FreeRTOSIPConfig.h

Modified : /SingleChannelMonitorBox/src/config/conf_eth.h

Revision: 5

Author: GiselleD

Date: Tuesday, October 11, 2022 8:54:23 PM

Message:

Forgot to add a couple files. This should be it for the addition of modbus to the project.

Added : /SingleChannelMonitorBox/Debug/src/ASF/thirdparty/CMSIS/Include/utils

Added : /SingleChannelMonitorBox/Debug/src/ASF/thirdparty/CMSIS/Include/utils/interrupt

Added : /SingleChannelMonitorBox/src/config/mbconfig.h

Revision: 4

Author: GiselleD

Date: Tuesday, October 11, 2022 8:49:25 PM

Message:

More deleted files...

Deleted : /SingleChannelMonitorBox/src/ASF/sam/components

Deleted : /SingleChannelMonitorBox/src/Common-Source

Deleted : /SingleChannelMonitorBox/src/config/AbortDelay.h

Deleted : /SingleChannelMonitorBox/src/myEchoServer.c

Deleted : /SingleChannelMonitorBox/src/myEchoServer.h

Revision: 3

Author: GiselleD

Date: Tuesday, October 11, 2022 8:42:39 PM

Message:

These files need to be deleted.

Deleted : /SingleChannelMonitorBox/Debug/src/ASF/common/services/adp

Deleted : /SingleChannelMonitorBox/Debug/src/ASF/sam/components

Deleted : /SingleChannelMonitorBox/Debug/src/ASF/thirdparty/freertos/freertos-7.3.0/source/crypto

Deleted : /SingleChannelMonitorBox/src/ASF/thirdparty/freertos/freertos-7.3.0/source/include/ksz8851snl_reg.h

Deleted : /SingleChannelMonitorBox/src/ASF/thirdparty/freertos/freertos-7.3.0/source/include/phyHandling.h

Deleted : /SingleChannelMonitorBox/src/ASF/thirdparty/freertos/freertos-7.3.0/source/include/pkcs11t.h

Deleted : /SingleChannelMonitorBox/src/ASF/thirdparty/freertos/freertos-7.3.0/source/old

Deleted : /SingleChannelMonitorBox/src/AbortDelay.h

Deleted : /SingleChannelMonitorBox/src/adp_example.c

Deleted : /SingleChannelMonitorBox/src/adp_example_adc.h

Deleted : /SingleChannelMonitorBox/src/adp_example_tc.h

Deleted : /SingleChannelMonitorBox/src/adp_window.h

Revision: 2

Author: GiselleD

Date: Tuesday, October 11, 2022 8:28:48 PM

Message:

Added support for modbus application protocol. A simulated temperature reading is available for reading. The network interface was improved slightly.

Modified : /SingleChannelMonitorBox/Debug/Makefile

Modified : /SingleChannelMonitorBox/Debug/makedep.mk

Added : /SingleChannelMonitorBox/Debug/src/ModbusServer

Added : /SingleChannelMonitorBox/Debug/src/ModbusServerTCP

Added : /SingleChannelMonitorBox/Debug/src/ModbusServerTCP/Functions

Added : /SingleChannelMonitorBox/Debug/src/ModbusServerTCP/Include

Added : /SingleChannelMonitorBox/Debug/src/ModbusServerTCP/TCP

Added : /SingleChannelMonitorBox/Debug/src/TC_Reader

Modified : /SingleChannelMonitorBox/SingleChannelMonitorBox.cproj

Modified : /SingleChannelMonitorBox/src/ASF/thirdparty/freertos/freertos-7.3.0/source/portable/NetworkInterface/NetworkInterface.c

Added : /SingleChannelMonitorBox/src/ModbusServerTCP

Added : /SingleChannelMonitorBox/src/ModbusServerTCP/Functions

Added : /SingleChannelMonitorBox/src/ModbusServerTCP/Functions/mbfunccoils.c

Added : /SingleChannelMonitorBox/src/ModbusServerTCP/Functions/mbfuncdiag.c

Added : /SingleChannelMonitorBox/src/ModbusServerTCP/Functions/mbfuncdisc.c

Added : /SingleChannelMonitorBox/src/ModbusServerTCP/Functions/mbfuncholding.c

Added : /SingleChannelMonitorBox/src/ModbusServerTCP/Functions/mbfuncinput.c

Added : /SingleChannelMonitorBox/src/ModbusServerTCP/Functions/mbfuncother.c

Added : /SingleChannelMonitorBox/src/ModbusServerTCP/Functions/mbutils.c

Added : /SingleChannelMonitorBox/src/ModbusServerTCP/Include

Added : /SingleChannelMonitorBox/src/ModbusServerTCP/Include/mb.h

Added : /SingleChannelMonitorBox/src/ModbusServerTCP/Include/mbframe.h

Added : /SingleChannelMonitorBox/src/ModbusServerTCP/Include/mbfunc.h

Added : /SingleChannelMonitorBox/src/ModbusServerTCP/Include/mbport.h

Added : /SingleChannelMonitorBox/src/ModbusServerTCP/Include/mbproto.h

Added : /SingleChannelMonitorBox/src/ModbusServerTCP/Include/mbutils.h

Added : /SingleChannelMonitorBox/src/ModbusServerTCP/Include/port.h

Added : /SingleChannelMonitorBox/src/ModbusServerTCP/TCP

Added : /SingleChannelMonitorBox/src/ModbusServerTCP/TCP/mbport.c

Added : /SingleChannelMonitorBox/src/ModbusServerTCP/TCP/mbtcp.c

Added : /SingleChannelMonitorBox/src/ModbusServerTCP/TCP/mbtcp.h

Added : /SingleChannelMonitorBox/src/ModbusServerTCP/mb.c

Added : /SingleChannelMonitorBox/src/TC_Reader

Added : /SingleChannelMonitorBox/src/TC_Reader/TempReadingMain.c

Added : /SingleChannelMonitorBox/src/TC_Reader/TempReadingMain.h

Modified : /SingleChannelMonitorBox/src/asf.h

Modified : /SingleChannelMonitorBox/src/main.c

Revision: 1

Author: GiselleD

Date: Monday, September 26, 2022 4:44:08 PM

Message:

First commit! FreeRTOS is installed and the TCP IP stack is fully connected to the ksz8851snl chip through a fully ported NetworkInterface. An echo server is running to verify functionality. ICMP ping replies are working. Gratuitous ARP appears to work as well. UDP functionality has not been fully tested. Enabling the UDP printf task causes the device to run out of RAM so it cannot be used.

Added : /SingleChannelMonitorBox

Added : /SingleChannelMonitorBox/Debug

Added : /SingleChannelMonitorBox/Debug/Makefile

Added : /SingleChannelMonitorBox/Debug/makedep.mk

Added : /SingleChannelMonitorBox/Debug/src

Added : /SingleChannelMonitorBox/Debug/src/ASF

Added : /SingleChannelMonitorBox/Debug/src/ASF/common

Added : /SingleChannelMonitorBox/Debug/src/ASF/common/boards

Added : /SingleChannelMonitorBox/Debug/src/ASF/common/services

Added : /SingleChannelMonitorBox/Debug/src/ASF/common/services/adp

Added : /SingleChannelMonitorBox/Debug/src/ASF/common/services/adp/example

Added : /SingleChannelMonitorBox/Debug/src/ASF/common/services/adp/example/sam

Added : /SingleChannelMonitorBox/Debug/src/ASF/common/services/adp/example/xplained_pro_sam4s_spi

Added : /SingleChannelMonitorBox/Debug/src/ASF/common/services/adp/sam

Added : /SingleChannelMonitorBox/Debug/src/ASF/common/services/clock

Added : /SingleChannelMonitorBox/Debug/src/ASF/common/services/clock/sam4s

Added : /SingleChannelMonitorBox/Debug/src/ASF/common/services/delay

Added : /SingleChannelMonitorBox/Debug/src/ASF/common/services/delay/sam

Added : /SingleChannelMonitorBox/Debug/src/ASF/common/services/freertos

Added : /SingleChannelMonitorBox/Debug/src/ASF/common/services/freertos/sam

Added : /SingleChannelMonitorBox/Debug/src/ASF/common/services/gpio

Added : /SingleChannelMonitorBox/Debug/src/ASF/common/services/gpio/sam_gpio

Added : /SingleChannelMonitorBox/Debug/src/ASF/common/services/ioport

Added : /SingleChannelMonitorBox/Debug/src/ASF/common/services/ioport/sam

Added : /SingleChannelMonitorBox/Debug/src/ASF/common/services/spi

Added : /SingleChannelMonitorBox/Debug/src/ASF/common/services/spi/sam_spi

Added : /SingleChannelMonitorBox/Debug/src/ASF/common/services/spi/sam_usart_spi

Added : /SingleChannelMonitorBox/Debug/src/ASF/common/utils

Added : /SingleChannelMonitorBox/Debug/src/ASF/common/utils/interrupt

Added : /SingleChannelMonitorBox/Debug/src/ASF/sam

Added : /SingleChannelMonitorBox/Debug/src/ASF/sam/boards

Added : /SingleChannelMonitorBox/Debug/src/ASF/sam/boards/sam4s_xplained_pro

Added : /SingleChannelMonitorBox/Debug/src/ASF/sam/components

Added : /SingleChannelMonitorBox/Debug/src/ASF/sam/components/ethernet_phy

Added : /SingleChannelMonitorBox/Debug/src/ASF/sam/components/ethernet_phy/ksz8851snl

Added : /SingleChannelMonitorBox/Debug/src/ASF/sam/drivers

Added : /SingleChannelMonitorBox/Debug/src/ASF/sam/drivers/adc

Added : /SingleChannelMonitorBox/Debug/src/ASF/sam/drivers/chipid

Added : /SingleChannelMonitorBox/Debug/src/ASF/sam/drivers/pdc

Added : /SingleChannelMonitorBox/Debug/src/ASF/sam/drivers/pdc/pdc_uart_example

Added : /SingleChannelMonitorBox/Debug/src/ASF/sam/drivers/pio

Added : /SingleChannelMonitorBox/Debug/src/ASF/sam/drivers/pmc

Added : /SingleChannelMonitorBox/Debug/src/ASF/sam/drivers/spi

Added : /SingleChannelMonitorBox/Debug/src/ASF/sam/drivers/tc

Added : /SingleChannelMonitorBox/Debug/src/ASF/sam/drivers/usart

Added : /SingleChannelMonitorBox/Debug/src/ASF/sam/drivers/wdt

Added : /SingleChannelMonitorBox/Debug/src/ASF/sam/utils

Added : /SingleChannelMonitorBox/Debug/src/ASF/sam/utils/cmsis

Added : /SingleChannelMonitorBox/Debug/src/ASF/sam/utils/cmsis/sam4s

Added : /SingleChannelMonitorBox/Debug/src/ASF/sam/utils/cmsis/sam4s/include

Added : /SingleChannelMonitorBox/Debug/src/ASF/sam/utils/cmsis/sam4s/include/component

Added : /SingleChannelMonitorBox/Debug/src/ASF/sam/utils/cmsis/sam4s/include/instance

Added : /SingleChannelMonitorBox/Debug/src/ASF/sam/utils/cmsis/sam4s/include/pio

Added : /SingleChannelMonitorBox/Debug/src/ASF/sam/utils/cmsis/sam4s/source

Added : /SingleChannelMonitorBox/Debug/src/ASF/sam/utils/cmsis/sam4s/source/templates

Added : /SingleChannelMonitorBox/Debug/src/ASF/sam/utils/cmsis/sam4s/source/templates/gcc

Added : /SingleChannelMonitorBox/Debug/src/ASF/sam/utils/header_files

Added : /SingleChannelMonitorBox/Debug/src/ASF/sam/utils/linker_scripts

Added : /SingleChannelMonitorBox/Debug/src/ASF/sam/utils/linker_scripts/sam4s

Added : /SingleChannelMonitorBox/Debug/src/ASF/sam/utils/linker_scripts/sam4s/sam4sd32

Added : /SingleChannelMonitorBox/Debug/src/ASF/sam/utils/linker_scripts/sam4s/sam4sd32/gcc

Added : /SingleChannelMonitorBox/Debug/src/ASF/sam/utils/make

Added : /SingleChannelMonitorBox/Debug/src/ASF/sam/utils/preprocessor

Added : /SingleChannelMonitorBox/Debug/src/ASF/sam/utils/syscalls

Added : /SingleChannelMonitorBox/Debug/src/ASF/sam/utils/syscalls/gcc

Added : /SingleChannelMonitorBox/Debug/src/ASF/thirdparty

Added : /SingleChannelMonitorBox/Debug/src/ASF/thirdparty/CMSIS

Added : /SingleChannelMonitorBox/Debug/src/ASF/thirdparty/CMSIS/Include

Added : /SingleChannelMonitorBox/Debug/src/ASF/thirdparty/CMSIS/Lib

Added : /SingleChannelMonitorBox/Debug/src/ASF/thirdparty/CMSIS/Lib/GCC

Added : /SingleChannelMonitorBox/Debug/src/ASF/thirdparty/freertos

Added : /SingleChannelMonitorBox/Debug/src/ASF/thirdparty/freertos/freertos-7.3.0

Added : /SingleChannelMonitorBox/Debug/src/ASF/thirdparty/freertos/freertos-7.3.0/source

Added : /SingleChannelMonitorBox/Debug/src/ASF/thirdparty/freertos/freertos-7.3.0/source/Tools

Added : /SingleChannelMonitorBox/Debug/src/ASF/thirdparty/freertos/freertos-7.3.0/source/Tools/tcp_utilities

Added : /SingleChannelMonitorBox/Debug/src/ASF/thirdparty/freertos/freertos-7.3.0/source/crypto

Added : /SingleChannelMonitorBox/Debug/src/ASF/thirdparty/freertos/freertos-7.3.0/source/crypto/include

Added : /SingleChannelMonitorBox/Debug/src/ASF/thirdparty/freertos/freertos-7.3.0/source/crypto/src

Added : /SingleChannelMonitorBox/Debug/src/ASF/thirdparty/freertos/freertos-7.3.0/source/include

Added : /SingleChannelMonitorBox/Debug/src/ASF/thirdparty/freertos/freertos-7.3.0/source/portable

Added : /SingleChannelMonitorBox/Debug/src/ASF/thirdparty/freertos/freertos-7.3.0/source/portable/BufferManagement

Added : /SingleChannelMonitorBox/Debug/src/ASF/thirdparty/freertos/freertos-7.3.0/source/portable/NetworkInterface

Added : /SingleChannelMonitorBox/Debug/src/ASF/thirdparty/freertos/freertos-7.3.0/source/portable/gcc

Added : /SingleChannelMonitorBox/Debug/src/ASF/thirdparty/freertos/freertos-7.3.0/source/portable/gcc/sam

Added : /SingleChannelMonitorBox/Debug/src/ASF/thirdparty/freertos/freertos-7.3.0/source/portable/memmang

Added : /SingleChannelMonitorBox/Debug/src/Common

Added : /SingleChannelMonitorBox/Debug/src/Common/include

Added : /SingleChannelMonitorBox/Debug/src/Common-Source

Added : /SingleChannelMonitorBox/Debug/src/Common-Source/include

Added : /SingleChannelMonitorBox/Debug/src/config

Added : /SingleChannelMonitorBox/SingleChannelMonitorBox.componentinfo.xml

Added : /SingleChannelMonitorBox/SingleChannelMonitorBox.cproj

Added : /SingleChannelMonitorBox/src

Added : /SingleChannelMonitorBox/src/ASF

Added : /SingleChannelMonitorBox/src/ASF/common

Added : /SingleChannelMonitorBox/src/ASF/common/boards

Added : /SingleChannelMonitorBox/src/ASF/common/boards/board.h

Added : /SingleChannelMonitorBox/src/ASF/common/services

Added : /SingleChannelMonitorBox/src/ASF/common/services/adp

Added : /SingleChannelMonitorBox/src/ASF/common/services/adp/example

Added : /SingleChannelMonitorBox/src/ASF/common/services/adp/example/sam

Added : /SingleChannelMonitorBox/src/ASF/common/services/adp/example/sam/adp_example_adc.c

Added : /SingleChannelMonitorBox/src/ASF/common/services/adp/example/sam/adp_example_tc.c

Added : /SingleChannelMonitorBox/src/ASF/common/services/adp/example/xplained_pro_sam4s_spi

Added : /SingleChannelMonitorBox/src/ASF/common/services/adp/example/xplained_pro_sam4s_spi/conf_tc.h

Added : /SingleChannelMonitorBox/src/ASF/common/services/clock

Added : /SingleChannelMonitorBox/src/ASF/common/services/clock/genclk.h

Added : /SingleChannelMonitorBox/src/ASF/common/services/clock/osc.h

Added : /SingleChannelMonitorBox/src/ASF/common/services/clock/pll.h

Added : /SingleChannelMonitorBox/src/ASF/common/services/clock/sam4s

Added : /SingleChannelMonitorBox/src/ASF/common/services/clock/sam4s/genclk.h

Added : /SingleChannelMonitorBox/src/ASF/common/services/clock/sam4s/osc.h

Added : /SingleChannelMonitorBox/src/ASF/common/services/clock/sam4s/pll.h

Added : /SingleChannelMonitorBox/src/ASF/common/services/clock/sam4s/sysclk.c

Added : /SingleChannelMonitorBox/src/ASF/common/services/clock/sam4s/sysclk.h

Added : /SingleChannelMonitorBox/src/ASF/common/services/clock/sysclk.h

Added : /SingleChannelMonitorBox/src/ASF/common/services/delay

Added : /SingleChannelMonitorBox/src/ASF/common/services/delay/delay.h

Added : /SingleChannelMonitorBox/src/ASF/common/services/delay/sam

Added : /SingleChannelMonitorBox/src/ASF/common/services/delay/sam/cycle_counter.c

Added : /SingleChannelMonitorBox/src/ASF/common/services/delay/sam/cycle_counter.h

Added : /SingleChannelMonitorBox/src/ASF/common/services/freertos

Added : /SingleChannelMonitorBox/src/ASF/common/services/freertos/sam

Added : /SingleChannelMonitorBox/src/ASF/common/services/freertos/sam/freertos_peripheral_control.c

Added : /SingleChannelMonitorBox/src/ASF/common/services/freertos/sam/freertos_peripheral_control.h

Added : /SingleChannelMonitorBox/src/ASF/common/services/freertos/sam/freertos_peripheral_control_private.h

Added : /SingleChannelMonitorBox/src/ASF/common/services/freertos/sam/freertos_spi_master.c

Added : /SingleChannelMonitorBox/src/ASF/common/services/freertos/sam/freertos_spi_master.h

Added : /SingleChannelMonitorBox/src/ASF/common/services/gpio

Added : /SingleChannelMonitorBox/src/ASF/common/services/gpio/gpio.h

Added : /SingleChannelMonitorBox/src/ASF/common/services/gpio/sam_gpio

Added : /SingleChannelMonitorBox/src/ASF/common/services/gpio/sam_gpio/sam_gpio.h

Added : /SingleChannelMonitorBox/src/ASF/common/services/ioport

Added : /SingleChannelMonitorBox/src/ASF/common/services/ioport/ioport.h

Added : /SingleChannelMonitorBox/src/ASF/common/services/ioport/sam

Added : /SingleChannelMonitorBox/src/ASF/common/services/ioport/sam/ioport_pio.h

Added : /SingleChannelMonitorBox/src/ASF/common/services/spi

Added : /SingleChannelMonitorBox/src/ASF/common/services/spi/sam_spi

Added : /SingleChannelMonitorBox/src/ASF/common/services/spi/sam_spi/spi_master.c

Added : /SingleChannelMonitorBox/src/ASF/common/services/spi/sam_spi/spi_master.h

Added : /SingleChannelMonitorBox/src/ASF/common/services/spi/spi_master.h

Added : /SingleChannelMonitorBox/src/ASF/common/utils

Added : /SingleChannelMonitorBox/src/ASF/common/utils/interrupt

Added : /SingleChannelMonitorBox/src/ASF/common/utils/interrupt/interrupt_sam_nvic.c

Added : /SingleChannelMonitorBox/src/ASF/common/utils/interrupt/interrupt_sam_nvic.h

Added : /SingleChannelMonitorBox/src/ASF/common/utils/interrupt.h

Added : /SingleChannelMonitorBox/src/ASF/common/utils/parts.h

Added : /SingleChannelMonitorBox/src/ASF/sam

Added : /SingleChannelMonitorBox/src/ASF/sam/boards

Added : /SingleChannelMonitorBox/src/ASF/sam/boards/sam4s_xplained_pro

Added : /SingleChannelMonitorBox/src/ASF/sam/boards/sam4s_xplained_pro/init.c

Added : /SingleChannelMonitorBox/src/ASF/sam/boards/sam4s_xplained_pro/led.h

Added : /SingleChannelMonitorBox/src/ASF/sam/boards/sam4s_xplained_pro/sam4s_xplained_pro.h

Added : /SingleChannelMonitorBox/src/ASF/sam/components

Added : /SingleChannelMonitorBox/src/ASF/sam/components/ethernet_phy

Added : /SingleChannelMonitorBox/src/ASF/sam/components/ethernet_phy/ksz8851snl

Added : /SingleChannelMonitorBox/src/ASF/sam/drivers

Added : /SingleChannelMonitorBox/src/ASF/sam/drivers/adc

Added : /SingleChannelMonitorBox/src/ASF/sam/drivers/adc/adc.c

Added : /SingleChannelMonitorBox/src/ASF/sam/drivers/adc/adc.h

Added : /SingleChannelMonitorBox/src/ASF/sam/drivers/adc/adc_sam3u.c

Added : /SingleChannelMonitorBox/src/ASF/sam/drivers/chipid

Added : /SingleChannelMonitorBox/src/ASF/sam/drivers/chipid/chipid.c

Added : /SingleChannelMonitorBox/src/ASF/sam/drivers/chipid/chipid.h

Added : /SingleChannelMonitorBox/src/ASF/sam/drivers/pdc

Added : /SingleChannelMonitorBox/src/ASF/sam/drivers/pdc/pdc.c

Added : /SingleChannelMonitorBox/src/ASF/sam/drivers/pdc/pdc.h

Added : /SingleChannelMonitorBox/src/ASF/sam/drivers/pdc/pdc_uart_example

Added : /SingleChannelMonitorBox/src/ASF/sam/drivers/pdc/pdc_uart_example/pdc_uart_example.h

Added : /SingleChannelMonitorBox/src/ASF/sam/drivers/pio

Added : /SingleChannelMonitorBox/src/ASF/sam/drivers/pio/pio.c

Added : /SingleChannelMonitorBox/src/ASF/sam/drivers/pio/pio.h

Added : /SingleChannelMonitorBox/src/ASF/sam/drivers/pio/pio_handler.c

Added : /SingleChannelMonitorBox/src/ASF/sam/drivers/pio/pio_handler.h

Added : /SingleChannelMonitorBox/src/ASF/sam/drivers/pmc

Added : /SingleChannelMonitorBox/src/ASF/sam/drivers/pmc/pmc.c

Added : /SingleChannelMonitorBox/src/ASF/sam/drivers/pmc/pmc.h

Added : /SingleChannelMonitorBox/src/ASF/sam/drivers/pmc/sleep.c

Added : /SingleChannelMonitorBox/src/ASF/sam/drivers/pmc/sleep.h

Added : /SingleChannelMonitorBox/src/ASF/sam/drivers/spi

Added : /SingleChannelMonitorBox/src/ASF/sam/drivers/spi/spi.c

Added : /SingleChannelMonitorBox/src/ASF/sam/drivers/spi/spi.h

Added : /SingleChannelMonitorBox/src/ASF/sam/drivers/tc

Added : /SingleChannelMonitorBox/src/ASF/sam/drivers/tc/tc.c

Added : /SingleChannelMonitorBox/src/ASF/sam/drivers/tc/tc.h

Added : /SingleChannelMonitorBox/src/ASF/sam/drivers/wdt

Added : /SingleChannelMonitorBox/src/ASF/sam/drivers/wdt/wdt.c

Added : /SingleChannelMonitorBox/src/ASF/sam/drivers/wdt/wdt.h

Added : /SingleChannelMonitorBox/src/ASF/sam/utils

Added : /SingleChannelMonitorBox/src/ASF/sam/utils/cmsis

Added : /SingleChannelMonitorBox/src/ASF/sam/utils/cmsis/sam4s

Added : /SingleChannelMonitorBox/src/ASF/sam/utils/cmsis/sam4s/include

Added : /SingleChannelMonitorBox/src/ASF/sam/utils/cmsis/sam4s/include/component

Added : /SingleChannelMonitorBox/src/ASF/sam/utils/cmsis/sam4s/include/component/component_acc.h

Added : /SingleChannelMonitorBox/src/ASF/sam/utils/cmsis/sam4s/include/component/component_adc.h

Added : /SingleChannelMonitorBox/src/ASF/sam/utils/cmsis/sam4s/include/component/component_chipid.h

Added : /SingleChannelMonitorBox/src/ASF/sam/utils/cmsis/sam4s/include/component/component_cmcc.h

Added : /SingleChannelMonitorBox/src/ASF/sam/utils/cmsis/sam4s/include/component/component_crccu.h

Added : /SingleChannelMonitorBox/src/ASF/sam/utils/cmsis/sam4s/include/component/component_dacc.h

Added : /SingleChannelMonitorBox/src/ASF/sam/utils/cmsis/sam4s/include/component/component_efc.h

Added : /SingleChannelMonitorBox/src/ASF/sam/utils/cmsis/sam4s/include/component/component_gpbr.h

Added : /SingleChannelMonitorBox/src/ASF/sam/utils/cmsis/sam4s/include/component/component_hsmci.h

Added : /SingleChannelMonitorBox/src/ASF/sam/utils/cmsis/sam4s/include/component/component_matrix.h

Added : /SingleChannelMonitorBox/src/ASF/sam/utils/cmsis/sam4s/include/component/component_pdc.h

Added : /SingleChannelMonitorBox/src/ASF/sam/utils/cmsis/sam4s/include/component/component_pio.h

Added : /SingleChannelMonitorBox/src/ASF/sam/utils/cmsis/sam4s/include/component/component_pmc.h

Added : /SingleChannelMonitorBox/src/ASF/sam/utils/cmsis/sam4s/include/component/component_pwm.h

Added : /SingleChannelMonitorBox/src/ASF/sam/utils/cmsis/sam4s/include/component/component_rstc.h

Added : /SingleChannelMonitorBox/src/ASF/sam/utils/cmsis/sam4s/include/component/component_rtc.h

Added : /SingleChannelMonitorBox/src/ASF/sam/utils/cmsis/sam4s/include/component/component_rtt.h

Added : /SingleChannelMonitorBox/src/ASF/sam/utils/cmsis/sam4s/include/component/component_smc.h

Added : /SingleChannelMonitorBox/src/ASF/sam/utils/cmsis/sam4s/include/component/component_spi.h

Added : /SingleChannelMonitorBox/src/ASF/sam/utils/cmsis/sam4s/include/component/component_ssc.h

Added : /SingleChannelMonitorBox/src/ASF/sam/utils/cmsis/sam4s/include/component/component_supc.h

Added : /SingleChannelMonitorBox/src/ASF/sam/utils/cmsis/sam4s/include/component/component_tc.h

Added : /SingleChannelMonitorBox/src/ASF/sam/utils/cmsis/sam4s/include/component/component_twi.h

Added : /SingleChannelMonitorBox/src/ASF/sam/utils/cmsis/sam4s/include/component/component_uart.h

Added : /SingleChannelMonitorBox/src/ASF/sam/utils/cmsis/sam4s/include/component/component_udp.h

Added : /SingleChannelMonitorBox/src/ASF/sam/utils/cmsis/sam4s/include/component/component_usart.h

Added : /SingleChannelMonitorBox/src/ASF/sam/utils/cmsis/sam4s/include/component/component_wdt.h

Added : /SingleChannelMonitorBox/src/ASF/sam/utils/cmsis/sam4s/include/instance

Added : /SingleChannelMonitorBox/src/ASF/sam/utils/cmsis/sam4s/include/instance/instance_acc.h

Added : /SingleChannelMonitorBox/src/ASF/sam/utils/cmsis/sam4s/include/instance/instance_adc.h

Added : /SingleChannelMonitorBox/src/ASF/sam/utils/cmsis/sam4s/include/instance/instance_chipid.h

Added : /SingleChannelMonitorBox/src/ASF/sam/utils/cmsis/sam4s/include/instance/instance_cmcc.h

Added : /SingleChannelMonitorBox/src/ASF/sam/utils/cmsis/sam4s/include/instance/instance_crccu.h

Added : /SingleChannelMonitorBox/src/ASF/sam/utils/cmsis/sam4s/include/instance/instance_dacc.h

Added : /SingleChannelMonitorBox/src/ASF/sam/utils/cmsis/sam4s/include/instance/instance_efc0.h

Added : /SingleChannelMonitorBox/src/ASF/sam/utils/cmsis/sam4s/include/instance/instance_efc1.h

Added : /SingleChannelMonitorBox/src/ASF/sam/utils/cmsis/sam4s/include/instance/instance_gpbr.h

Added : /SingleChannelMonitorBox/src/ASF/sam/utils/cmsis/sam4s/include/instance/instance_hsmci.h

Added : /SingleChannelMonitorBox/src/ASF/sam/utils/cmsis/sam4s/include/instance/instance_matrix.h

Added : /SingleChannelMonitorBox/src/ASF/sam/utils/cmsis/sam4s/include/instance/instance_pioa.h

Added : /SingleChannelMonitorBox/src/ASF/sam/utils/cmsis/sam4s/include/instance/instance_piob.h

Added : /SingleChannelMonitorBox/src/ASF/sam/utils/cmsis/sam4s/include/instance/instance_pioc.h

Added : /SingleChannelMonitorBox/src/ASF/sam/utils/cmsis/sam4s/include/instance/instance_pmc.h

Added : /SingleChannelMonitorBox/src/ASF/sam/utils/cmsis/sam4s/include/instance/instance_pwm.h

Added : /SingleChannelMonitorBox/src/ASF/sam/utils/cmsis/sam4s/include/instance/instance_rstc.h

Added : /SingleChannelMonitorBox/src/ASF/sam/utils/cmsis/sam4s/include/instance/instance_rtc.h

Added : /SingleChannelMonitorBox/src/ASF/sam/utils/cmsis/sam4s/include/instance/instance_rtt.h

Added : /SingleChannelMonitorBox/src/ASF/sam/utils/cmsis/sam4s/include/instance/instance_smc.h

Added : /SingleChannelMonitorBox/src/ASF/sam/utils/cmsis/sam4s/include/instance/instance_spi.h

Added : /SingleChannelMonitorBox/src/ASF/sam/utils/cmsis/sam4s/include/instance/instance_ssc.h

Added : /SingleChannelMonitorBox/src/ASF/sam/utils/cmsis/sam4s/include/instance/instance_supc.h

Added : /SingleChannelMonitorBox/src/ASF/sam/utils/cmsis/sam4s/include/instance/instance_tc0.h

Added : /SingleChannelMonitorBox/src/ASF/sam/utils/cmsis/sam4s/include/instance/instance_tc1.h

Added : /SingleChannelMonitorBox/src/ASF/sam/utils/cmsis/sam4s/include/instance/instance_twi0.h

Added : /SingleChannelMonitorBox/src/ASF/sam/utils/cmsis/sam4s/include/instance/instance_twi1.h

Added : /SingleChannelMonitorBox/src/ASF/sam/utils/cmsis/sam4s/include/instance/instance_uart0.h

Added : /SingleChannelMonitorBox/src/ASF/sam/utils/cmsis/sam4s/include/instance/instance_uart1.h

Added : /SingleChannelMonitorBox/src/ASF/sam/utils/cmsis/sam4s/include/instance/instance_udp.h

Added : /SingleChannelMonitorBox/src/ASF/sam/utils/cmsis/sam4s/include/instance/instance_usart0.h

Added : /SingleChannelMonitorBox/src/ASF/sam/utils/cmsis/sam4s/include/instance/instance_usart1.h

Added : /SingleChannelMonitorBox/src/ASF/sam/utils/cmsis/sam4s/include/instance/instance_wdt.h

Added : /SingleChannelMonitorBox/src/ASF/sam/utils/cmsis/sam4s/include/pio

Added : /SingleChannelMonitorBox/src/ASF/sam/utils/cmsis/sam4s/include/pio/pio_sam4s16b.h

Added : /SingleChannelMonitorBox/src/ASF/sam/utils/cmsis/sam4s/include/pio/pio_sam4s16c.h

Added : /SingleChannelMonitorBox/src/ASF/sam/utils/cmsis/sam4s/include/pio/pio_sam4s2a.h

Added : /SingleChannelMonitorBox/src/ASF/sam/utils/cmsis/sam4s/include/pio/pio_sam4s2b.h

Added : /SingleChannelMonitorBox/src/ASF/sam/utils/cmsis/sam4s/include/pio/pio_sam4s2c.h

Added : /SingleChannelMonitorBox/src/ASF/sam/utils/cmsis/sam4s/include/pio/pio_sam4s4a.h

Added : /SingleChannelMonitorBox/src/ASF/sam/utils/cmsis/sam4s/include/pio/pio_sam4s4b.h

Added : /SingleChannelMonitorBox/src/ASF/sam/utils/cmsis/sam4s/include/pio/pio_sam4s4c.h

Added : /SingleChannelMonitorBox/src/ASF/sam/utils/cmsis/sam4s/include/pio/pio_sam4s8b.h

Added : /SingleChannelMonitorBox/src/ASF/sam/utils/cmsis/sam4s/include/pio/pio_sam4s8c.h

Added : /SingleChannelMonitorBox/src/ASF/sam/utils/cmsis/sam4s/include/pio/pio_sam4sa16b.h

Added : /SingleChannelMonitorBox/src/ASF/sam/utils/cmsis/sam4s/include/pio/pio_sam4sa16c.h

Added : /SingleChannelMonitorBox/src/ASF/sam/utils/cmsis/sam4s/include/pio/pio_sam4sd16b.h

Added : /SingleChannelMonitorBox/src/ASF/sam/utils/cmsis/sam4s/include/pio/pio_sam4sd16c.h

Added : /SingleChannelMonitorBox/src/ASF/sam/utils/cmsis/sam4s/include/pio/pio_sam4sd32b.h

Added : /SingleChannelMonitorBox/src/ASF/sam/utils/cmsis/sam4s/include/pio/pio_sam4sd32c.h

Added : /SingleChannelMonitorBox/src/ASF/sam/utils/cmsis/sam4s/include/sam4s.h

Added : /SingleChannelMonitorBox/src/ASF/sam/utils/cmsis/sam4s/include/sam4s16b.h

Added : /SingleChannelMonitorBox/src/ASF/sam/utils/cmsis/sam4s/include/sam4s16c.h

Added : /SingleChannelMonitorBox/src/ASF/sam/utils/cmsis/sam4s/include/sam4s2a.h

Added : /SingleChannelMonitorBox/src/ASF/sam/utils/cmsis/sam4s/include/sam4s2b.h

Added : /SingleChannelMonitorBox/src/ASF/sam/utils/cmsis/sam4s/include/sam4s2c.h

Added : /SingleChannelMonitorBox/src/ASF/sam/utils/cmsis/sam4s/include/sam4s4a.h

Added : /SingleChannelMonitorBox/src/ASF/sam/utils/cmsis/sam4s/include/sam4s4b.h

Added : /SingleChannelMonitorBox/src/ASF/sam/utils/cmsis/sam4s/include/sam4s4c.h

Added : /SingleChannelMonitorBox/src/ASF/sam/utils/cmsis/sam4s/include/sam4s8b.h

Added : /SingleChannelMonitorBox/src/ASF/sam/utils/cmsis/sam4s/include/sam4s8c.h

Added : /SingleChannelMonitorBox/src/ASF/sam/utils/cmsis/sam4s/include/sam4sa16b.h

Added : /SingleChannelMonitorBox/src/ASF/sam/utils/cmsis/sam4s/include/sam4sa16c.h

Added : /SingleChannelMonitorBox/src/ASF/sam/utils/cmsis/sam4s/include/sam4sd16b.h

Added : /SingleChannelMonitorBox/src/ASF/sam/utils/cmsis/sam4s/include/sam4sd16c.h

Added : /SingleChannelMonitorBox/src/ASF/sam/utils/cmsis/sam4s/include/sam4sd32b.h

Added : /SingleChannelMonitorBox/src/ASF/sam/utils/cmsis/sam4s/include/sam4sd32c.h

Added : /SingleChannelMonitorBox/src/ASF/sam/utils/cmsis/sam4s/include/system_sam4s.h

Added : /SingleChannelMonitorBox/src/ASF/sam/utils/cmsis/sam4s/source

Added : /SingleChannelMonitorBox/src/ASF/sam/utils/cmsis/sam4s/source/templates

Added : /SingleChannelMonitorBox/src/ASF/sam/utils/cmsis/sam4s/source/templates/gcc

Added : /SingleChannelMonitorBox/src/ASF/sam/utils/cmsis/sam4s/source/templates/gcc/startup_sam4s.c

Added : /SingleChannelMonitorBox/src/ASF/sam/utils/cmsis/sam4s/source/templates/system_sam4s.c

Added : /SingleChannelMonitorBox/src/ASF/sam/utils/compiler.h

Added : /SingleChannelMonitorBox/src/ASF/sam/utils/header_files

Added : /SingleChannelMonitorBox/src/ASF/sam/utils/header_files/io.h

Added : /SingleChannelMonitorBox/src/ASF/sam/utils/linker_scripts

Added : /SingleChannelMonitorBox/src/ASF/sam/utils/linker_scripts/sam4s

Added : /SingleChannelMonitorBox/src/ASF/sam/utils/linker_scripts/sam4s/sam4sd32

Added : /SingleChannelMonitorBox/src/ASF/sam/utils/linker_scripts/sam4s/sam4sd32/gcc

Added : /SingleChannelMonitorBox/src/ASF/sam/utils/linker_scripts/sam4s/sam4sd32/gcc/flash.ld

Added : /SingleChannelMonitorBox/src/ASF/sam/utils/make

Added : /SingleChannelMonitorBox/src/ASF/sam/utils/make/Makefile.sam.in

Added : /SingleChannelMonitorBox/src/ASF/sam/utils/preprocessor

Added : /SingleChannelMonitorBox/src/ASF/sam/utils/preprocessor/mrepeat.h

Added : /SingleChannelMonitorBox/src/ASF/sam/utils/preprocessor/preprocessor.h

Added : /SingleChannelMonitorBox/src/ASF/sam/utils/preprocessor/stringz.h

Added : /SingleChannelMonitorBox/src/ASF/sam/utils/preprocessor/tpaste.h

Added : /SingleChannelMonitorBox/src/ASF/sam/utils/status_codes.h

Added : /SingleChannelMonitorBox/src/ASF/sam/utils/syscalls

Added : /SingleChannelMonitorBox/src/ASF/sam/utils/syscalls/gcc

Added : /SingleChannelMonitorBox/src/ASF/sam/utils/syscalls/gcc/syscalls.c

Added : /SingleChannelMonitorBox/src/ASF/thirdparty

Added : /SingleChannelMonitorBox/src/ASF/thirdparty/CMSIS

Added : /SingleChannelMonitorBox/src/ASF/thirdparty/CMSIS/ATMEL-disclaimer.txt

Added : /SingleChannelMonitorBox/src/ASF/thirdparty/CMSIS/CMSIS_END_USER_LICENCE_AGREEMENT.pdf
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

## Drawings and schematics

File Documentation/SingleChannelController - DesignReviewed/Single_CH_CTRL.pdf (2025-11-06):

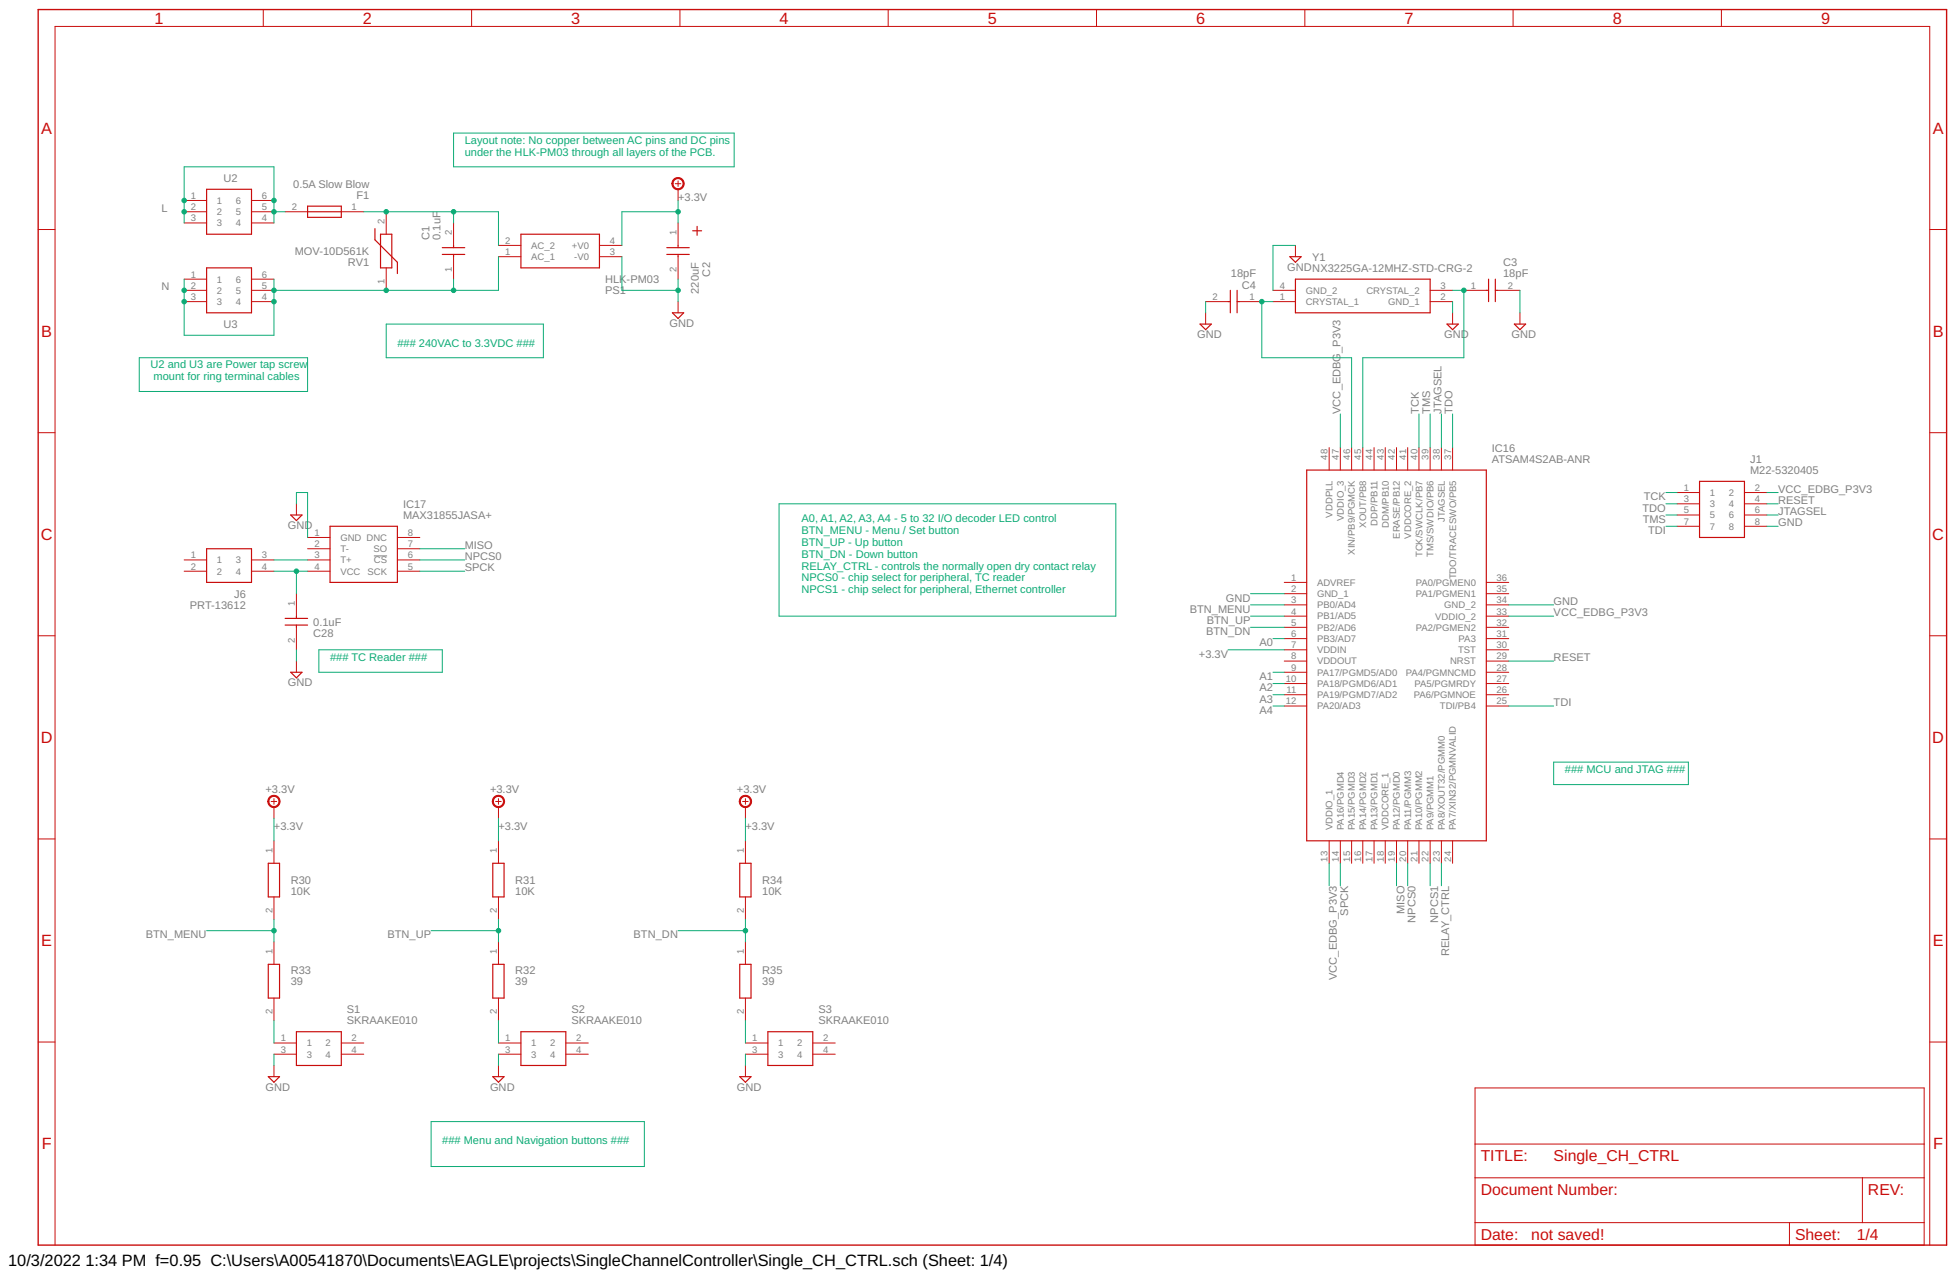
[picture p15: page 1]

Layout note: No copper between AC pins and DC pins under the HLK-PM03 through all layers of the PCB.

U2 and U3 are Power tap screw mount for ring terminal cables

A0, A1, A2, A3, A4 - 5 to 32 I/O decoder LED control
BTN_MENU - Menu / Set button BTN_UP - Up button BTN_DN - Down button RELAY_CTRL - controls the normally open dry contact relay

NPCS0 - chip select for peripheral, TC reader NPCS1 - chip select for peripheral, Ethernet controller

### Menu and Navigation buttons ###

Document Number: | REV:

Date: not saved! | Sheet: 1/4

10/3/2022 1:34 PM f=0.95 C:\Users\A00541870\Documents\EAGLE\projects\SingleChannelController\Single_CH_CTRL.sch (Sheet: 1/4)

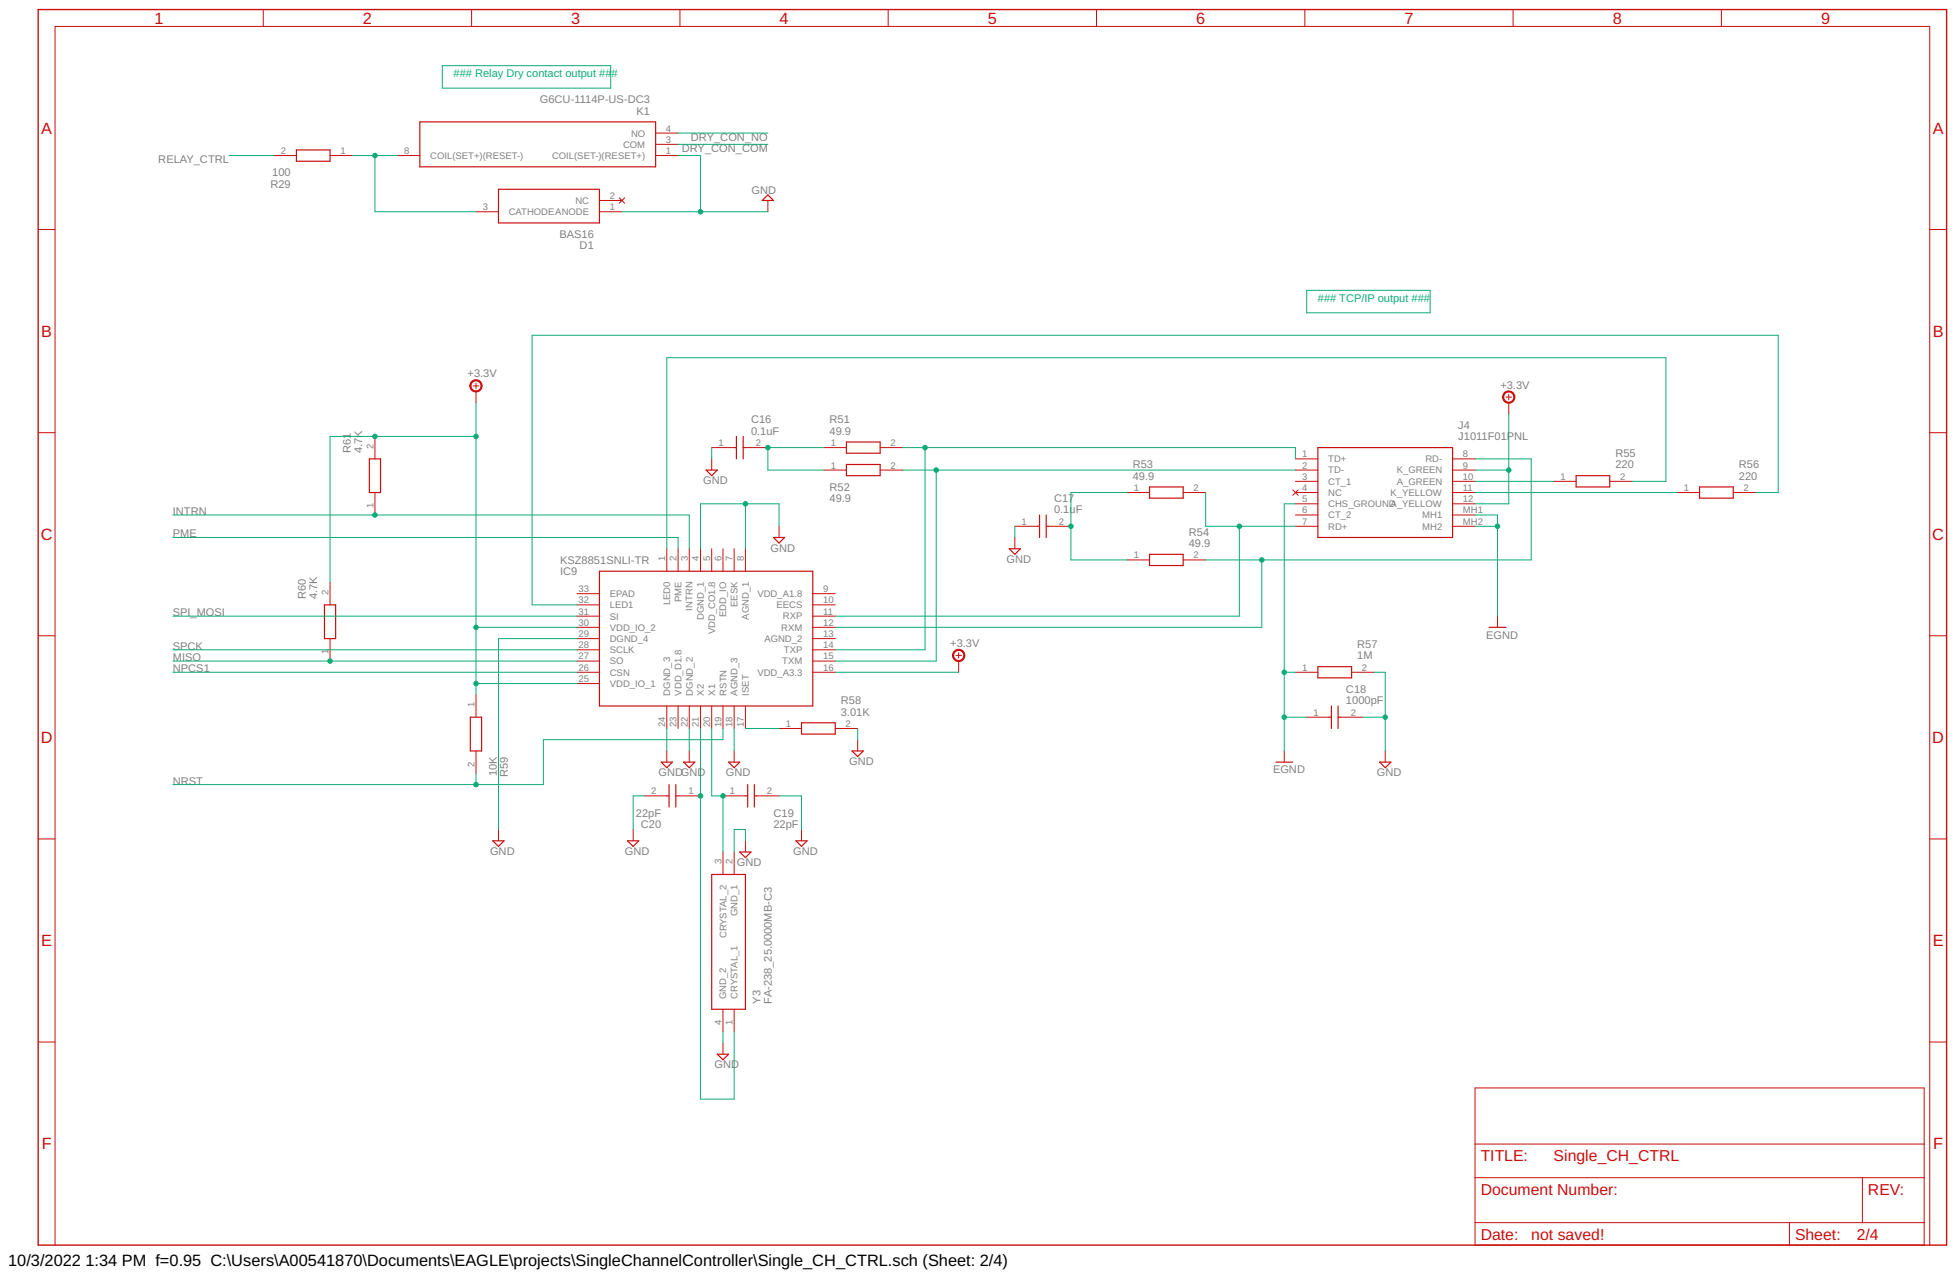
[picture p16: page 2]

### Relay Dry contact output ###

49.9 | 9 A_GREEN

10 K_YELLOW

10/3/2022 1:34 PM f=0.95 C:\Users\A00541870\Documents\EAGLE\projects\SingleChannelController\Single_CH_CTRL.sch (Sheet: 2/4)

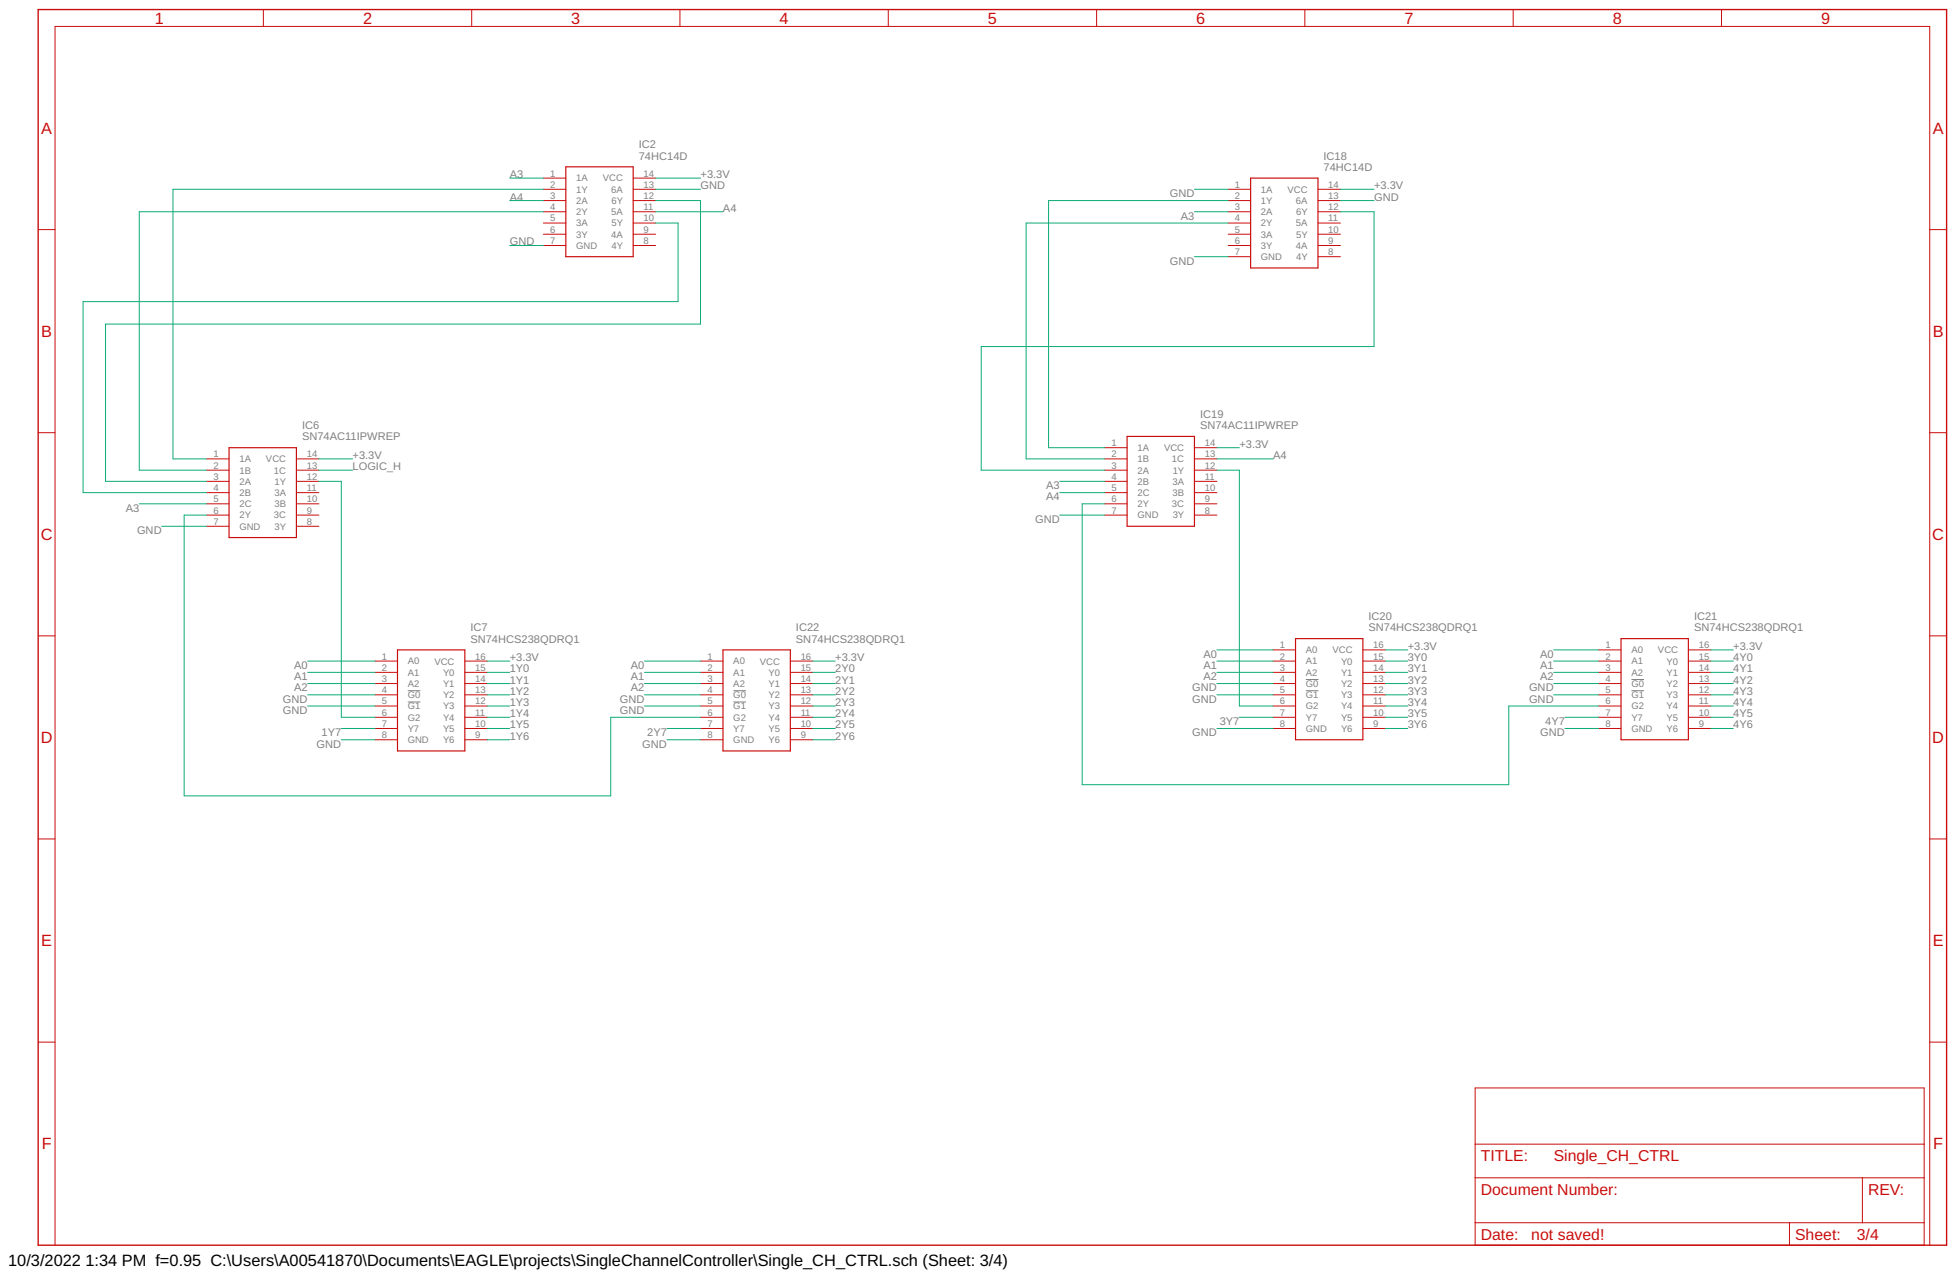
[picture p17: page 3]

10/3/2022 1:34 PM f=0.95 C:\Users\A00541870\Documents\EAGLE\projects\SingleChannelController\Single_CH_CTRL.sch (Sheet: 3/4)

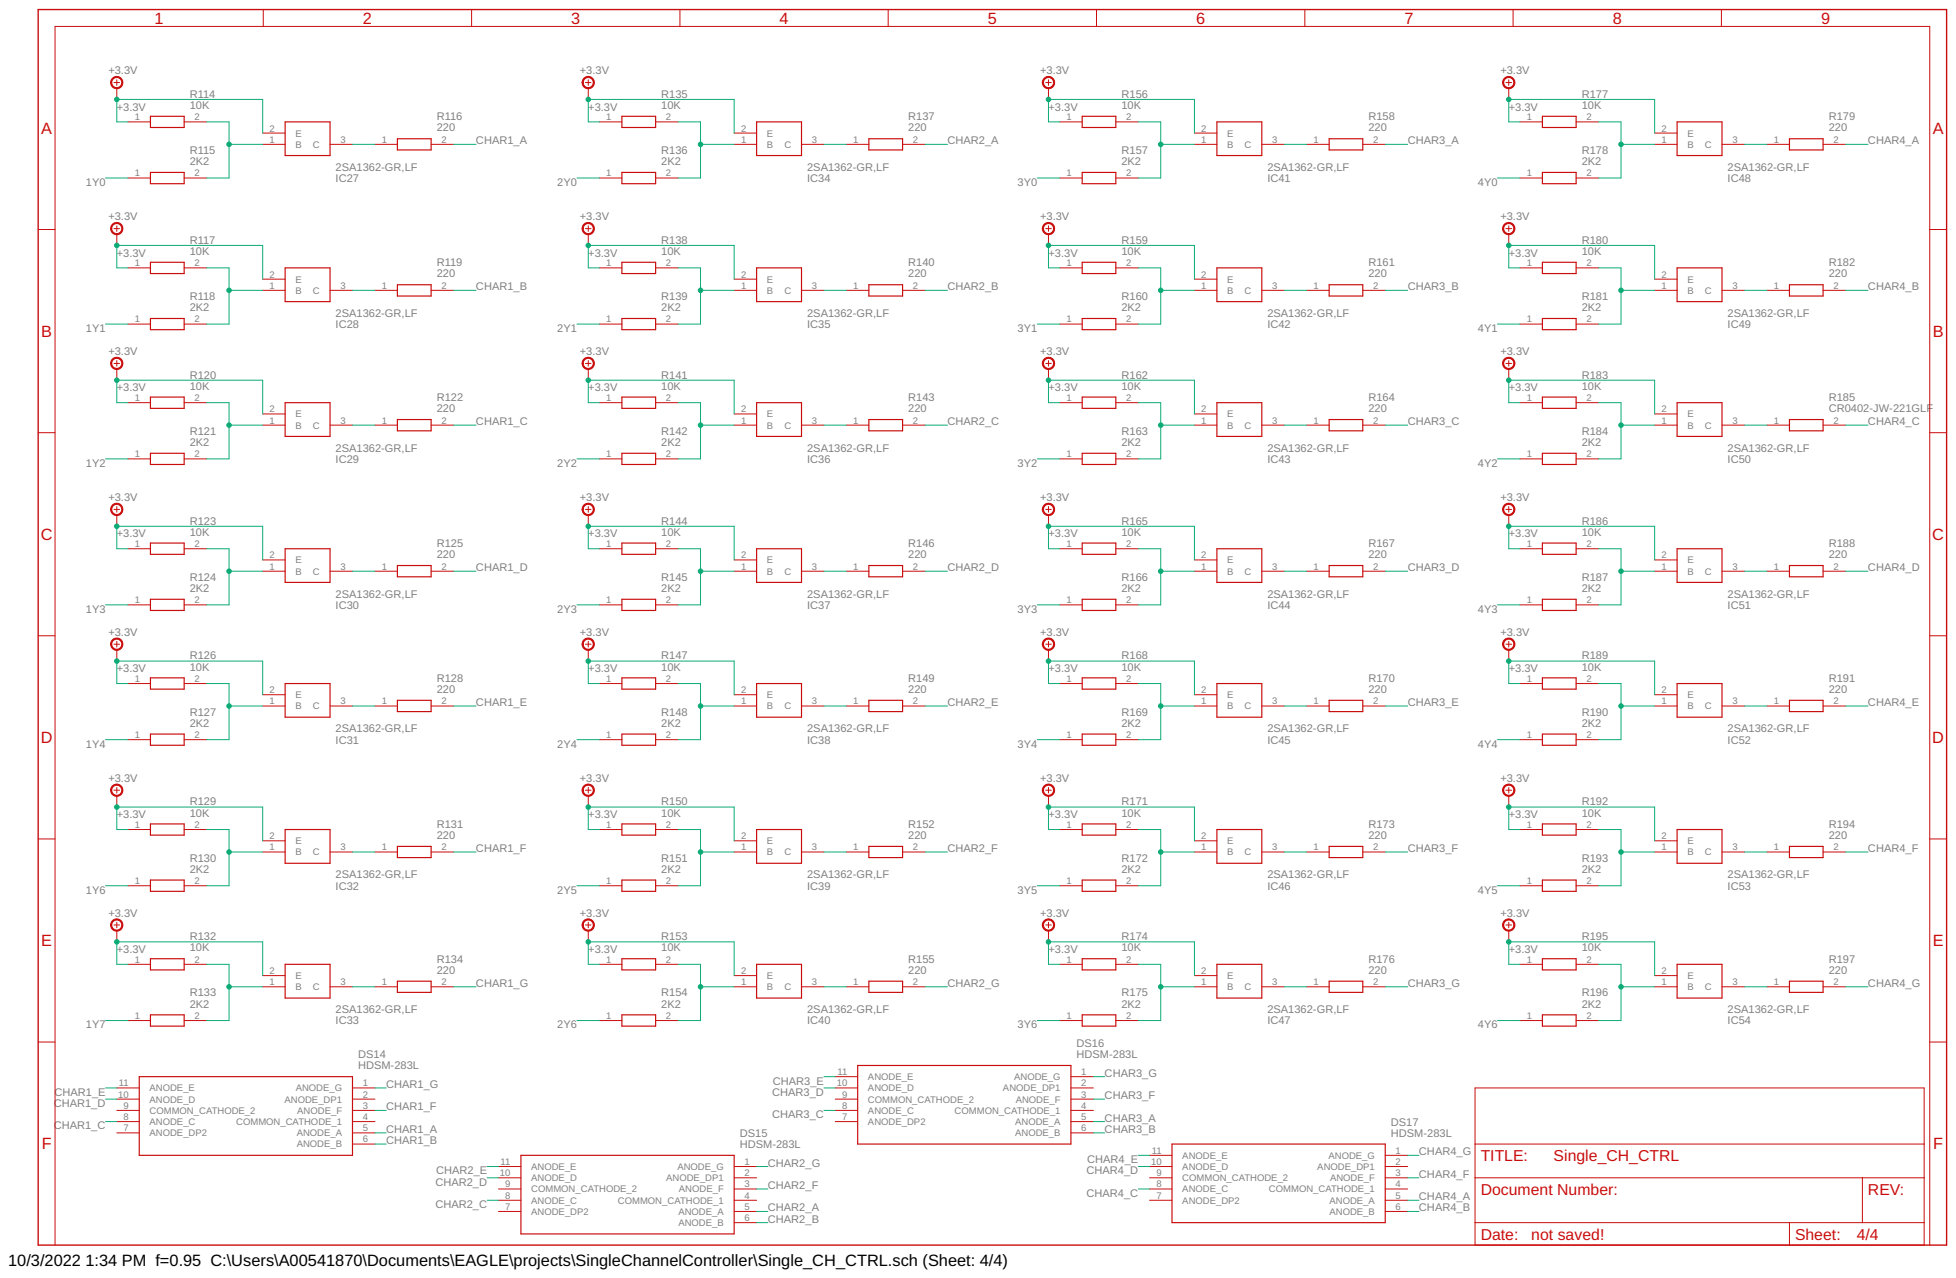
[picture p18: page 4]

10/3/2022 1:34 PM f=0.95 C:\Users\A00541870\Documents\EAGLE\projects\SingleChannelController\Single_CH_CTRL.sch (Sheet: 4/4)

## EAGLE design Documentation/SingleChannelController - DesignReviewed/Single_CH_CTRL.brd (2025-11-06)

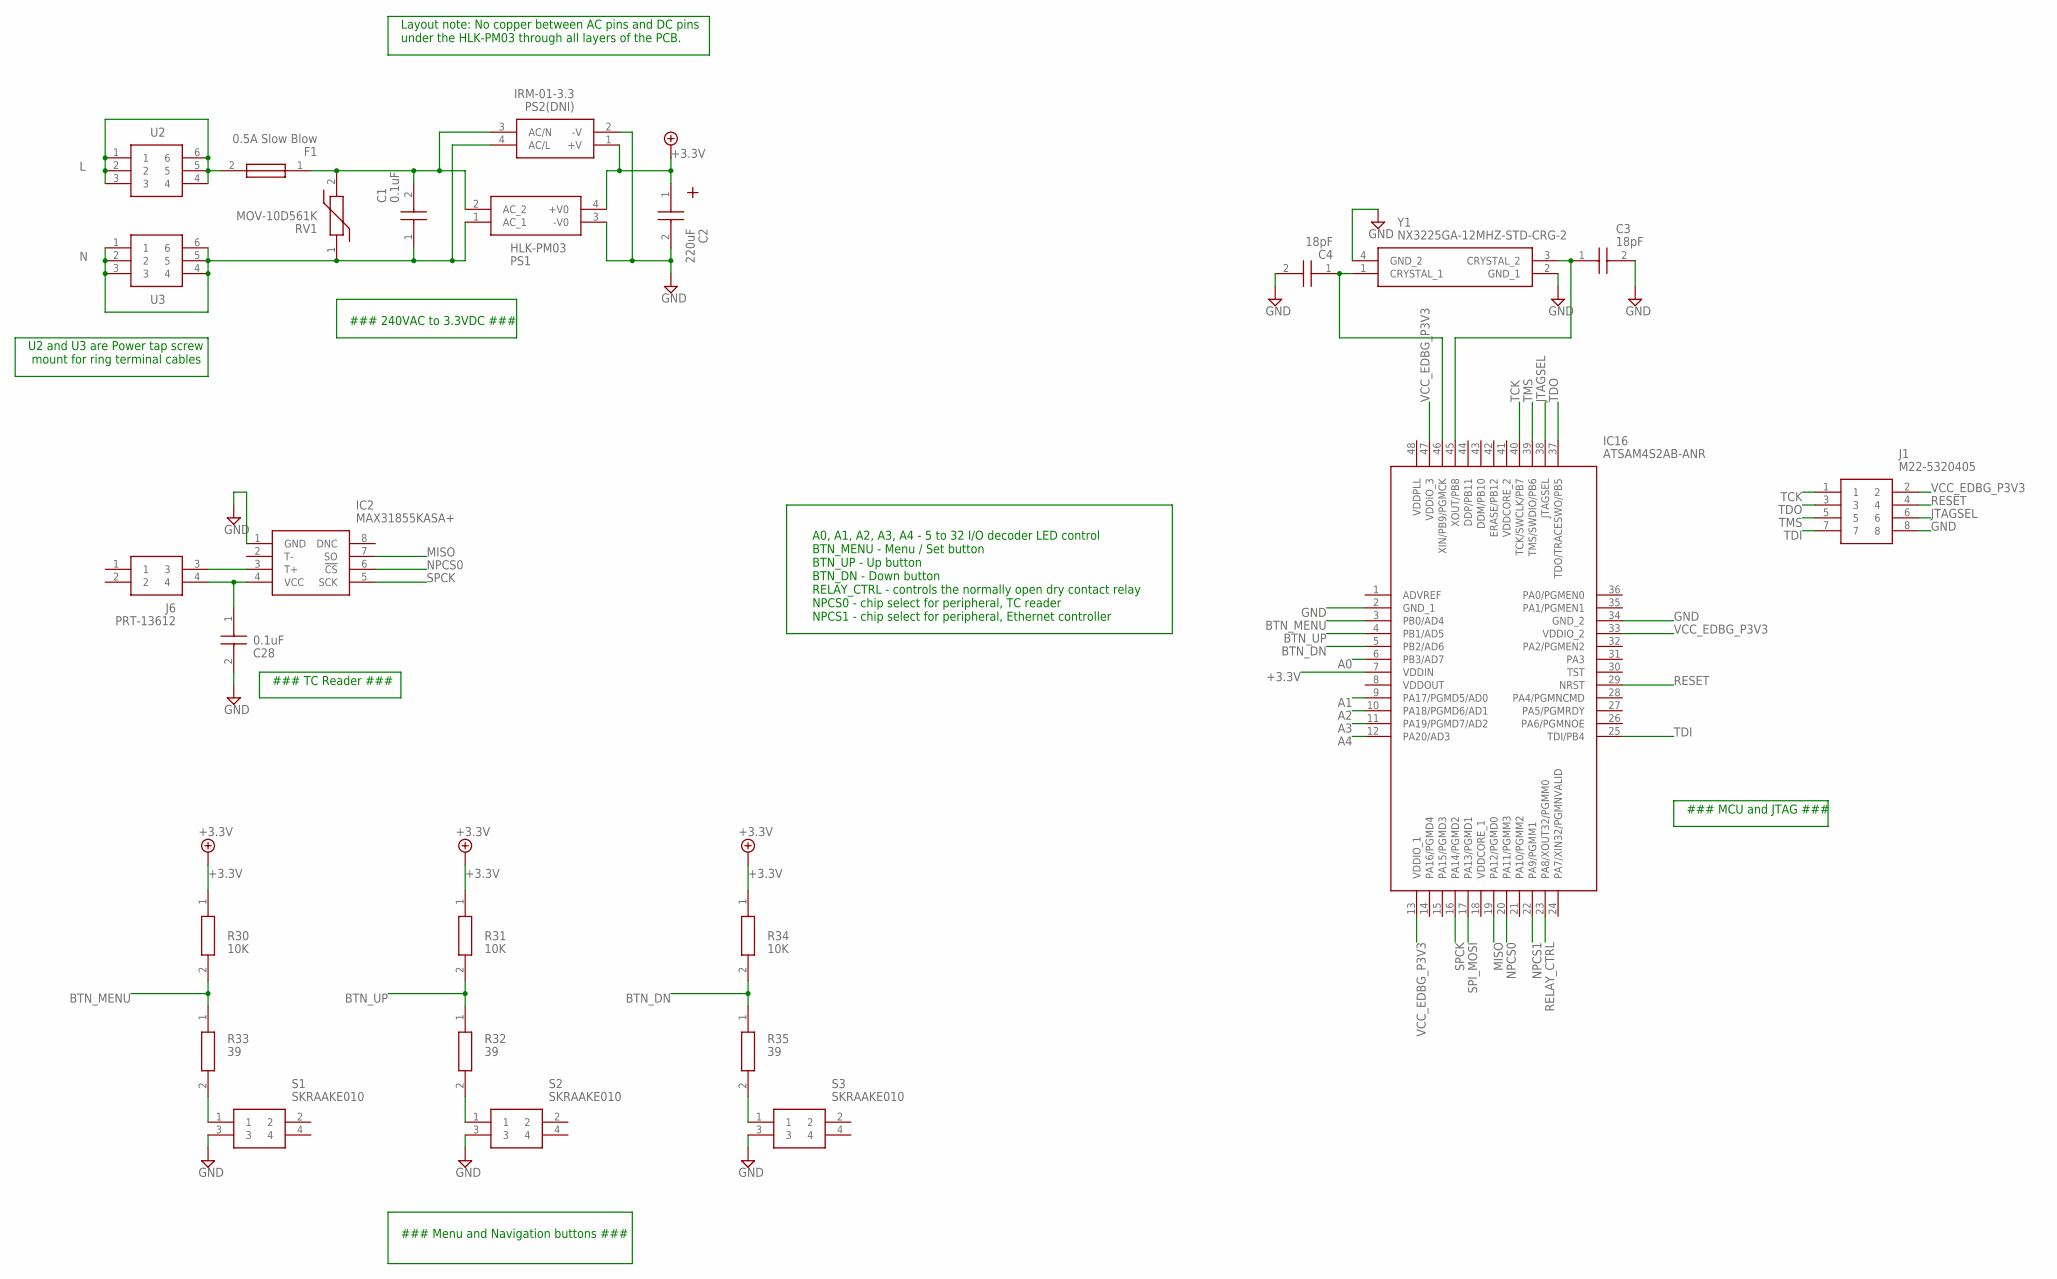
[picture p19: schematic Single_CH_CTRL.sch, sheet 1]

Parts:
C1: 0.1uF; B32922X_(18_X_5)
C2: 220uF; CAPPRD250W52D630H1250
C3, C4: 18pF; CAPC1005X56N
C28: 0.1uF; CAPC2012X88N
F1: 0.5A Slow Blow; RST500AMMO
IC2: MAX31855KASA+; SOIC127P600X175-8N
IC16: ATSAM4S2AB-ANR; QFP50P900X900X160-48N
J1: M22-5320405; HUSSP8W50P200_2X4_800X400X500P
J6: PRT-13612; PRT13612
PS1: HLK-PM03; HLKPM03
PS2(DNI): IRM-01-3.3; IRM015
R30, R31, R34: 10K; RESC1005X35N
R32, R33, R35: 39; RESC1005X40N
RV1: MOV-10D561K; MOV10D561K
S1, S2, S3: SKRAAKE010; SKRAAKE010_1
U2, U3: 5055323-9; 50553239
Y1: NX3225GA-12MHZ-STD-CRG-2; NX3225GA12MHZSTDCRG2

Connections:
+3.3V: C2.1 (+), IC16.7 (VDDIN), PS1.4 (+V0), PS2(DNI).1 (+V), R30.1, R31.1, R34.1; also elsewhere on the board
A0: IC16.6 (PB3/AD7)
A1: IC16.9 (PA17/PGMD5/AD0)
A2: IC16.10 (PA18/PGMD6/AD1)
A3: IC16.11 (PA19/PGMD7/AD2)
A4: IC16.12 (PA20/AD3)
BTN_DN: IC16.5 (PB2/AD6), R34.2, R35.1
BTN_MENU: IC16.3 (PB0/AD4), R30.2, R33.1
BTN_UP: IC16.4 (PB1/AD5), R31.2, R32.1
GND: C2.2 (-), C3.2, C4.2, C28.2, IC2.1 (GND), IC16.2 (GND_1), IC16.34 (GND_2), J1.8, PS1.3 (-V0), PS2(DNI).2 (-V), S1.3, S2.3, S3.3, Y1.2 (GND_1), Y1.4 (GND_2); also elsewhere on the board
JTAGSEL: IC16.38 (JTAGSEL), J1.6
L: F1.2, U2.1, U2.2, U2.3, U2.4, U2.5, U2.6
MISO: IC2.7 (SO), IC16.19 (PA12/PGMD0); also elsewhere on the board
N: C1.1, PS1.1 (AC_1), PS2(DNI).4 (AC/L), RV1.1, U3.1, U3.2, U3.3, U3.4, U3.5, U3.6
unnamed: C1.2, F1.1, PS1.2 (AC_2), PS2(DNI).3 (AC/N), RV1.2
unnamed: C3.1, IC16.45 (XOUT/PB8), Y1.3 (CRYSTAL_2)
unnamed: C4.1, IC16.46 (XIN/PB9/PGMCK), Y1.1 (CRYSTAL_1)
unnamed: R33.2, S1.1
unnamed: R32.2, S2.1
unnamed: R35.2, S3.1
unnamed: C28.1, IC2.4 (VCC), J6.4
unnamed: IC2.3 (T+), J6.3
NPCS0: IC2.6 (!CS), IC16.20 (PA11/PGMM3)
NPCS1: IC16.22 (PA9/PGMM1); also elsewhere on the board
RELAY_CTRL: IC16.23 (PA8/XOUT32/PGMM0); also elsewhere on the board
RESET: IC16.29 (NRST), J1.4
SPCK: IC2.5 (SCK), IC16.16 (PA14/PGMD2); also elsewhere on the board
SPI_MOSI: IC16.17 (PA13/PGMD1); also elsewhere on the board
TCK: IC16.40 (TCK/SWCLK/PB7), J1.1
TDI: IC16.25 (TDI/PB4), J1.7
TDO: IC16.37 (TDO/TRACESWO/PB5), J1.3
TMS: IC16.39 (TMS/SWDIO/PB6), J1.5
VCC_EDBG_P3V3: IC16.13 (VDDIO_1), IC16.33 (VDDIO_2), IC16.47 (VDDIO_3), J1.2

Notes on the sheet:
A0, A1, A2, A3, A4 - 5 to 32 I/O decoder LED control BTN_MENU - Menu / Set button BTN_UP - Up button BTN_DN - Down button RELAY_CTRL - controls the normally open dry contact relay NPCS0 - chip select for peripheral, TC reader NPCS1 - chip select for peripheral, Ethernet controller
Layout note: No copper between AC pins and DC pins under the HLK-PM03 through all layers of the PCB.
### 240VAC to 3.3VDC ###
### TC Reader ###
### MCU and JTAG ###
### Menu and Navigation buttons ###
U2 and U3 are Power tap screw mount for ring terminal cables

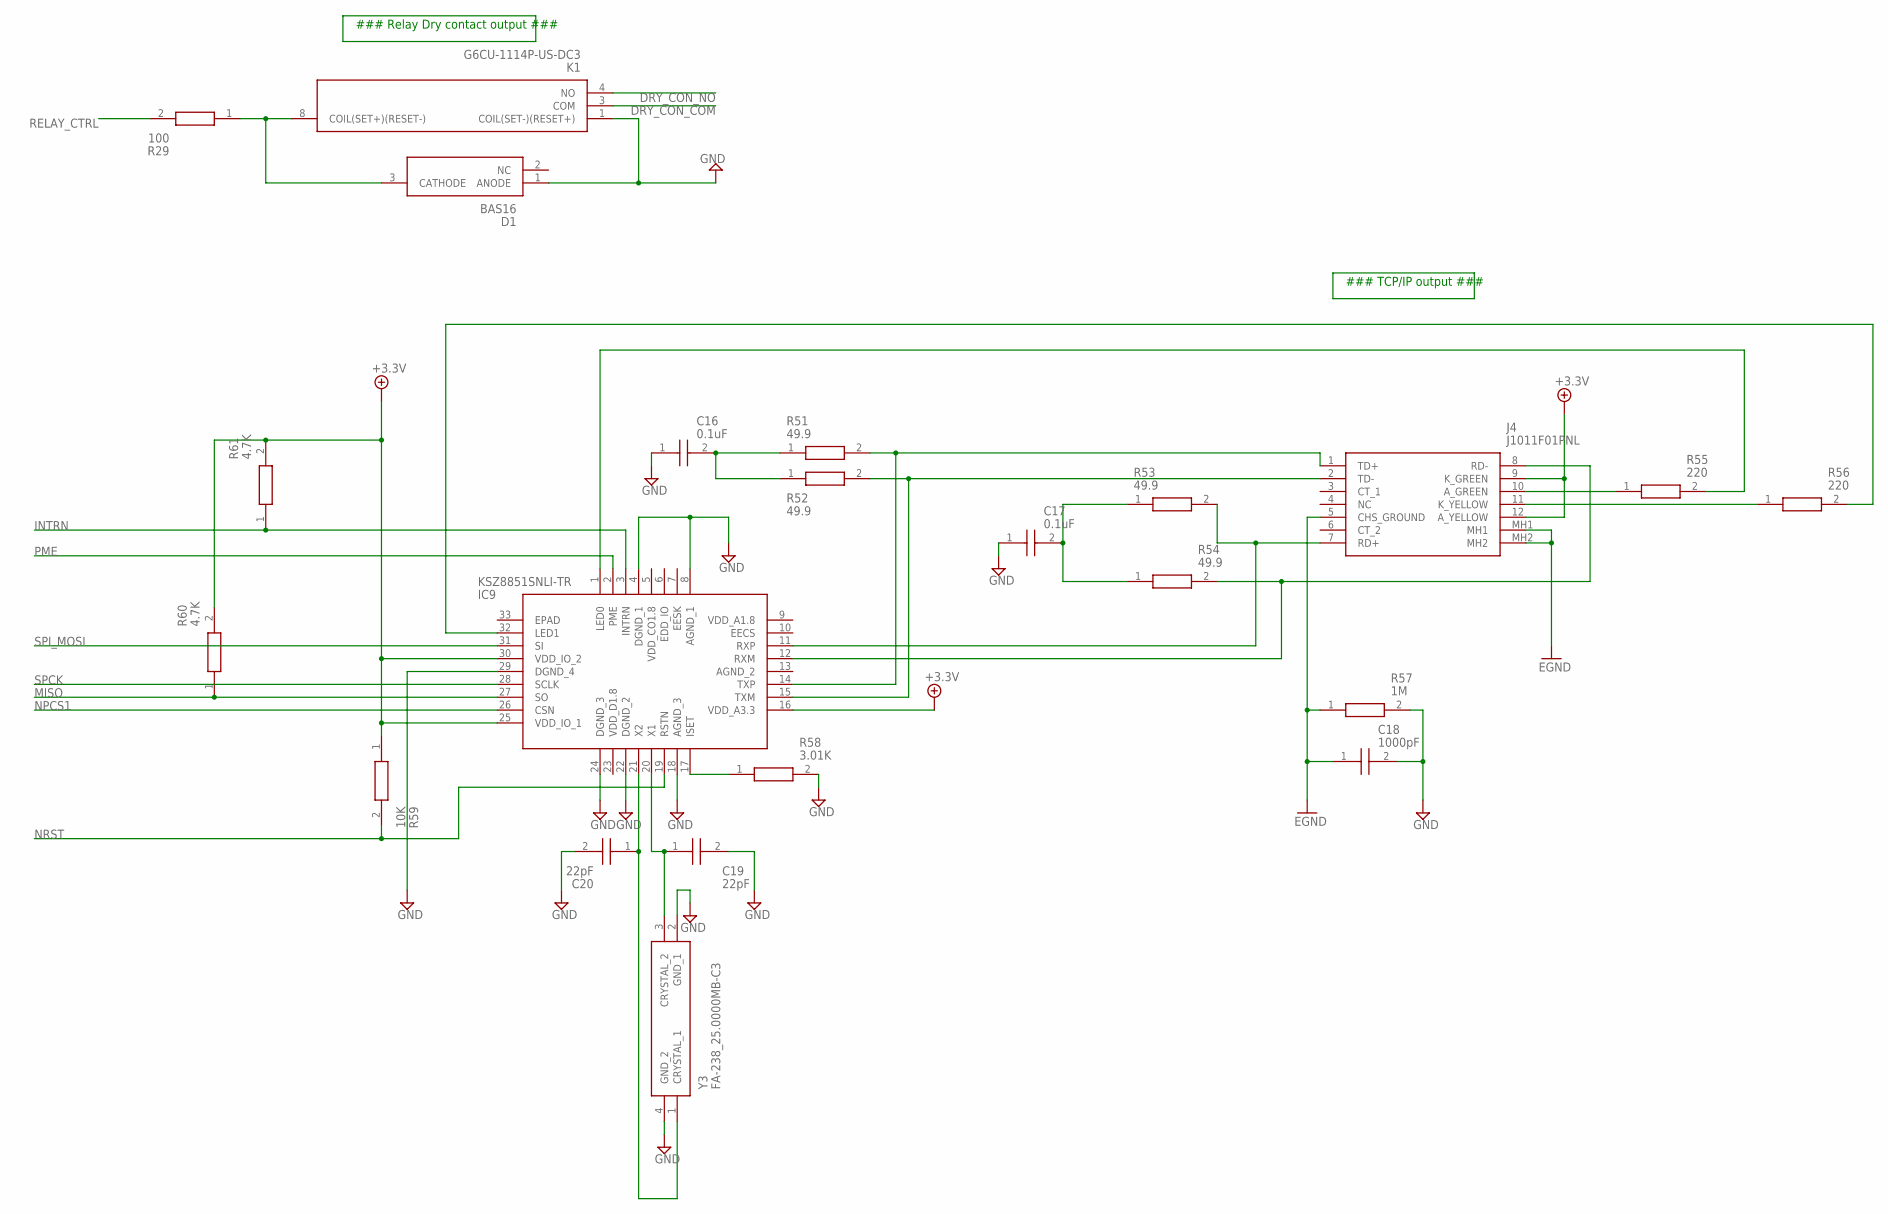
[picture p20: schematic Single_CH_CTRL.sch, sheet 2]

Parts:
C16, C17: 0.1uF; C0402
C18: 1000pF; C4520_COMMERCIAL
C19, C20: 22pF; CBR04C
D1: BAS16; SOT95P240X110-3N
IC9: KSZ8851SNLI-TR; QFN50P500X500X100-33N
J4: J1011F01PNL
K1: G6CU-1114P-US-DC3; G6CU1114PUSDC3
R29: 100; ERJP03_PA3_(0603)
R51, R52, R53, R54: 49.9; ERJS02_U02_(0402)
R55, R56: 220; RESC1005X40N
R57: 1M; RESC2012X60N
R58: 3.01K; RESC1005X40N
R59: 10K; RESC1005X40N
R60, R61: 4.7K; RESC1005X40N
Y3: FA-238_25.0000MB-C3; FA238300000MBC0

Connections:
+3.3V: IC9.16 (VDD_A3.3), IC9.25 (VDD_IO_1), IC9.30 (VDD_IO_2), J4.9 (K_GREEN), J4.12 (A_YELLOW), R59.1, R60.2, R61.2; also elsewhere on the board
DRY_CON_COM: K1.3 (COM)
DRY_CON_NO: K1.4 (NO)
GND: C16.1, C17.1, C18.1, C18.2, C19.2, C20.2, D1.1 (ANODE), IC9.4 (DGND_1), IC9.8 (AGND_1), IC9.18 (AGND_3), IC9.22 (DGND_2), IC9.24 (DGND_3), IC9.29 (DGND_4), J4.5 (CHS_GROUND), J4.MH1, J4.MH2, K1.1 (COIL(SET-)(RESET+)), R57.1, R57.2, R58.2, Y3.2 (GND_1), Y3.4 (GND_2); also elsewhere on the board
INTRN: IC9.3 (INTRN), R61.1
MISO: IC9.27 (SO), R60.1; also elsewhere on the board
unnamed: D1.3 (CATHODE), K1.8 (COIL(SET+)(RESET-)), R29.1
unnamed: IC9.14 (TXP), J4.1 (TD+), R51.2
unnamed: IC9.15 (TXM), J4.2 (TD-), R52.2
unnamed: IC9.11 (RXP), J4.7 (RD+), R53.2
unnamed: C16.2, R51.1, R52.1
unnamed: C17.2, R53.1, R54.1
unnamed: IC9.12 (RXM), J4.8 (RD-), R54.2
unnamed: J4.10 (A_GREEN), R55.1
unnamed: J4.11 (K_YELLOW), R56.1
unnamed: IC9.1 (LED0), R55.2
unnamed: IC9.32 (LED1), R56.2
unnamed: C19.1, IC9.20 (X1), Y3.3 (CRYSTAL_2)
unnamed: C20.1, IC9.21 (X2), Y3.1 (CRYSTAL_1)
unnamed: IC9.17 (ISET), R58.1
NPCS1: IC9.26 (CSN); also elsewhere on the board
NRST: IC9.19 (RSTN), R59.2
PME: IC9.2 (PME)
RELAY_CTRL: R29.2; also elsewhere on the board
SPCK: IC9.28 (SCLK); also elsewhere on the board
SPI_MOSI: IC9.31 (SI); also elsewhere on the board

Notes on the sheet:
### Relay Dry contact output ###
### TCP/IP output ###

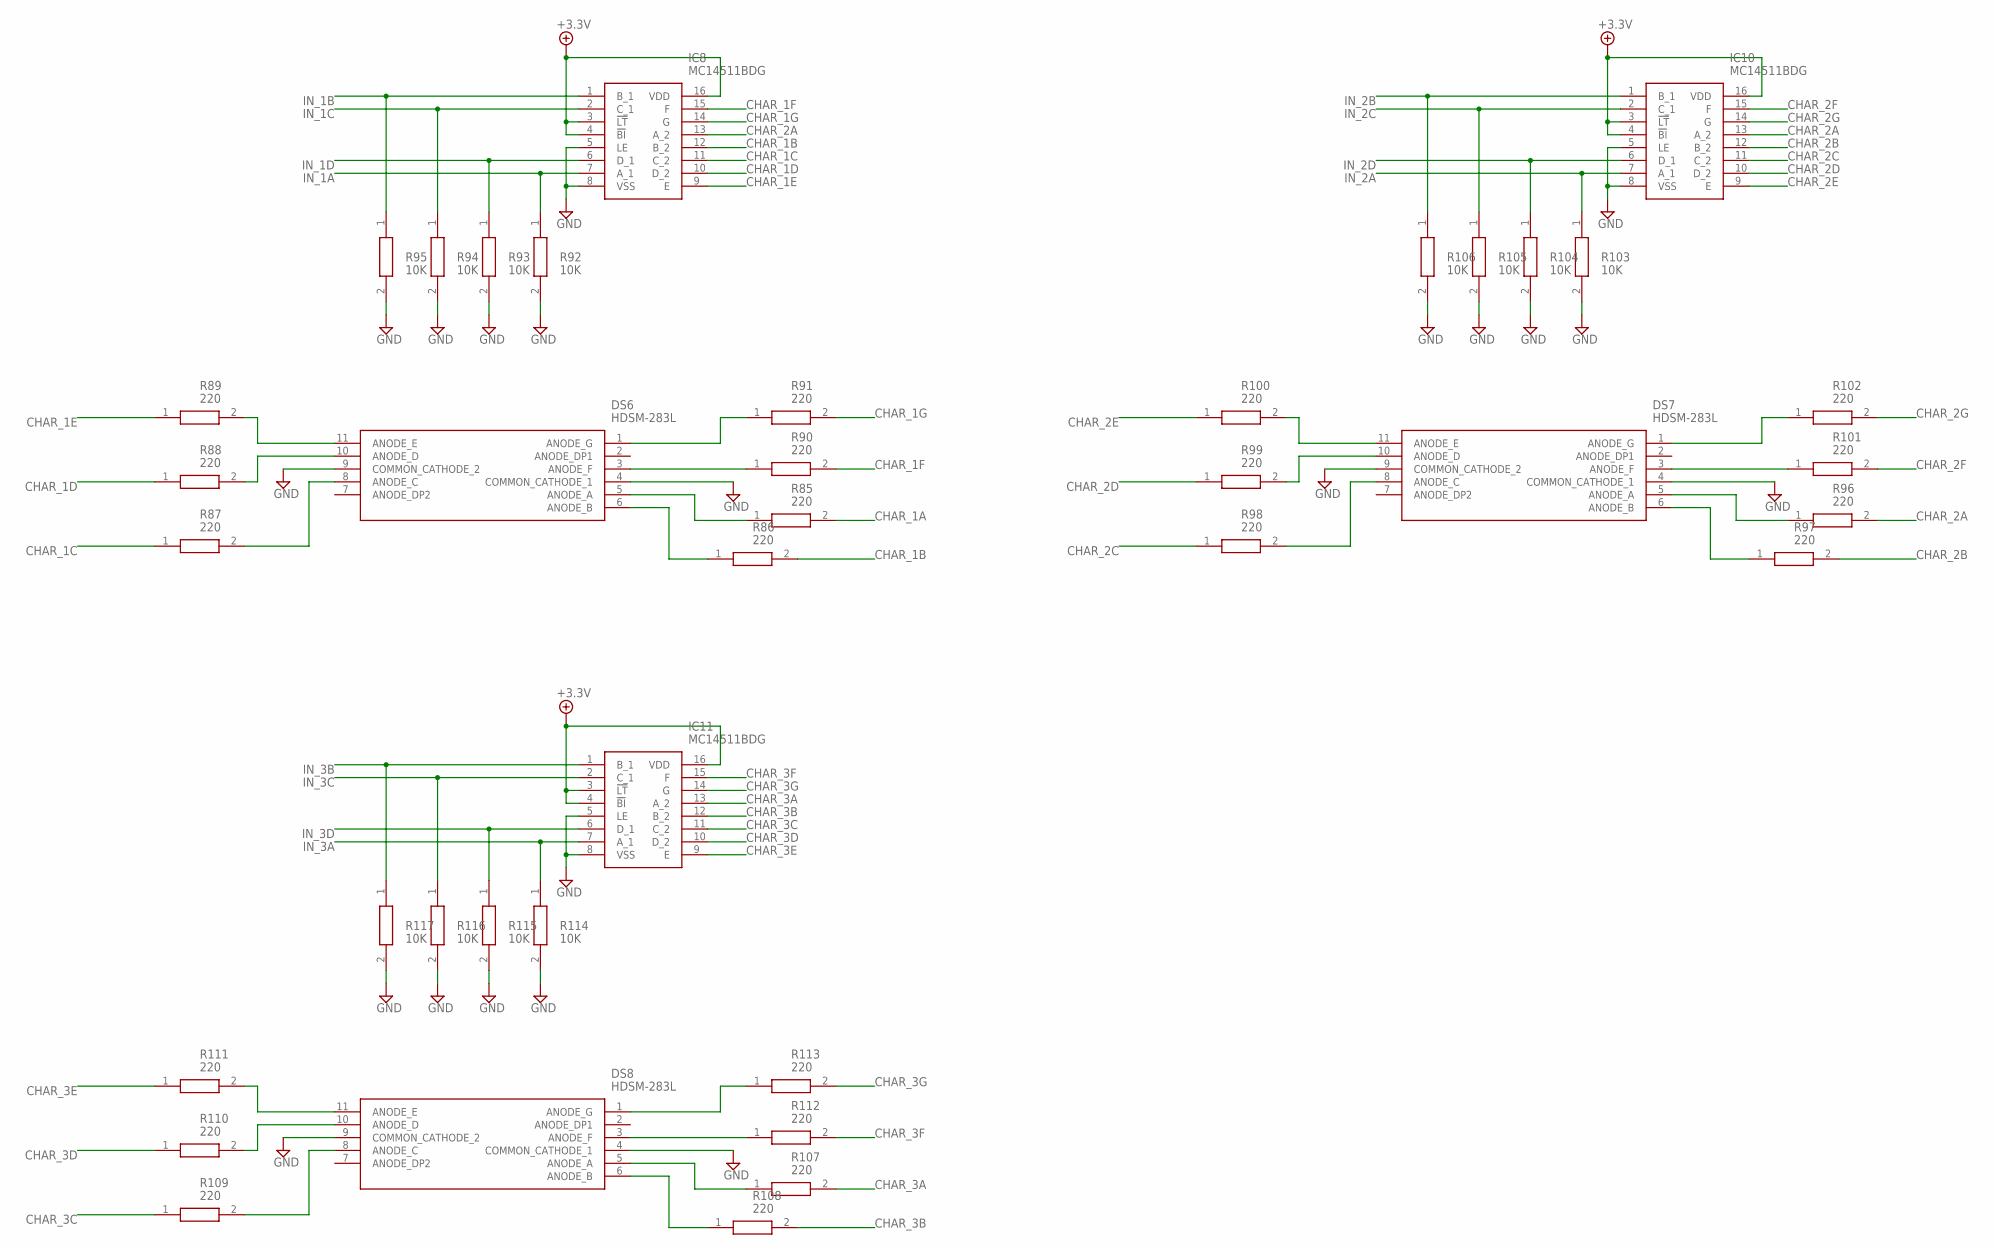
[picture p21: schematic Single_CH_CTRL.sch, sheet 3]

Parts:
DS6, DS7, DS8: HDSM-283L; HDSM283L
IC8, IC10, IC11: MC14511BDG; SOIC127P600X175-16N
R85, R86, R87, R88, R89, R90, R91, R96, R97, R98, R99, R100, R101, R102, R107, R108, R109, R110, R111, R112, R113: 220; RESC1005X40N
R92, R93, R94, R95, R103, R104, R105, R106, R114, R115, R116, R117: 10K; RESC1005X35N

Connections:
+5V: IC8.3 (!LT), IC8.4 (!BI), IC8.16 (VDD), IC10.3 (!LT), IC10.4 (!BI), IC10.16 (VDD), IC11.3 (!LT), IC11.4 (!BI), IC11.16 (VDD)
CHAR_1A: R85.2
CHAR_1B: IC8.12 (B_2), R86.2
CHAR_1C: IC8.11 (C_2), R87.1
CHAR_1D: IC8.10 (D_2), R88.1
CHAR_1E: IC8.9 (E), R89.1
CHAR_1F: IC8.15 (F), R90.2
CHAR_1G: IC8.14 (G), R91.2
CHAR_2A: IC8.13 (A_2), IC10.13 (A_2), R96.2
CHAR_2B: IC10.12 (B_2), R97.2
CHAR_2C: IC10.11 (C_2), R98.1
CHAR_2D: IC10.10 (D_2), R99.1
CHAR_2E: IC10.9 (E), R100.1
CHAR_2F: IC10.15 (F), R101.2
CHAR_2G: IC10.14 (G), R102.2
CHAR_3A: IC11.13 (A_2), R107.2
CHAR_3B: IC11.12 (B_2), R108.2
CHAR_3C: IC11.11 (C_2), R109.1
CHAR_3D: IC11.10 (D_2), R110.1
CHAR_3E: IC11.9 (E), R111.1
CHAR_3F: IC11.15 (F), R112.2
CHAR_3G: IC11.14 (G), R113.2
GND: DS6.4 (COMMON_CATHODE_1), DS6.9 (COMMON_CATHODE_2), DS7.4 (COMMON_CATHODE_1), DS7.9 (COMMON_CATHODE_2), DS8.4 (COMMON_CATHODE_1), DS8.9 (COMMON_CATHODE_2), IC8.5 (LE), IC8.8 (VSS), IC10.5 (LE), IC10.8 (VSS), IC11.5 (LE), IC11.8 (VSS), R92.2, R93.2, R94.2, R95.2, R103.2, R104.2, R105.2, R106.2, R114.2, R115.2, R116.2, R117.2; also elsewhere on the board
IN_1A: IC8.7 (A_1), R92.1
IN_1B: IC8.1 (B_1), R95.1
IN_1C: IC8.2 (C_1), R94.1
IN_1D: IC8.6 (D_1), R93.1
IN_2A: IC10.7 (A_1), R103.1
IN_2B: IC10.1 (B_1), R106.1
IN_2C: IC10.2 (C_1), R105.1
IN_2D: IC10.6 (D_1), R104.1
IN_3A: IC11.7 (A_1), R114.1
IN_3B: IC11.1 (B_1), R117.1
IN_3C: IC11.2 (C_1), R116.1
IN_3D: IC11.6 (D_1), R115.1
unnamed: DS6.11 (ANODE_E), R89.2
unnamed: DS6.8 (ANODE_C), R87.2
unnamed: DS6.1 (ANODE_G), R91.1
unnamed: DS6.3 (ANODE_F), R90.1
unnamed: DS6.5 (ANODE_A), R85.1
unnamed: DS6.6 (ANODE_B), R86.1
unnamed: DS6.10 (ANODE_D), R88.2
unnamed: DS7.11 (ANODE_E), R100.2
unnamed: DS7.8 (ANODE_C), R98.2
unnamed: DS7.1 (ANODE_G), R102.1
unnamed: DS7.3 (ANODE_F), R101.1
unnamed: DS7.5 (ANODE_A), R96.1
unnamed: DS7.6 (ANODE_B), R97.1
unnamed: DS7.10 (ANODE_D), R99.2
unnamed: DS8.11 (ANODE_E), R111.2
unnamed: DS8.8 (ANODE_C), R109.2
unnamed: DS8.1 (ANODE_G), R113.1
unnamed: DS8.3 (ANODE_F), R112.1
unnamed: DS8.5 (ANODE_A), R107.1
unnamed: DS8.6 (ANODE_B), R108.1
unnamed: DS8.10 (ANODE_D), R110.2

Board: 4 copper layers, 86 parts (0 on the bottom side), 98 nets, no tracks yet.

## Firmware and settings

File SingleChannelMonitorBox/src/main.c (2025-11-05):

/*
 * FreeRTOS V202112.00
 * Copyright (C) 2020 Amazon.com, Inc. or its affiliates.  All Rights Reserved.
 *
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
 * http://www.FreeRTOS.org
 * http://aws.amazon.com/freertos
 *
 * 1 tab == 4 spaces!
 */

/******************************************************************************
 * This project provides two demo applications.  A simple blinky style project,
 * and a more comprehensive test and demo application.  The
 * mainCREATE_SIMPLE_BLINKY_DEMO_ONLY setting (defined in this file) is used to
 * select between the two.  The simply blinky demo is implemented and described
 * in main_blinky.c.  The more comprehensive test and demo application is
 * implemented and described in main_full.c.
 *
 * This file implements the code that is not demo specific, including the
 * hardware setup and FreeRTOS hook functions.
 *
 */

/* TO DO before product release!
*  Adjust heap and memory characteristics to match the processor if different from prototype
*  If different ethernet chip is used, adjust PHY and network interface layer
*/

/* Standard includes. */
#include <stdio.h>
#include <ctype.h>

/* Demo application includes. */
//#include "TCPEchoClient_SingleTasks.h"

#include "hr_gettime.h"

/* Atmel includes. */
#include "board.h"
#include "conf_board.h"
#include "asf.h"
#include "apptasks.h"

/* FreeRTOS+TCP includes. */
#include "FreeRTOS_IP.h"
/*
/* FreeRTOS+FAT includes. */
#include "ff_stdio.h"

/* Modbus Includes */
#include "mbport.h"

void vLoggingPrintf( const char *pcFormatString, ... )
{
	//do nothing since logging isn't available
}



/* Set the following constants to 1 or 0 to define which tasks to include and
exclude.  A WIDER RANGE OF EXAMPLES ARE AVAILABLE IN THE WIN32 DEMO:
http://www.freertos.org/FreeRTOS-Plus/FreeRTOS_Plus_TCP/examples_FreeRTOS_simulator.html

mainCREATE_UDP_CLI_TASKS:  When set to 1 a command console that uses a UDP port
for input and output is created using FreeRTOS+CLI.  The port number used is set
by the mainUDP_CLI_PORT_NUMBER constant above.  A dumb UDP terminal such as YAT
can be used to connect.
See http://www.freertos.org/FreeRTOS-Plus/FreeRTOS_Plus_TCP/UDP_CLI.html

mainCREATE_TCP_ECHO_TASKS_SINGLE:  When set to 1 a set of tasks are created that
send TCP echo requests to the standard echo port (port 7), then wait for and
verify the echo reply, from within the same task (Tx and Rx are performed in the
same RTOS task).  The IP address of the echo server must be configured using the
configECHO_SERVER_ADDR0 to configECHO_SERVER_ADDR3 constants in
FreeRTOSConfig.h.
See http://www.freertos.org/FreeRTOS-Plus/FreeRTOS_Plus_TCP/TCP_Echo_Clients.html

mainCREATE_SIMPLE_TCP_ECHO_SERVER:  When set to 1 FreeRTOS tasks are used with
FreeRTOS+TCP to create a TCP echo server.  Echo requests can be sent to the
FreeRTOS+TCP using a tool such as EchoTool https://github.com/PavelBansky/EchoTool
(a pre-built binary is available).
See http://www.freertos.org/FreeRTOS-Plus/FreeRTOS_Plus_TCP/TCP_Echo_Server.html
*/
#define mainCREATE_UDP_CLI_TASKS				0
#define mainCREATE_TCP_ECHO_CLIENT_TASKS_SINGLE	0
#define mainCREATE_SIMPLE_TCP_ECHO_SERVER		0

/* UDP CLI task parameters --------------------------------------------------
See http://www.freertos.org/FreeRTOS-Plus/FreeRTOS_Plus_TCP/UDP_CLI.html */
#define mainUDP_CLI_TASK_PRIORITY		( tskIDLE_PRIORITY )
#define mainUDP_CLI_PORT_NUMBER			( 5001UL )
#define mainUDP_CLI_TASK_STACK_SIZE		( configMINIMAL_STACK_SIZE * 6 )

/* Simple echo client task parameters ---------------------------------------
See http://www.freertos.org/FreeRTOS-Plus/FreeRTOS_Plus_TCP/TCP_Echo_Clients.html */
#define mainECHO_CLIENT_TASK_STACK_SIZE ( configMINIMAL_STACK_SIZE * 4 )
#define mainECHO_CLIENT_TASK_PRIORITY	( tskIDLE_PRIORITY + 1 )

/* Simple echo server task parameters ---------------------------------------
See http://www.freertos.org/FreeRTOS-Plus/FreeRTOS_Plus_TCP/TCP_Echo_Server.html */
#define mainECHO_SERVER_TASK_PRIORITY	( tskIDLE_PRIORITY + 1 )
#define	mainECHO_SERVER_STACK_SIZE		( configMINIMAL_STACK_SIZE * 4 )

/* Other configuration parameters -------------------------------------------*/

/* The period after which the check timer will expire, in ms, provided no errors
have been reported by any of the standard demo tasks.  ms are converted to the
equivalent in ticks using the portTICK_PERIOD_MS constant. */
#define mainCHECK_TIMER_PERIOD_MS			( pdMS_TO_TICKS( 3000UL ) )

/* A block time of zero simply means "don't block". */
#define mainDONT_BLOCK						( 0UL )

/* Define names that will be used for DNS, LLMNR and NBNS searches.  This allows
mainHOST_NAME to be used when the IP address is not known.  For example
"ping RTOSDemo" to resolve RTOSDemo to an IP address then send a ping request. */
#define mainHOST_NAME					"TempMonitor"
#define mainDEVICE_NICK_NAME			"sam4spro"

/* The LED to toggle and the rate at which the LED will be toggled. */
#define mainLED_TOGGLE_PERIOD			pdMS_TO_TICKS( 250 )

/*
 * Just seeds the simple pseudo random number generator.
 */
static void prvSRand( UBaseType_t ulSeed );

/*
 * Miscellaneous initialisation including preparing the logging and seeding the
 * random number generator.
 */
static void prvMiscInitialisation( void );

/* Use by the pseudo random number generator. */
static UBaseType_t ulNextRand;

/* Used to place the heap. */
extern char _estack;
/*
 * Set up the hardware ready to run this demo.
 */
static void prvSetupHardware( void );

static void prvInitialiseHeap( void );

/*
 * Callback function for the timer that toggles an LED.
 */
static void prvLEDTimerCallback( TimerHandle_t xTimer );

/*
 * Starts an interface to FreeRTOS+CLI that uses a UDP port for input and
 * output.
 */
extern void vStartUDPCommandInterpreterTask( uint16_t usStackSize, uint32_t ulPort, UBaseType_t uxPriority );


int main( void )
{

	/* Miscellaneous initialisation including preparing the logging and seeding
	the random number generator. */
	prvMiscInitialisation();
	
	startTasks(); //creates all tasks and initializes interfaces


	/* Start the RTOS scheduler. */
	FreeRTOS_debug_printf( ("vTaskStartScheduler\n") );
	vTaskStartScheduler();

	/* If all is well, the scheduler will now be running, and the following
	line will never be reached.  If the following line does execute, then
	there was insufficient FreeRTOS heap memory available for the idle and/or
	timer tasks	to be created.  See the memory management section on the
	FreeRTOS web site for more details.  http://www.freertos.org/a00111.html */
	for( ;; )
	{
	}
}

/*-----------------------------------------------------------*/

static void prvSetupHardware( void )
{
extern void SystemCoreClockUpdate( void );

	/* ASF function to setup clocking. */
	sysclk_init();

	/* Ensure all priority bits are assigned as preemption priority bits. */
	NVIC_SetPriorityGrouping( 0 );

	/* Atmel library function to setup for the evaluation kit being used. */
	board_init();
}
/*-----------------------------------------------------------*/

void vApplicationMallocFailedHook( void )
{
	/* vApplicationMallocFailedHook() will only be called if
	configUSE_MALLOC_FAILED_HOOK is set to 1 in FreeRTOSConfig.h.  It is a hook
	function that will get called if a call to pvPortMalloc() fails.
	pvPortMalloc() is called internally by the kernel whenever a task, queue,
	timer or semaphore is created.  It is also called by various parts of the
	demo application.  If heap_1.c or heap_2.c are used, then the size of the
	heap available to pvPortMalloc() is defined by configTOTAL_HEAP_SIZE in
	FreeRTOSConfig.h, and the xPortGetFreeHeapSize() API function can be used
	to query the size of free heap space that remains (although it does not
	provide information on how the remaining heap might be fragmented). */
	taskDISABLE_INTERRUPTS();
	for( ;; );
}

void vApplicationIdleHook( void )
{
	/* vApplicationIdleHook() will only be called if configUSE_IDLE_HOOK is set
	to 1 in FreeRTOSConfig.h.  It will be called on each iteration of the idle
	task.  It is essential that code added to this hook function never attempts
	to block in any way (for example, call xQueueReceive() with a block time
	specified, or call vTaskDelay()).  If the application makes use of the
	vTaskDelete() API function (as this demo application does) then it is also
	important that vApplicationIdleHook() is permitted to return to its calling
	function, because it is the responsibility of the idle task to clean up
	memory allocated by the kernel to any task that has since been deleted. */
}
/*-----------------------------------------------------------*/

void vApplicationStackOverflowHook( TaskHandle_t pxTask, char *pcTaskName )
{
	( void ) pcTaskName;
	( void ) pxTask;

	/* Run time stack overflow checking is performed if
	configCHECK_FOR_STACK_OVERFLOW is defined to 1 or 2.  This hook
	function is called if a stack overflow is detected. */
	taskDISABLE_INTERRUPTS();
	for( ;; );
}
/*-----------------------------------------------------------*/

void vApplicationTickHook( void )
{
	/* This function will be called by each tick interrupt if
	configUSE_TICK_HOOK is set to 1 in FreeRTOSConfig.h.  User code can be
	added here, but the tick hook is called from an interrupt context, so
	code must not attempt to block, and only the interrupt safe FreeRTOS API
	functions can be used (those that end in FromISR()).  */

	#if ( mainCREATE_SIMPLE_BLINKY_DEMO_ONLY == 0 )
	{
	extern void vFullDemoTickHook( void );
	
		vFullDemoTickHook();
	}
	#endif /* mainCREATE_SIMPLE_BLINKY_DEMO_ONLY */
}

/*-----------------------------------------------------------*/

void vAssertCalled( const char *pcFile, uint32_t ulLine )
{
volatile uint32_t ulBlockVariable = 0UL;
volatile const char *pcAssertedFileName;
volatile int iAssertedErrno;
volatile uint32_t ulAssertedLine;
volatile FF_Error_t xAssertedFF_Error;

	ulAssertedLine = ulLine;
	iAssertedErrno = stdioGET_ERRNO();
	xAssertedFF_Error = stdioGET_FF_ERROR( );
	pcAssertedFileName = strrchr( pcFile, '/' );

	/* These variables are set so they can be viewed in the debugger, but are
	not used in the code - the following lines just remove the compiler warning
	about this. */
	( void ) ulAssertedLine;
	( void ) iAssertedErrno;
	( void ) xAssertedFF_Error;

	if( pcAssertedFileName == 0 )
	{
		pcAssertedFileName = strrchr( pcFile, '\\' );
	}
	if( pcAssertedFileName != NULL )
	{
		pcAssertedFileName++;
	}
	else
	{
		pcAssertedFileName = pcFile;
	}
	FreeRTOS_printf( ( "vAssertCalled( %s, %ld\n", pcFile, ulLine ) );

	/* Setting ulBlockVariable to a non-zero value in the debugger will allow
	this function to be exited. */
	taskDISABLE_INTERRUPTS();
	{
		while( ulBlockVariable == 0UL )
		{
			__asm volatile( "NOP" );
		}
	}
	taskENABLE_INTERRUPTS();
}
/*-----------------------------------------------------------*/

/* Called by FreeRTOS+TCP when the network connects or disconnects.  Disconnect
events are only received if implemented in the MAC driver. */
void vApplicationIPNetworkEventHook( eIPCallbackEvent_t eNetworkEvent )
{
	uint32_t ulIPAddress, ulNetMask, ulGatewayAddress, ulDNSServerAddress;
	char cBuffer[ 16 ];
	static BaseType_t xTasksAlreadyCreated = pdFALSE;

	FreeRTOS_printf( ( "vApplicationIPNetworkEventHook: event %ld\n", eNetworkEvent ) );

	/* If the network has just come up...*/
	if( eNetworkEvent == eNetworkUp )
	{
		/* Create the tasks that use the IP stack if they have not already been
		created. */
		if( xTasksAlreadyCreated == pdFALSE )
		{
			/* Tasks that use the TCP/IP stack can be created here. */
			/* Let the server work task now it can now create the servers. */
			xTaskNotifyGive( xServerWorkTaskHandle );

			#if( mainCREATE_TCP_ECHO_CLIENT_TASKS_SINGLE == 1 )
			{
				vStartTCPEchoClientTasks_SingleTasks( mainECHO_CLIENT_TASK_STACK_SIZE, mainECHO_CLIENT_TASK_PRIORITY );
			}
			#endif

			#if( mainCREATE_SIMPLE_TCP_ECHO_SERVER == 1 )
			{
				vStartSimpleTCPServerTasks( mainECHO_SERVER_STACK_SIZE, mainECHO_SERVER_TASK_PRIORITY );
			}
			#endif

			/* Register example commands with the FreeRTOS+CLI command
			interpreter via the UDP port specified by the
			mainUDP_CLI_PORT_NUMBER constant.  If the HTTP or FTP servers are
			being created then file system related commands will also be
			registered from the TCP server task. */
			#if( mainCREATE_UDP_CLI_TASKS == 1 )
			{
				vRegisterSampleCLICommands();
				vRegisterTCPCLICommands();
				vStartUDPCommandInterpreterTask( mainUDP_CLI_TASK_STACK_SIZE, mainUDP_CLI_PORT_NUMBER, mainUDP_CLI_TASK_PRIORITY );
			}
			#endif
			
			xTaskCreate( vMBServerTask, "MBTask", mainMB_SERVER_STACK_SIZE, NULL, mainMB_TASK_PRIORITY, &xMBTaskHandle );

			xTasksAlreadyCreated = pdTRUE;
		}

		/* Print out the network configuration, which may have come from a DHCP
		server. */
		FreeRTOS_GetAddressConfiguration( &ulIPAddress, &ulNetMask, &ulGatewayAddress, &ulDNSServerAddress );
		FreeRTOS_inet_ntoa( ulIPAddress, cBuffer );
		FreeRTOS_printf( ( "IP Address: %s\n", cBuffer ) );

		FreeRTOS_inet_ntoa( ulNetMask, cBuffer );
		FreeRTOS_printf( ( "Subnet Mask: %s\n", cBuffer ) );

		FreeRTOS_inet_ntoa( ulGatewayAddress, cBuffer );
		FreeRTOS_printf( ( "Gateway Address: %s\n", cBuffer ) );

		FreeRTOS_inet_ntoa( ulDNSServerAddress, cBuffer );
		FreeRTOS_printf( ( "DNS Server Address: %s\n", cBuffer ) );
	}
}
/*-----------------------------------------------------------*/

UBaseType_t uxRand( void )
{
const uint32_t ulMultiplier = 0x015a4e35UL, ulIncrement = 1UL;

	/* Utility function to generate a pseudo random number. */

	ulNextRand = ( ulMultiplier * ulNextRand ) + ulIncrement;
	return( ( int ) ( ulNextRand >> 16UL ) & 0x7fffUL );
}
/*-----------------------------------------------------------*/

static void prvSRand( UBaseType_t ulSeed )
{
	/* Utility function to seed the pseudo random number generator. */
	ulNextRand = ulSeed;
}
/*-----------------------------------------------------------*/


const char *pcApplicationHostnameHook( void )
{
	/* Assign the name "rtosdemo" to this network node.  This function will be
	called during the DHCP: the machine will be registered with an IP address
	plus this name. */
	return mainHOST_NAME;
}
/*-----------------------------------------------------------*/

int Basic_stricmp( const char *pc1, const char *pc2 )
{
int iReturn = 0;

	while( *pc1 != 0x00 )
	{
		if( tolower( ( int ) *pc1 ) != tolower( ( int ) *pc2 ) )
		{
			iReturn = 1;
			break;
		}
		else
		{
			pc1++;
			pc2++;
		}
	}

	return iReturn;
}
/*-----------------------------------------------------------*/

BaseType_t xApplicationDNSQueryHook( const char *pcName )
{
BaseType_t xReturn;

	/* Determine if a name lookup is for this node.  Two names are given
	to this node: that returned by pcApplicationHostnameHook() and that set
	by mainDEVICE_NICK_NAME. */
	if( Basic_stricmp( pcName, pcApplicationHostnameHook() ) == 0 )
	{
		xReturn = pdPASS;
	}
	else if( Basic_stricmp( pcName, mainDEVICE_NICK_NAME ) == 0 )
	{
		xReturn = pdPASS;
	}
	else
	{
		xReturn = pdFAIL;
	}

	return xReturn;
}
/*-----------------------------------------------------------*/

uint32_t xGetRunTimeCounterValue( void )
{
static uint64_t ullHiresTime = 0; /* Is always 0? */

	return ( uint32_t ) ( ullGetHighResolutionTime() - ullHiresTime );
}
/*-----------------------------------------------------------*/

time_t FreeRTOS_time( time_t *pxTime )
{
	( void ) pxTime;
	return xTaskGetTickCount() / 1000 + 1425522441ul;
}
/*-----------------------------------------------------------*/

static void prvMiscInitialisation( void )
{
	/* Initilise the SAM system */
	prvSetupHardware();
	pmc_enable_periph_clk(ID_TC0);
	pmc_enable_periph_clk(ID_TC3);
	pmc_enable_periph_clk(ID_SMC);

	#ifdef CONF_BOARD_TWI0
	{
		pmc_enable_periph_clk(ID_TWI0);
	}
	#endif

	#ifdef CONF_BOARD_TWI1
	{
		pmc_enable_periph_clk(ID_TWI1);
	}
	#endif

	pmc_enable_periph_clk(ID_PIOA);
	pmc_enable_periph_clk(ID_PIOB);

	/* Start a TC timer to get a hi-precision time. */
	vStartHighResolutionTimer();

	/* Seed the pseudo random number generator. */
	prvSRand( ( uint32_t ) prvMiscInitialisation );
}
/*-----------------------------------------------------------*/

static void prvLEDTimerCallback( TimerHandle_t xTimer )
{
	/* Prevent compiler warnings about the unused parameter. */
	( void ) xTimer;

	/* An LED is toggle to show that something is alive. */
	ioport_toggle_pin_level( LED0_GPIO );
}
/*-----------------------------------------------------------*/

/* Keep the linker happy. */
int _write( int fd, char* buf, int nbytes )
{
	( void ) fd;
	( void ) buf;
	( void ) nbytes;

	return 0;
}
/*-----------------------------------------------------------*/

/* Keep the linker happy. */
int _read( int fd, char* buf, int nbytes )
{
	( void ) fd;
	( void ) buf;
	( void ) nbytes;

	return 0;
}
/*-----------------------------------------------------------*/

/* The prototype shows it is a naked function - in effect this is just an
assembly function. */
void HardFault_Handler( void ) __attribute__( ( naked ) );

void HardFault_Handler( void )
{
	 __asm volatile
	 (
	 " tst lr, #4                                                \n"
	 " ite eq                                                    \n"
	 " mrseq r0, msp                                             \n"
	 " mrsne r0, psp                                             \n"
	 " ldr r1, [r0, #24]                                         \n"
	 " ldr r2, handler2_address_const                            \n"
	 " bx r2                                                     \n"
	 " handler2_address_const: .word prvGetRegistersFromStack    \n"
	 );
}

void prvGetRegistersFromStack( uint32_t *pulFaultStackAddress )
{
	/* These are volatile to try and prevent the compiler/linker optimising them
	away as the variables never actually get used.  If the debugger won't show the
	values of the variables, make them global my moving their declaration outside
	of this function. */
	volatile uint32_t r0;
	volatile uint32_t r1;
	volatile uint32_t r2;
	volatile uint32_t r3;
	volatile uint32_t r12;
	volatile uint32_t lr; /* Link register. */
	volatile uint32_t pc; /* Program counter. */
	volatile uint32_t psr;/* Program status register. */

	r0 = pulFaultStackAddress[ 0 ];
	r1 = pulFaultStackAddress[ 1 ];
	r2 = pulFaultStackAddress[ 2 ];
	r3 = pulFaultStackAddress[ 3 ];

	r12 = pulFaultStackAddress[ 4 ];
	lr = pulFaultStackAddress[ 5 ];
	pc = pulFaultStackAddress[ 6 ];
	psr = pulFaultStackAddress[ 7 ];

	/* When the following line is hit, the variables contain the register values. */
	for( ;; );
}

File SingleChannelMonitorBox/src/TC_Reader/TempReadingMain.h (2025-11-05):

/*
 * TempReadingMain.h
 *
 * Created: 10/7/2022 5:59:50 PM
 *  Author: a00538665
 */ 


#ifndef TEMPREADINGMAIN_H_
#define TEMPREADINGMAIN_H_

/* FreeRTOS includes. */
#include "FreeRTOS.h"
#include "task.h"

#include "ioport.h"
#include "spi_master.h"
#include "spi.h"
#include "spi_mutex.h"
#include "conf_eth.h"
/* FreeRTOS+FAT includes. */
#include "ff_stdio.h"

#include "arm_math.h"
#include "mbport.h"
#include "mb.h"
#include "gpio.h"

#define TEMP_PROCESSOR_STACK_SIZE ( configMINIMAL_STACK_SIZE * 12 )

/** SPI settings. */
#define MAX31855K_SPI                                SPI
#define MAX31855K_CLOCK_SPEED                        5000000
#define MAX31855K_CS_PIN                             1		//This is the cs channel to use on atsam, there are 4 channels so 0-3
#define MAX31855K_CSN_GPIO							 SPI_NPCS1_PA9_GPIO
#define MAX31855K_CSN_FLAGS                          PIO_PERIPH_A | PIO_PULLUP | PIO_TYPE_PIO_OUTPUT_1

#define TEMP_SYSTEM_DIR				"/websrc/temperatureSystem.txt"
#define CELSIUS						 false
#define	FAHRENHEIT					 true

#define MAX_SIZE_OF_TEMP_SYSTEM_FILE 2


void initializeTCReader (void);
void deleteTCReader (void);
static void tempReadingProcessor( void *pvParameters );

eMBErrorCode applicationUpdateModbusReg( uint16_t data, USHORT usAddress);

uint16_t toCelsius(uint16_t number);
uint16_t toFahrenheit(uint16_t number);
void updateTempSystem(bool newSystem);
void readTemperatureSystem(bool * currentSystem);




#endif /* TEMPREADINGMAIN_H_ */

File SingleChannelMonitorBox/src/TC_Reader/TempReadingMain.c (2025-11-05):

/*
 * TempReadingMain.c
 *	Contains a task that grabs a temperature reading every half second from a MAX31855 chip. 
 *  It's compatible with Type K, J, N, T, S, R, and E Thermocouples
 * Created: 10/7/2022 5:58:01 PM
 *  Author: a00538665
 */ 

#include "TempReadingMain.h"


TaskHandle_t readingProcessorHandle = NULL;

QueueHandle_t displayQueue = NULL;
QueueHandle_t setpointMonitorQueue = NULL;
QueueHandle_t tempToDisplayTempSystemQueue = NULL;
QueueHandle_t displayToTempReaderTempSystemQueue = NULL;
QueueHandle_t tempToSPHandlerTempSystemQueue = NULL;
QueueHandle_t httpToTempReaderTempSystemQueue = NULL;

SemaphoreHandle_t updateGlobalTempSemaphore = NULL;
SemaphoreHandle_t tempConvertToFahrenheitSemaphore = NULL;
SemaphoreHandle_t tempConvertToCelsiusSemaphore = NULL;


static bool delete = false;
static bool delete_complete = false;

extern uint16_t current_temperature;

void update_temp_for_server(uint16_t new_temp)
{
	bool finished = false;
	if(updateGlobalTempSemaphore != NULL)
	{
		while(finished != true)
		{
			if( xSemaphoreTake( updateGlobalTempSemaphore, ( TickType_t ) 10 ) == pdTRUE )
			{
				current_temperature = new_temp;
				xSemaphoreGive( updateGlobalTempSemaphore );
				finished = true;
			}
			else
			{
				vTaskDelay(2); //wait a second before trying again
			}
		}
	}
}


/*************************************************/
// Initialize the SPI interface
// Setup temp reading task
/*************************************************/
void initializeTCReader ()
{
	displayQueue = xQueueCreate(1, sizeof(int16_t));
	setpointMonitorQueue = xQueueCreate(5, sizeof(uint16_t));
	displayToTempReaderTempSystemQueue = xQueueCreate(10, sizeof(bool));
	tempToDisplayTempSystemQueue = xQueueCreate(10, sizeof(bool));
	tempToSPHandlerTempSystemQueue = xQueueCreate(10, sizeof(bool));
	httpToTempReaderTempSystemQueue = xQueueCreate(10, sizeof(bool));
	updateGlobalTempSemaphore = xSemaphoreCreateMutex();
	tempConvertToFahrenheitSemaphore = xSemaphoreCreateMutex();
	tempConvertToCelsiusSemaphore = xSemaphoreCreateMutex();
	gpio_configure_pin(MAX31855K_CSN_GPIO, MAX31855K_CSN_FLAGS);
	xTaskCreate( tempReadingProcessor, "tempReadingProcessor", TEMP_PROCESSOR_STACK_SIZE, NULL, tskIDLE_PRIORITY, &readingProcessorHandle );
}

void deleteTCReader ()
{
	delete = true;
	while(delete_complete != true)
	{
		vTaskDelay(1);
	}
}

void updateModbusTempReg(uint16_t temperature)
{
	//write the new value to the temp holding register
	applicationUpdateModbusReg(temperature, TEMP_HOLDING_REG);
}

//Takes a number in Celsius and converts it to Fahrenheit
//Will round to the nearest whole number since decimals are not supported
uint16_t toFahrenheit(uint16_t number)
{
	bool finished = false;
	uint16_t returnValue = 0;
	if(tempConvertToFahrenheitSemaphore != NULL)
	{
		while(finished != true)
		{
			if( xSemaphoreTake( tempConvertToFahrenheitSemaphore, ( TickType_t ) 10 ) == pdTRUE )
			{
				float d = (float) (number);
				d *= 1.8;
				d += 32;
				uint16_t result = round(d);
				
				if (result > 0)
				{
					if (result < 999)
					{
						returnValue = result;
					}
					else
					{
						returnValue = 999;
					}
				}
				else
				{
					returnValue = 0;
				}
				xSemaphoreGive( tempConvertToFahrenheitSemaphore );
				finished = true;
			}
			else
			{
				vTaskDelay(2); //wait a second before trying again
			}
		}
	}
	return returnValue;
}

//Takes a number in fahrenheit and converts it to celsius
//Will round to the nearest whole number since decimals are not supported
uint16_t toCelsius(uint16_t number)
{
	bool finished = false;
	uint16_t returnValue = 0;
	if(tempConvertToCelsiusSemaphore != NULL)
	{
		while(finished != true)
		{
			if( xSemaphoreTake( tempConvertToCelsiusSemaphore, ( TickType_t ) 10 ) == pdTRUE )
			{
				float d = (float) (number - 32);
				d /= 1.8;
				uint16_t result = round(d);
				
				if (result > 0)
				{
					if (result < 999)
					{
						returnValue = result;
					}
					else
					{
						returnValue = 999;
					}
				}
				else
				{
					returnValue = 0;
				}
				xSemaphoreGive( tempConvertToCelsiusSemaphore );
				finished = true;
			}
			else
			{
				vTaskDelay(2); //wait a second before trying again
			}
		}
	}
	return returnValue;
}

// This function will publish a new temperature system setting (either fahrenheit or celsius
// The argument to supply is a bool but the defines for FAHRENHEIT or CELSIUS should be used
void updateTempSystem(bool newSystem)
{
	char buffer[MAX_SIZE_OF_TEMP_SYSTEM_FILE] = {'\0'};
	
	if (newSystem == CELSIUS)
	{
		buffer[0] = 'C';
	}
	else
	{
		buffer[0] = 'F';
	}
	
	FF_FILE * tempSystemFile = ff_fopen( TEMP_SYSTEM_DIR, "w" );
	
	if (tempSystemFile != NULL) //if this is NULL then the file system is probably broken
	{
		ff_fwrite(buffer, 1, MAX_SIZE_OF_TEMP_SYSTEM_FILE, tempSystemFile);
		ff_fclose(tempSystemFile);
	}
}

void readTemperatureSystem(bool * currentSystem)
{
	char buffer[MAX_SIZE_OF_TEMP_SYSTEM_FILE] = {'\0'};
	FF_FILE *tempSystemFile = ff_fopen( TEMP_SYSTEM_DIR, "r" );
	
	if(tempSystemFile != NULL) //this means the file exists so we should go ahead and read to see what system we are using
	{
		ff_fread(buffer, 1, MAX_SIZE_OF_TEMP_SYSTEM_FILE, tempSystemFile);
		if (buffer[0] == 'C')
		{
			*currentSystem = CELSIUS;
		}
		else
		{
			*currentSystem = FAHRENHEIT;
		}
		
		FF_Close(tempSystemFile);
		tempSystemFile = NULL;
	}
	else
	{
		updateTempSystem(CELSIUS);
		*currentSystem = CELSIUS;
	}
}
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

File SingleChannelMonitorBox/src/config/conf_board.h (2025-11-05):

/**
 * \file
 *
 * \brief Board configuration.
 *
 * Copyright (c) 2015-2018 Microchip Technology Inc. and its subsidiaries.
 *
 * \asf_license_start
 *
 * \page License
 *
 * Subject to your compliance with these terms, you may use Microchip
 * software and any derivatives exclusively with Microchip products.
 * It is your responsibility to comply with third party license terms applicable
 * to your use of third party software (including open source software) that
 * may accompany Microchip software.
 *
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
 * \asf_license_stop
 *
 */
/*
 * Support and FAQ: visit <a href="https://www.microchip.com/support/">Microchip Support</a>
 */

#ifndef CONF_BOARD_H_INCLUDED
#define CONF_BOARD_H_INCLUDED

#define USER_LED_PIN         LED_0_PIN
#define USER_LED_ACTIVE      LED_0_ACTIVE
#define USER_LED_INACTIVE    LED_0_INACTIVE
#define USER_LED_GPIO        LED0_GPIO

/** SPI MACRO definition */
#define CONF_BOARD_SPI

#define CONF_BOARD_SPI_NPCS0

#define CONF_BOARD_SD_MMC_HSMCI

#define SD_MMC_ENABLE

//#define CONF_BOARD_NAND
/** SPI slave select MACRO definition */
//#define CONF_BOARD_SPI_NPCS3
//#define CONF_BOARD_SPI_NPCS3_GPIO  SPI_NPCS3_PA5_GPIO
//#define CONF_BOARD_SPI_NPCS3_FLAGS SPI_NPCS3_PA5_FLAGS

#endif /* CONF_BOARD_H_INCLUDED */
